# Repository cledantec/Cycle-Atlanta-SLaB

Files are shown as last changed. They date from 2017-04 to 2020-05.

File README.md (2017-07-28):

Cycle Atlanta: Seeing Like a Bike
================
[Atlanta's Data Science for Social Good (DSSG) 2017](http://dssg-atl.io/)
----------

The Cycle Atlanta project aims to create sensor systems that allow a bike to "see" its environment and collect data as a participatory effort to help the City of Atlanta make informed decisions about biking infrastructures. The team from Atlanta's Data Science for Social Good 2017 Summer program particularly worked on (1) reverse engineering all the prototypes developed separately by the LMC6650 team and consolidating all sensors into two microcontoller units (Raspberry Pi and Arduino) using the Master-Slave architecture; (2) identifying hardware/software bugs/flaws and refining systems iteratively; (3) implementing failure-tolerence techniques; (4) classifying environmental factors (to detect semantci-level objects) after collecting data using GoPro, voice recorders, and sensors; and (5) visualizing and analyzing the collected data using 3D models and machine learning techniques. 

## Documentations
* [System Overview](DSSG2017_doc/overview.md)
* [Hardware Systems (Electrical Devices and Circuits)](DSSG2017_doc/hardware.md)
* [Software Systems (Server Configurations and Scripts)](DSSG2017_doc/software.md)
* [Cases Design](DSSG2017_doc/cases.md)
* [Data Visualization (3D)](DSSG2017_doc/dataviz.md)
* [Data Analysis](DSSG2017_doc/data.md)
* [Backlog (Issues and Solutions)](DSSG2017_doc/backlog.md)

## Credits (DSSG)
### PI:
* [Dr. Christopher Le Dantec](https://ledantec.net/)

### DSSG Fellows:
* [Javier Argota](http://jard.us)
* [Myeong Lee](http://myeonglee.com)
* [Noel Mannariat](mailto:noelmannariat@gmail.com)
* [Erica Pantoja](mailto:ericapantoja1190@gmail.com)

### Special Thanks To:
* Dr. Kari Watkins
* Mariam Asad
* Bijan Tehrani
* Raj Lal
* Michael Vogel
* Bradley Rittenhouse

******

## [LMC6650: Seeing Like a Bike](http://ledantec.net/teaching/lmc-6650-spring-2017/)
### Spring 2017 Georgia Tech

LMC6650 students designed a custom PCB board for gas sensors, developed the Air Quality module and a data collection server on Raspberry Pi using RestAPIs, and implemented the proximity/serface quality sensor functionalities using Rapsberry Pi and Arduino. 

## Equipment used
* [Raspberry Pi](http://raspberrypi.org)
* [Arduino Uno](https://www.arduino.cc/en/Main/arduinoBoardUno)
* [Matrix One Creator](http://creator.matrix.one)
* [Anker 26800 mAh portable power bank](https://www.amazon.com/Anker-PowerCore-Portable-Double-Speed-Recharging/dp/B01JIWQPMW)
* [Knowles BU21771 contact microphone](www.digikey.com/product-detail/en/knowles/BU-21771-000/423-1004-ND/458515)
* Dimension ST768 for 3D printing

## Credits (LMC6650)
* **Air Quality team**: [Orianna Ott](https://www.linkedin.com/in/orianaott/) , [Lorina Navarro](https://www.linkedin.com/in/lmnavarro/) , [Reuben Fishback](https://www.linkedin.com/in/reuben-fishback-a4b31085/)
* **Proximity team**: [Sharon Ang](https://www.linkedin.com/in/sharon-ang/) , [Aastha Jalan](https://www.linkedin.com/in/aasthajalan/) , [Nikhil Soraba](https://www.linkedin.com/in/nikhil-soraba/)
* **Surface Quality team**: [Nene Igietseme](https://www.linkedin.com/in/nene-igietseme-19b65125/) , [Kristin Hare](https://www.linkedin.com/in/kristin-hare/) , [Shruti Dalvi](https://www.linkedin.com/in/shruti-dalvi/) , [Jayanth Mohana Krishna](https://linkedin.com/in/jayanthm)

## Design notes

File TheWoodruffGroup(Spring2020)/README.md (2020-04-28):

# Capstone SLaB [The Woodruff Group]
Documentation for work completed by The Woodruff Group for Spring 2020 Capstone

The goal of this Capstone project was to improve upon previous iterations of a data collection system which could be utilized by 
researchers to collect data about a biker's environment and stress levels during bike riding trials. The current project is broken down into three main categories as listed below.

## [Android App](Android%20App)
The Android App was developed in order to take advantage of the large amount of data a mobile phone is capable of reporting about its surroundings and movement. The main goal of the app is to collect time-stamped location data, speed data, and IMU data. The collected information is then written to a text file stored on the phone. The text file can be accessed from a computer and further analyzed.

## [Mechanical System](Mechanical%20System)

## [Electrical System](Electrical%20System)
The electrical system includes the sensors and other electrical components used, as well as the PCB that connects them all. The primary electrical components are a battery, a current sensor, a Teensy microcontroller, 4 LIDARs, and a Bluetooth communication module.

## The Woodruff Group
[Ibrahim Abdeally - iabdeally3@gatech.edu](mailto:iabdeally3@gatech.edu)  
[JP Almagro - jpalmagro97@gmail.com](mailto:jpalmagro97@gmail.com)  
[Matthew Bowen - matthew.bowen90@gmail.com](mailto:matthew.bowen90@gmail.com)  
[Aditya Ramanathan - aramanathan31@gatech.edu](mailto:aramanathan31@gatech.edu)  
[Carrie Wehmeyer - weh.carrie@gmail.com](mailto:weh.carrie@gmail.com)  
[Andy Zheng - azheng36@gatech.edu](mailto:azheng36@gatech.edu)

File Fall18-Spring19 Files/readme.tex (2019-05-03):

This file contains instructions for how to run slabScriptV1.py and compileData.py, as well as an overview of the arduino scripts. 

Instructions for Downloading Raw Data:
1. Go to the SLaB oneDrive Folder, then go to the Raw Data folder.
2. There are a lot of folders in the raw data folder, each containing all data from a specific SLaB box up until the date in the folder's name. The boxes are differentiated by their place in the lab (L for left, C for center, and R for right).
3. Download as much raw data as you need, making sure not to mix up data from different sensors. 
4. Make sure the raw data and whichever script you are running are in the same folder. The two scripts are stored (along with this readme) in the Scripts onedrive folder.
5. Move on to instructions for how to run the scripts. 

slabScriptV2: 
This is a script that takes in up to two sets of raw data for a single run and creates up to two output files that contain the air quality data. 

Instructions:
   1. Change the runDate variable below to the data you are getting data from. This should match
      the data in the data files, though it's not a problem if you switch the month and day or make
     other necessary changes. IMPORTANT: there is no check in place to make sure you entered the corrent
      runDate. The script will happily let you pull data from 09-11-18 with a runDate of 09-10-18,
      creating an output file named 09-10-18 with the data from the 11th. 

   2. Enter the first and/or second input files in the fields: input_files_one and input_files_two. The correct
      format is: input_files_one = ['090119_gps_data.json', '090119_proximity.json','090119_imu.log','090119_sensor.log']
      for example. If you only want to input files from one SLaB box then comment out the other line of input files
      and uncomment the line input_files_two = [] right below it. If the input_files_two variable is an empty array
      the code will move past it. 

   3. Run the code. Remember to SAVE first. If you are running this code in sumblime text, go to the Tools menu and
      click Build. If you are running this code in the commandline, navigate to the correct folder and enter
      python slabScriptV2.py

   4. If the code runs successfully, the output should look something like:

            Compiling Data from 01-09-19
            one complete
            two complete (or two ommitted if you didn't include a second set of data)
            Success
            [Finished in 0.2s]

   5. Finally, check the output file(s) to make sure they are what you expect, given the raw data files from the SLaB
      boxes.

compileData.py
This script takes in a single set of raw data file for a single run and creates an output file containing all data in json format for import into the database. It is important to remember to check the output of this script before putting it in the database. 

Instructions:
  1. Change the runID variable below to the following format: MM-DD-YYYYRunID_sensorNumber. The RunID 
     should be the route abbreviation (IP, etc) and the run number. The sensor Number should correspond with 
     the box the data is pulled off of (right = 1, center = 2, left = 3). The date should match
     the date in the name of in the data files, though it's not a problem if you switch the month and day or make
     other necessary changes. IMPORTANT: there is no check in place to make sure you entered the correct
     runID. The script will happily let you pull data from a piedmont park run on 09-11-18 with senor 1 with a runID 
     of 09-10-18IP1_2, creating a misleading data file. Though the timestamps in the file will still have the 
     right date and the gps coordinates will be unchanged, there is no way to identify which sensor was used from the data.

  2. Enter each input file into the list called input_files, following the example:
      input_files = ['040219_gps_data.json', '040219_proximity.json','040219_imu.log','040219_sensor.log']
     The script should be in the same folder as all four files, and all files should be from the same date.
     IMPORTANT: there is no check in place making sure the input files are from the same date.

  3. Run the code. Remember to SAVE first. If you are running this code in sumblime text, go to the Tools menu and
     click Build. If you are running this code in the commandline, navigate to the correct folder and enter
     python compileData.py . This script takes a little longer to compile than slabScriptV1.

  4. If the code runs successfully, the output should look something like:

           Compiling Data from <runID>
           Compiling GPS Data
           Compiling PROX Data
           Compiling IMU Data
           Compiling Sensor Data
           Success
           [Finished in 5.0s]

  5. Finally, check the output file(s) to make sure they are what you expect, given the raw data files from the SLaB
     boxes. Be sure to give the script a moment to completely finish, which you'll know once the BAK file appears.
     If you see lots of '?' in the file, the script has not finished. Things to look for: the timestamps incrementing 
     properly and the correct data matching up to the correct timestamp

  Known Bugs:
      1. the second } after the last entry in each section of the data is sometimes on the wrong line - this happens because
      the script expects the last line in each file to be unreadable (the norm) but this is not always the case. 

      2. entries in the raw data files will sometimes be preceeded by lines of <0x00> (a break in the data) 
      if a line follows a break in the data (is on the same line) and will be skipped by the script because it can't process it

      3. rarely, the increment in the imu data will be slightly too large and result in two rows with duplicate timestamps
         duplicate timestamps. An eary fix is to use a json checker and shift the first of the duplicates down by .001 to .999.

Arduino Scripts:
 TwoPMSsOrig: allows the arduino to take data from two PM sensors and print it all out to the console in a readable manner
 
 arduinoAll: does the same thing, but works with the SLaB box. In the event that you're building a box from scratch, the arduino_receiver.py file needs to be updated to work with this script. The updated script can be found on all three SLaB boxes.
 
 arduinoAllFinished: the same script as above, but cleaned up and with some comments. I ran out of time to do a just-in-case test on it so I'm uploading this copy as well as the original.

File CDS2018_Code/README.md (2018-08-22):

Cycle Atlanta: Seeing Like a Bike
================
[Civic Data Science at Georgia Tech]()http://civicdatascience.gatech.edu/2018/06/01/seeing-like-a-bike-2/
----------

The Cycle Atlanta project aims to create sensor systems that allow a bike to "see" its environment and collect data as a participatory effort to help the City of Atlanta make informed decisions about biking infrastructures. In Summer 2018, the Civic Data Science summer program focused especially on the challenges of collecting high quality pollution data from a mobile platform such as a bike. We focused mainly on evaluating the performance of low-cost air quality sensors, specifically the PMS5003, and comparing the results with a high quality sensor, the GRIMM Portable Aerosol Spectrometer.

## Credits (CDS)
### PI:
* [Dr. Christopher Le Dantec](https://ledantec.net/)

### CDS Interns:
* [Saumik Narayanan](mailto:naray114@umn.edu)
* [Nic Alton](mailto:alton.nic@gmail.com)
* [Urvi Latnekar](mailto:urvi.latnekar@bennett.edu.in)

### Special Thanks To:
* Dr. Kari Watkins
* April Gadsby
* Kanaad Deodhar

******

## Equipment and Software used
* [Raspberry Pi](http://raspberrypi.org)
* [Arduino Uno](https://www.arduino.cc/en/Main/arduinoBoardUno)
* [PMS 5003](https://aqicn.org/sensor/pms5003-7003/)
* [GPS Logger](https://play.google.com/store/apps/details?id=eu.basicairdata.graziano.gpslogger&hl=en_US)

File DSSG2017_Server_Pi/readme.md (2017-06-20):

# SLaB Server & Data store

This component runs the server on a RasPi that accepts data streams from the rear box (proximity and air quality) and the Matrix mounted on the handle-bars.

Installation 
============

Copy all files in the RaspberryPi directory to the home directory of the Raspberry Pi. Install dependencies for the Matrix and Flask (see install.sh):

```
sudo apt-get install python python3 python-pip nodejs
sudo pip install flask
curl https://raw.githubusercontent.com/matrix-io/matrix-creator-quickstart/master/install.sh | sh
```

* We will be using the MALOS abstracted layer on Matrix, here: https://matrix-io.github.io/matrix-documentation/MALOS/overview/ 
* Python Flask runs as the server, and accepts a JSON payload
* The server automatically time-stamps POSTed data and appends the sensor name based on what endpoint was contacted.

To run:

```
sudo python -m <path>/server.python
```

Server endpoints
----------------
| **Endpoint**  | **HTTP Method** | **Data** |
|---|---|---|
| /getstatus | GET | Returns LED status |
| /status | POST | Gets various sensor statuses |
| /proximity | POST | Gets proximity data |
| /inertial | POST | Gets inertial data |
| /humidity | POST | Gets humidity data |
| /uvindex | POST | Gets ultraviolet data |
| /prestempalt | POST | Gets pressure, temperature, altitude data |
| /gas | POST | Gets gas array data |
| /gps | POST | Gets GPS data |

Data store
----------
Data received by the server is stored in this format:
```{
 ‘sensor’: ‘sensor_name’,
 ‘timestamp’: ‘YYYY-MM-DD HH:MM:SS.ssssss’,
 ‘data’: {sensor_payload}
 }
 ```

Future work
-----------
* Send data to MongoDB instead of plain text file (better size and filtering)
* Write services to retrieve data based on filters

Command-line Autostart and Auto Triggering of Shell Scripts
---------
- cd /etc/systemd/system/autologin@.service
- Change line: ExecStart=-/sbin/agetty --autologin pi --noclear %I $TERM
- Auto Triggering Shell Scripts
	- Comment out the line in “LXDE-pi” since it works for GUI mode ```sudo nano ~/.config/lxsession/LXDE/autostart```
	- In “/etc/rc.local”, put the line ```/home/pi/startup.sh @```

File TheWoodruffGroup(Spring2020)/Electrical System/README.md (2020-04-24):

# Electrical System Documentation
The electrical system includes the sensors and other electrical components used, as well as the PCB that connects them all. The electrical components include:
- 1x [Anker 5000 mAh Battery](https://www.anker.com/products/variant/powercore-5000/A1109011)
- 1x USB-A male-to-male cable
- 1x [Stewart Connector USB-A port](https://www.digikey.com/product-detail/en/stewart-connector/SS-52100-001/380-1412-ND/7902377)
- 1x On/Off Switch
- 1x Current Sensor
- 1x [Teensy 4.0 Microcontroller](https://www.pjrc.com/store/teensy40.html)
- 4x [Garmin LIDAR-Lite v4 LEDs](https://buy.garmin.com/en-US/US/p/610275)
- 1x [Adafruit Bluefruit UART Friend](https://www.adafruit.com/product/2479)
- 2x 1.5 kΩ (pull-up) resistors
- 1x 680 μF capacitor

The current PCB was designed in Eagle 9.6.1. Since Georgia Tech's [Electronics Lab](http://www.me.gatech.edu/facilities/electronic_lab) uses Eagle, PCBs can typically be manufactured within a day of the request if Eagle \*.brd files are submitted. For information on PCB design, I recommend [this tutorial by Brian Benchoff at Hackaday](https://hackaday.com/2016/09/22/making-a-pcb-eagle-part-1/). 

## Overview of Components
### Anker 5000 mAh Battery
This battery provides power to the Teensy and all of the components; it was sized based on the estimated current consumption of the device. It was calculated that the system will draw about 442 mA of current (2 mA from Bluetooth, 85 mA from each LIDAR, 100 from Teensy), so for a half-hour ride, only 221 mAh would be needed. Anker's 5000 mAh model was selected as the smallest and cheapest option, but other options may also be viable. The battery comes with a Micro-USB cable included for charging, but the micro-USB ports that I could find all seemed too small to easily solder to a PCB, so the board has a USB-A ("normal" USB) port instead, which are easier to solder, and still cheap & easy to find. Although the Teensy has a micro-USB port on it for power, connecting directly to this would make it impossible to measure the current draw, as the current sensor must be placed in series with the power source, so power must be provided through a separate USB port. 
The battery has a minimum current draw of 50 mA. We believe that the system will draw more than that, but **this would need to be verified experimentally**. 

### USB-A male-to-male cable
Since the board uses a USB-A port, a separate USB cable must be purchased to connect the battery to the board. A smaller cable would likely be best to prevent tangling. 

### Stewart Connector USB-A port
A USB-A port was chosen instead of a Micro-USB port because they appeared to be much easier to solder to a board, but any type of USB port should work, likely requiring changes to the footprint in the PCB file. This specific port was chosen because it was the cheapest one I could find on Digi-Key, but again, any USB port should work. 
The datasheet for this part did not specify which pin corresponded to what signal, so it had to be extrapolated based on similar connectors. **It needs to be verified experimentally which pin corresponds to 5V and which pin corresponds to ground**. 

### On/Off Switch 
This is a simple power switch to turn the device on or off, so that the battery power can be conserved when not in use. Any switch that holds its state and has leads attached to it can be used. Something like [this](https://www.adafruit.com/product/1092) would be fine, but the possibility of accidentally toggling the switch should be considered too, so a sliding switch might be better. The switch itself would be on the housing, and the leads coming off it would be soldered to the board. 

### Current Sensor 
The current sensor is used to estimate the current battery level by numerically integrating the current consumed over time. We never had the opportunity to test the current sensor, so everything involving it is entirely theoretical, including the wiring. The one used in the PCB is [this one from Allegro MicroSystems](https://www.digikey.com/product-detail/en/allegro-microsystems/ACS750LCA-050/ACS750LCA-050-ND/1006488), a default option provided in Eagle, which is now discontinued. It appears to have the same footprint as [this one](https://www.digikey.com/product-detail/en/allegro-microsystems/ACS770LCB-050B-PFF-T/620-1541-5-ND/4473980), which is still active. These current sensors may be bigger than we need, as they can sense up to 50 A of current, and the voltage outputted from them might be too low to be accurately read by the Teensy. **It may be better to use a different current sensor that is more suited to the range of currents being measured, and if the voltage is still too low, it may be best to amplify it with an op-amp.** It is also possible to calculate current by placing a small known resistor in series with the power source, where the current sensor would go, and measuring the voltage across it, but it is unclear how accurate this would be, and how much this would change the dynamics of the circuit. 

### Teensy 4.0 Microcontroller
This is the microcontroller that manages all of the sensors. It is faster and more powerful than an Arduino Uno, and should be fast enough to handle all the data being gathered. User-made Eagle libraries for the Teensy can be found [here](https://www.pjrc.com/teensy/eagle_lib.html), and the one used in this design is [the one by Constantin](https://forum.pjrc.com/threads/935-Eagle-library-with-Teensy-3-0-footprint?p=20178&viewfull=1#post20178) ("Teensy_3_and_LC_Series_Boards_v1.4.zip"). The Teensy 4.0 has largely the same pinout as the Teensy 3.2 and 3.1, so the Teensy 3.2/3.1 board available in the library is the footprint used in this design. The pins that are used all seem to be the same between 4.0 and 3.2, but **the wiring should be verified experimentally**. 

### Garmin LIDAR-Lite v4 LED
The LIDAR is used to measure the distance to various objects in the environment. Using multiple LIDARs, the speed of passing objects can be calculated. If two LIDARs are placed facing to one side of the bike with a known distance offset in the direction of motion, then the lag between the signals that the two LIDARs read can be used to calculate the speed of the passing object relative to the speed of the bike. This lag can be calculated with cross correlation, with the MATLAB function [xcorr()](https://www.mathworks.com/help/matlab/ref/xcorr.html), or the NumPy function [np.correlate()](https://numpy.org/doc/1.18/reference/generated/numpy.correlate.html), The distance between the LIDARs divided by the time lag between the signals is the speed of the passing object, relative to the bike. With an accurate measurement of the bike speed, coming from the app, the speed of the passing object relative to the ground can be calculated. Tests were done with the previous iteration of this device, [the v3](https://buy.garmin.com/en-US/US/p/557294), and it did not seem to be accurate enough, although only one device was tested. Regardless, it was decided to use the v4 because, according to the specs, it is more accurate, cheaper, and uses less power than its predecessor, however no tests could be done with it. The LIDARs communicate via I2C, and each one needs a different I2C address for proper communication. This can be done programatically with the [LIDAR-Lite Arduino Library](https://github.com/garmin/LIDARLite_Arduino_Library). The wiring was done based on their [specs sheet](http://static.garmin.com/pumac/LIDAR-Lite%20LED%20v4%20Instructions_EN-US.pdf) and comments in their example code, including the two resistors and the capacitor, so **it all needs to be verified experimentally**. 

### Adafruit Bluefruit UART Friend
This is the Bluetooth communication module that establishes a connection with the phone to send LIDAR data. It is not currently in the PCB as we had difficulties with reliably sending/receiving data. **Much more testing needs to be done with Bluetooth.** This device uses the Bluetooth Low Energy protocol, which is distinct from conventional Bluetooth. All the necessary information for this device can be found at the link above. 

## PCB design info
### PCB Files
There are 3 custom library files (\*.lbr) included in this folder: one for the LIDAR, one for the USB, and one for the Teensy. The Teensy library is the one mentioned above, and the other two are simple ones that I made, as I couldn't find EAGLE files for them online. The .brd file is the PCB layout, the .sch file is the schematic, and the .step file is a 3D model used in the CAD. 
### LIDAR Connection
The LIDAR footprint is just 10 holes in two rows spaced 0.1" apart, since the LIDAR itself doesn't have any method of connecting to a board. A port like [this](https://flytron.com/connectorscables/254-10-pin-isp-male-connector-header.html) could be soldered on, and then a ribbon cable soldered to the LIDAR with a plug on the other side could be used to easily connect to the board.

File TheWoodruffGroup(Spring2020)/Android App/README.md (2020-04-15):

# Android App
The Android app is responsible for collecting location data, speed, and other phone sensor data. Several methods of obtaining a 
phone’s location were tested. For Android devices, the two main ways of obtaining device location are through using 
Android Location Manager (ALM) or Google Play Services’ Fused Location Client (FLC). ALM utilizes GPS, network providers, and 
passive providers. This includes using satellites, cell towers, and locations determined by other applications. FLC is built on 
top of ALM. FLC automatically chooses the best provider for the device’s location and is in turn much quicker to update and log a 
device’s location. Comparing the two, FLC provided more accurate data with less lag. The current app utilizes FLC to report the 
phone's location and speed. The app has been tested on a Samsung Galaxy S10 and is currently named "SLaB".

The app features two modes which both record data. The main screen is meant to be utilized during experiments and test rides. This
screen displays the essentials for the app:
- Data Logging Status: Reports whether the app is currently able to write data to a text file.
- Audio Recording Switch: Switch to enable or disable optional audio recording. Must be set before logging data.
- Button Counter: Senses when the volume-up button is pressed.
- Relevant Location Data: Displays time, latitude, longitude, speed(mph), and altitude(ft).
- Counter: Counts the number of data points that have been recorded. Used to determine if data is being written to text file.
- Log Data Button: Large button pressed to being data logging. Disables audio recording switch and developer mode button.
- Developer Mode Button: Text that shows developer mode when pressed.

Developer mode has the same functionalities as the main screen but displays all data that is recorded. This extra data includes:
- Gyro Data
- Accelerometer Data
- File location
- Location accuracy data

While the main screen does not display these, they are still recorded and written to the stored text file.

## Build Environment
- The current app was developed using Android Studio 3.5.3. 
- The app has been tested on a Samsung Galaxy S10 with Android verison 10.
- Compile SDK version: 29
- Build Tools version: 29.0.3
- Application Min SDK version: 15
- Application Target SDK version: 29
- Application ID: "com.woodruff.SLaB"

## Dependencies
- implementation 'com.google.android.gms:play-services-games:19.0.0'
- implementation 'com.google.android.gms:play-services-location:17.0.0'

## Permissions
- "android.permission.BLUETOOTH"
- "android.permission.BLUETOOTH_ADMIN"
- "android.permission.INTERNET"
- "android.permission.ACCESS_FINE_LOCATION"
- "android.permission.ACCESS_COARSE_LOCATION"
- "android.permission.RECORD_AUDIO"

## Data Collected
Currently, the data collected includes:
- GPS Location - Longitude and latitude coordinates
- GPS Speed - Speed data as reported by the phone GPS, currently in mph
- GPS Altitude - Altitude data as reported by the phone GPS, currently in ft above the WGS 84 reference ellipsoid
- Accelerometer Data - Acceleration force in x, y, and z directions, currently in m/s<sup>2</sup>
- Gyroscope Data - Rate of rotation around x, y, and z axes, currently in rad/s
- Location Accuracy - Estimated horizontal accuracy of the location reported, currently in ft radially
- Speed Accuracy - Estimated speed accuracy as reported by the phone, currently in mph
- Altitude Accuracy - Estimated accuracy of the altitude reported, currently in ft
- Time - The time at which each data point was collected [yyyy-MM-ddTHH:mm:ss.SSS]

## File Location and Data Storage Format 
### File Location
The data collected by the app is written to a text file that is time stamped for when the file is created, or when data collection began.
Currently, the files are stored on the phone within the app's data folder in internal storage. To access the files, the "MyFiles" app on an Android phone 
can be used, or the phone can be connected to a computer and the file opened on a computer.

The files is located at: **Interal storage\Android\data\com.woodruff.SLaB**. Within the files folder, there are two folders for 
which data collected on the main mode and debug mode are stored. The folder "FLC Trip Data" contains data collected on the main screen,
while the folder "FLC Trip Data_Debug" contains data collected while in developer mode. Optional audio recordings are also stored
in these folders depending on which screen they are recorded from.

### Data Format in File
The data log file is a .txt file. The first line of the text file is a header which describes what data is collected and in what 
order the data is written to the text file. The data is comma-delimited, with each data point being time-stamped. Currently, 
the format is (Time,Latitude,Longitude,Dist_Acc,Speed,Speed_Acc,Altitude,Alt_Acc,Gyro_X,Gryo_Y,Gyro_Z,Accel_X,Accel_Y,Accel_Z).
The optional recordings are stored as mpeg4.

## Bluetooth
Initial testing was done to determine if Bluetooth(BT) could be used to send data between a BT module and a phone. The app created for testing is named "Blueteeth GATT". The BT module used for testing was the [Adafruit Bluefruit LE UART Friend](https://www.adafruit.com/product/2479). This BT module utilizes [Bluetooth Low Energy](https://developer.android.com/guide/topics/connectivity/bluetooth-le) instead of conventional Bluetooth. This involves using a GATT profile to send attributes over a BLE link. 

### Connecting Devices
Normally, the app would need to scan for BLE devices, pair, and connect before sending data. However, for the current app, the module is manually linked in the phone's BT settings before testing. 

### Bluetooth Adapter
A Bluetooth Adapter is required for BLE activity. In the main activity:

`private BluetoothAdapter bluetoothAdapter;`  

And within the onCreate method:

`bluetoothAdapter = bluetoothManager.getAdapter();`

Then app checks that Bluetooth is enabled and that a connection with the BLE module is established. If not, a request should be made for the user to enable BT and connect to the BT module: 

```
if (bluetoothAdapter == null || !bluetoothAdapter.isEnabled()) {
    Intent enableBtIntent = new Intent(BluetoothAdapter.ACTION_REQUEST_ENABLE);
    startActivityForResult(enableBtIntent, 0);
}
```

### GATT Connection
Next, the app checks that the correct module is connected. If the module is the "Adafruit Bluefruit LE" module, a connection is made to the GATT server on the BLE device and a [BluetoothGattCallback](https://developer.android.com/reference/android/bluetooth/BluetoothGattCallback) is used to perform operations:

```
pairedDevices = bluetoothAdapter.getBondedDevices();
if (pairedDevices.size() > 0) {
    for (BluetoothDevice device : pairedDevices) {
        if(device.getName().equals("Adafruit Bluefruit LE")){
            statusBox.setText(device.getName());
            BluetoothGatt BTGatt = device.connectGatt(this, true, gattCallback);
        }
        else{
            statusBox.setText("Plz Connect to Bluefruit");
        }
    }
}
else{
    statusBox.setText("No Connected Devices");
}
```

### Bluetooth GATT Callback
The GATT callback uses several methods to perform BT operations. The `onConnectionStateChange()` method can be used to check that a successful GATT connection was made and start discovering services:

```
public void onConnectionStateChange(BluetoothGatt gatt, int status, int newState) {
super.onConnectionStateChange(gatt, status, newState);
if(status == BluetoothGatt.GATT_SUCCESS && newState == BluetoothProfile.STATE_CONNECTED){
    try {
        Thread.sleep(500);
    } catch (InterruptedException e) {
        e.printStackTrace();
    }
    gatt.discoverServices();
}else if(status != BluetoothGatt.GATT_SUCCESS){
    gatt.disconnect();
}
}
```

Sometimes it is useful to have the thread sleep for 500 ms before beginning service discovery to ensure the GATT connection is made.

The `onServicesDiscovered()` method can be used to get the service from the BLE device as well as read and write characteristics using from the service. The service, read characteristic, and write characteristic have different UUIDs that are specific to the BLE module. These UUIDs are used to get the correct service and characteristic in order to communicate and perform operations with the BLE module:

```
BluetoothGattService BTservice = gatt.getService(UUID.fromString("6e400001-b5a3-f393-e0a9-e50e24dcca9e"));
BluetoothGattCharacteristic WriteCharacteristic = BTservice.getCharacteristic(UUID.fromString("6e400002-b5a3-f393-e0a9-e50e24dcca9e"));
BluetoothGattCharacteristic ReadCharacteristic = BTservice.getCharacteristic(UUID.fromString("6e400003-b5a3-f393-e0a9-e50e24dcca9e"));
```

To **send data to** the BLE module, the value of the write characterstic can be set and then written:

```
WriteCharacteristic.setValue("ASDFJKL");
gatt.writeCharacteristic(WriteCharacteristic);
```

To **receive data from** the BLE module, a characterstic notification must be set and enabled with the Bluetooth Descriptor:

```
gatt.setCharacteristicNotification(ReadCharacteristic,true);
BluetoothGattDescriptor descriptor = ReadCharacteristic.getDescriptor(UUID.fromString("00002902-0000-1000-8000-00805f9b34fb"));
descriptor.setValue(BluetoothGattDescriptor.ENABLE_NOTIFICATION_VALUE);
gatt.writeDescriptor(descriptor);
```

With the notification set, once a characteristic change is detected, the `onCharacteristicChange` method will be called. The incoming data can then be extracted and displayed or saved. 

```
public void onCharacteristicChanged(BluetoothGatt gatt, BluetoothGattCharacteristic characteristic){
  String inputText = characteristic.getStringValue(0);
 }
```

## Running the App
### Enabling USB Debugging
In order for the app to install on an adroid device from Android Studio, USB debugging must be enabled in the developer options on the phone. Normally, developer options are not shown. 

- If using an Android phone, go to Settings > About phone > Build number. 
- On a Samsung Galaxy device, go to Settings > About phone > Software information > Build number. 
- On an HTC device, go to Settings > About > Software information > More > Build number. 
- On an LG device, go to Settings > About phone > Software info > Build number.

Tap Build number seven times. After a few taps, steps counting down until developer options are unlocked should appear. Once activated, go back to Settings and developer options should be at the bottom of the menu. Under "Debugging" in the developer options, enable "USB debugging".

### Installing the App
To install the app on an Android device, connect the android device to a computer with Android studio running. If the device is connected and developer mode is enabled, the phone should show in a tool bar at the top of Android studio.



Simple click the green "Run" button to install the app on the phone.

### Enabling Permissions
To run the "SLaB app, location and mircophone permissons must be granted for the app. These can granted in the phone settings under apps. For the "Blueteeth GATT" app, make sure Bluetooth for the phone is enabled and the correct Bluetooth module is connected.

### Using the App
Once permissions are granted, the app should be functional. 
- To record data, simple press the "LOG DATA" button. 
- To enable audio recordings, switch the "Audio Record" to the on position before starting data collection. 
- To enter developer mode, press the text at the bottom. 
- To go back to the main screen from developer mode, use the back arrow at the top of the screen.

## Future Work
Future work for the app should focus on integrating Bluetooth functionality into the main "SLaB" app.

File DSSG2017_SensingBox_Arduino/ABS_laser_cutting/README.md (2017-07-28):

# ABS laser cutting

The files in this folder have no border. They are intended for being used directly for laser-cutting the ABS boxes. The box should be placed on the laser cutter bed with the face to be cut facing up, and with the opening facing right. The location of the box should be always on the top leftmost corner of the laser cutter. The file is set for being using the setting of 12 x 18 inches paper on the printer dialog from Illustrator. For getting the versions with the edges used for wooden cut, they are available in the folder “old”. The parameters of the cutting and engraving can change as the laser cutter has some sort of inconsistent behaviour. As general approach, for ABS, it is better several (around 10) quick passes which rather than a slow and powerful laser which can melt and damage the box. Engraving is only necessary in the front part. A test file is provided for checking different patterns on the ABS.

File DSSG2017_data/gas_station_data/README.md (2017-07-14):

Gas Station Data for Sensor Calibraition
=========
Myeong Lee (myeong@umd.edu)
-----

This data is collected at the Atlanta Sensing Station located at the Atlanta Power by co-locating our sensors.
The timestamps of the data are not correct since we used Linux time in Raspberry Pi. The actual time range that the data was collected is from July 12th 8:50 AM to July 14th 8:20 AM (approximately). The data was collected every 2 seconds in the code, but it is not exactly 2 seconds due to the data collection time lag (so a bit more than 2 sec), so the time interval in the data timestamp can be 2 or 3 seconds (but their actual intervals are same). 

The sensors needs to be calibrated using official sensor data from the sensing station. Also, temperature and humidity needs to be taken into account since these factors affect gas sensor readings. The official data is provided by Raj Lal, a Ph.D. student from the department of Environmental Science.

For the calibration data collection, we used only three sensor boards (#1, 4, 7), since these are only sensors that showed stable signals out of all the fabricated sensors (so, each entry in the dataset shows three sets of sensory data). The rest of the sensors that were not placed for calibration needs to be further debugged or replaced.

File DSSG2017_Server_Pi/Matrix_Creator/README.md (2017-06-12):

# Matrix Creator Files

These files are running on Raspberry PI to run sensors on the Matrix board.

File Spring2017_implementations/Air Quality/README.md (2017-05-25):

# Air Quality & GPS Sensor readme

Code for running air quality and GPS sensors. 

Installation 
============

Copy all files in the RaspberryPi directory to the home directory of the Raspberry Pi.
Install the Adafruit Python DHT and ADS1x15 libraries in the 'dependencies' directory (see README there for details—you will need an active network connection to install their dependencies).

To run:

```
sudo python ~/air_quaility/aq_init.py
```
To autorun, edit the ~/.config/lxsession/LXDE-pi/autostart file by adding:

```
@python /home/pi/airquality/aq_init.py
```

Old Code
--------
Located in the 'unused' directory, these source files aren't used or were renamed for production.

*AirMaster.py*
Contains all the relevant code from the other three python scripts.
It also connects to the server and sends JSON data every 4-5 seconds.

The following three files are test scripts
Once each was working the code was added to AirMaster.py

*USBserial.py*
This script will initialize and read from the USB port.

*serial_read.py* 
This script will read from the GPS that is connected to the tx and rx 
lines. It also isolates the desirable data and parses it out.

*i2c.py*
This code will use the Adafruit Python DHT library to read i2c.
It will also scale the values in an attempt to convert them to ppm.

*DustSensor.ino* 
This is arduino code that runs on the teensy arduino.
Reads analog value from PM sensor every second and sends over USB

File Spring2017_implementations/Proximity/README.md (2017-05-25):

# Raspberry Pi code

Python code for collecting proximity data, storing on the drive and sending status,data over the network.

Installation 
============

Copy all files in the RaspberryPi directory to the home directory of the Raspberry Pi.
Note: Include all the other files in the folder (the lidar_lite module) for the script to run successfully.

To run:

```
sudo python ~/proximity/proximity_init.py
```
To autorun, edit the ~/.config/lxsession/LXDE-pi/autostart file by adding:

```
@python /home/pi/proximity/proximity_init.py
```

# Arduino code

Refer to sensorAggregate.ino under Arduino folder. This will run all four sensors (2x Lidar Lite, 2x ultra-sound).

# Data Analysis

For a sample analysis of proximity data, run the file giveSummary.py from the directory where the data files are stored. By default, this path is /home/pi/data/
*Note: may not work as data file format has changed (from flat csv to json).*

Typical ouput expected is:

*Trip 1 Summary*
Number of parked cars: 0
Number of parked trucks:0
Approx. number of pedestrians / other short obstacles: 0

*Trip 2 Summary*
Number of parked cars: 6
Number of parked trucks:1
Approx. number of pedestrians / other short obstacles: 50

*Trip 3 Summary*
Number of parked cars: 14
Number of parked trucks:3
Approx. number of pedestrians / other short obstacles: 86

*Trip 4 Summary*
Number of parked cars: 12
Number of parked trucks:2
Approx. number of pedestrians / other short obstacles: 97

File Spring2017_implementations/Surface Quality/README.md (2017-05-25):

# Surface Quality Sensor readme

Code for running surface and environmental sensors from the Matrix.

Installation
============
Copy all files in the RaspberryPi directory to the home directory of the Raspberry Pi. Follow installation instruction of the Server—this runs on the same mdule.

To run:

```
node test_imu_server & node test_humidity_server & node test_pressure_server & node test_uv_server & node test_everloop_server
```

For auto start, edit thee ~.config/lxsession/LXDE-pi/autostart file to include: 

```
@bash /home/pi/startup.sh
```

Note: startup.sh also starts the Server.

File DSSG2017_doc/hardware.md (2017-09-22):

Hardware Systems
=======
### <span style="color:grey">Table of Contents</span>

1. [Securing Raspberry Pi and Matrix](#matrix)
2. [GPS](#gps)
3. [Pi-to-Arduino Communication](#commo)
4. [Arduino and Sensor Connections (Bridge Board)](#arduino)
5. [Gas Sensors](#gas)
6. [Sensor Box Design](#box)

## Securing Rapspberry Pi and Matrix
Even though the connection between Pi and the Matrix board is sturdy, Matrix Creator can be detached from the Pi board when shaking a lot during the riding. This led us to secure the Matrix board by tying them through Matrix holes. We used two pieces of wires to secure them. Also, to prevent the shocks between the Pi board and the Matrix board, we put a small piece of Yoga matt between them. Several tests showed that this is a very secure way to make them safely operate. 

## GPS Fabrication
Our GPS system consists of a GTPA010 device, a CP2102 USB-to-TTL device, and a small piece of PCB board. As you can see in the picture below, we connected the GPS module to the CP2102 device directly, and used a piece of PCB board as an intermediate bridge. This unit is finally attached to Pi's USB port. 

The reason that we do this is that while the GPS module uses a serial communication as a means to talk to other devices, the USB port of the Pi board is *NOT* a serial port. So, it is necessary to convert "serial communication" signals to TTL (Transistor-Transistor-Logic) signals that USB ports use. The software part for making use of this GPS module is available at [the software system document](software.md).

It is easy to make mistakes when connecting the pins and it is so hard to unsold them especially when you have already finished it, so pay attention to the connection during all the time of soldering. 

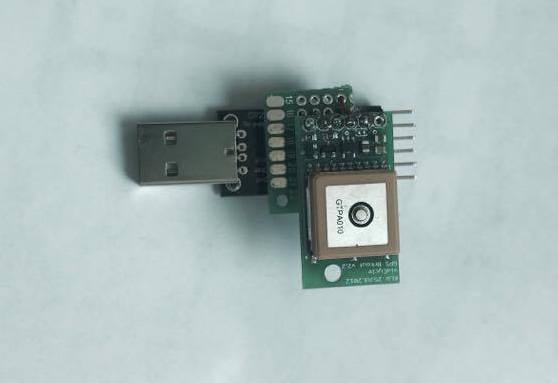
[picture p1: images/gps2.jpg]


The **connections of pins** are as follows. Please note that GTPA010 **DOES NOT** use 5V for VDD, but use 3.3V that comes out of a small pin in the CP2102 device. 

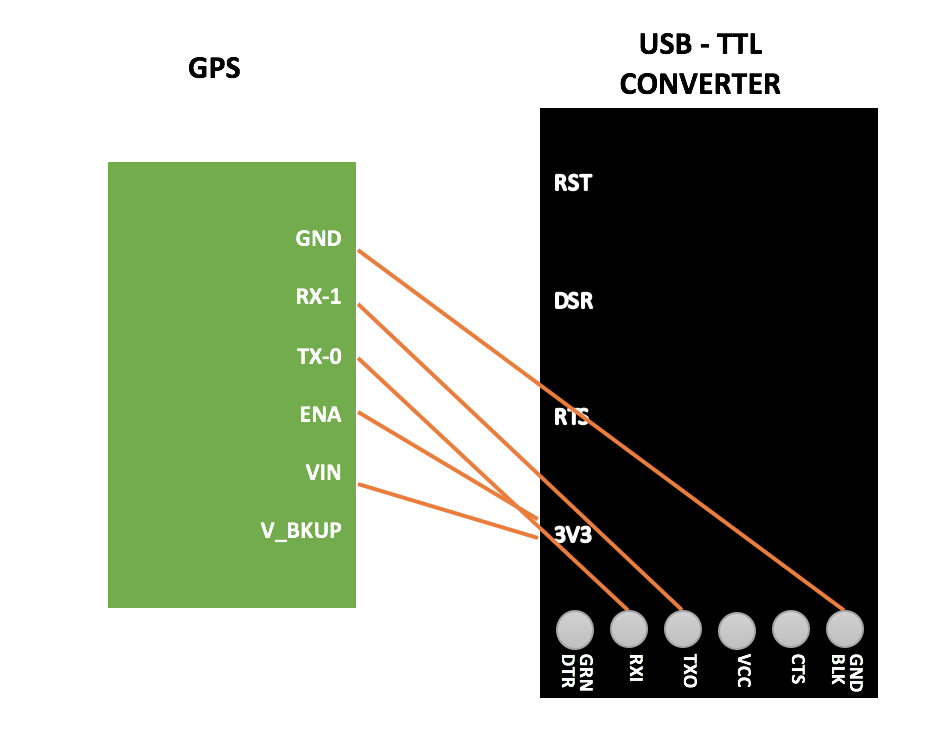
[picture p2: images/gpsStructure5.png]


The code uses the default settings of the GPS and returns the following data: **course**, **longitude**, **latitude**, **speed**, **day**, and, **utc_time**

## Pi-to-Arduino Communication
From the outside view, the Master Unit, particularly the Raspberry Pi, and the sensor box are connected through a male-to-male USB cable. Similar to the GPS module, however, the Pi uses a TTL signal for its USB while the Arduino board uses serial signals. So there is another USB-to-TTL device inside the sensor box on the back side. The brand of this USB-to-TTL device is different from the GPS one. Arduino's serial data swings between 0V to 5V while TTL signals swing between 0V and 3.3V. The USB-to-TTL device in the sensor box automatically deals with this power change. However, we do not use VDD between the Pi and Arduino since each of them uses its own power for data signals. Thus, only three wires, i.e., TX, RX, and GND, are connected through the USB-to-TTL device. 

**Note that TX from the USB-to-TTL device is connected to the RX of Arduino, and vice versa.**

## Arduino and Sensor Connections (Bridge Board)
From the hardware perspective, the connections of the sensors to the Arduino board is made through a shield/bridge-board mounted on top of the Arduino.

The documentation for the wiring of the box has been designed using Fritzing, common software in the Arduino and Raspberry Pi community. It can be downloaded for free from [its website](http://fritzing.org/home/). Additional parts libraries may be required depending on the particular version of the program, but they can be add *ad hoc* from the own program. It is particularly important for being able to use LIDAR or thrid-party components not that common for Arduino users.

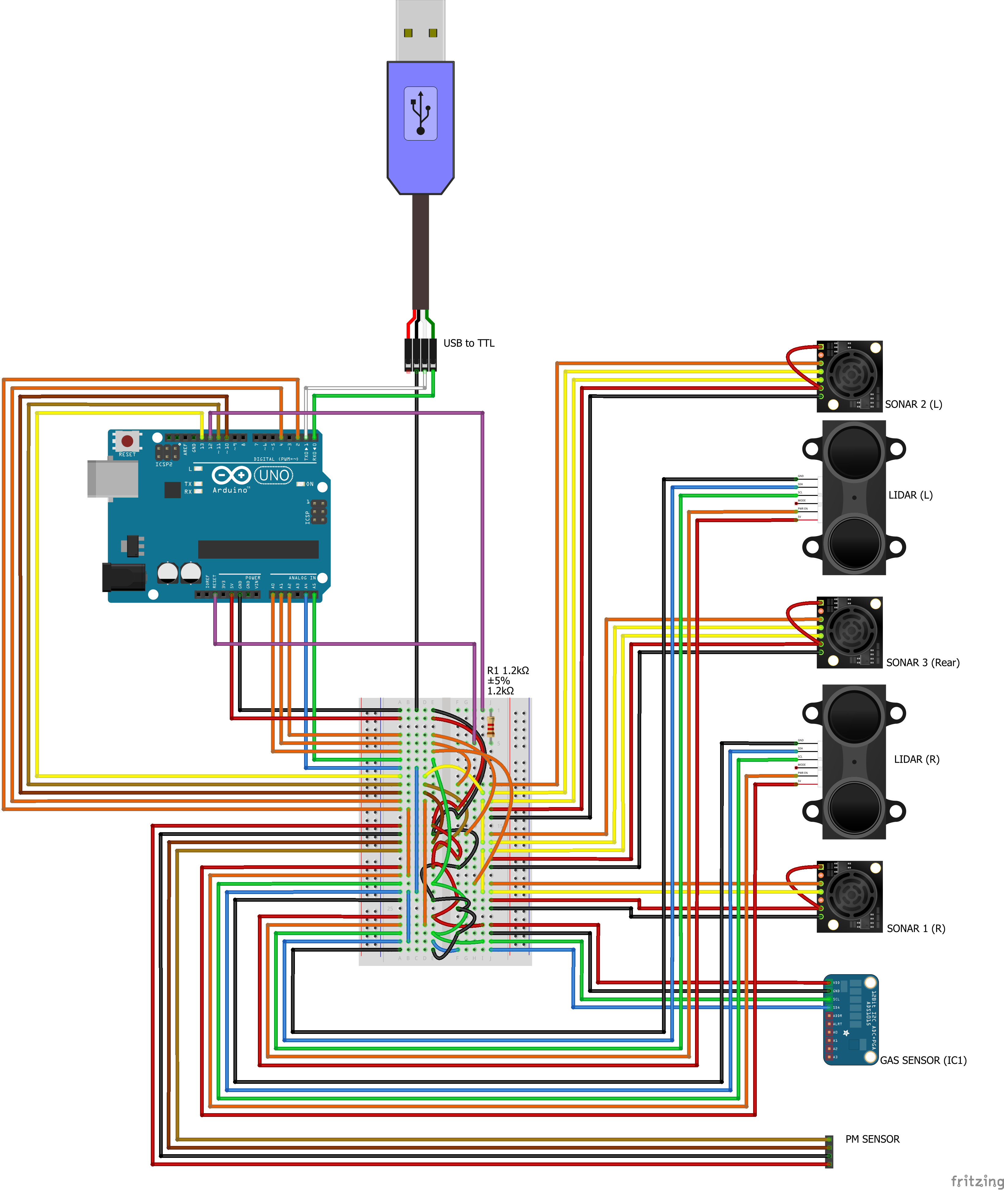
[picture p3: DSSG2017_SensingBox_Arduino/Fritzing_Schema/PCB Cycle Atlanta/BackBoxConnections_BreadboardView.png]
BreadboardView

*Breadboard view of the connections*

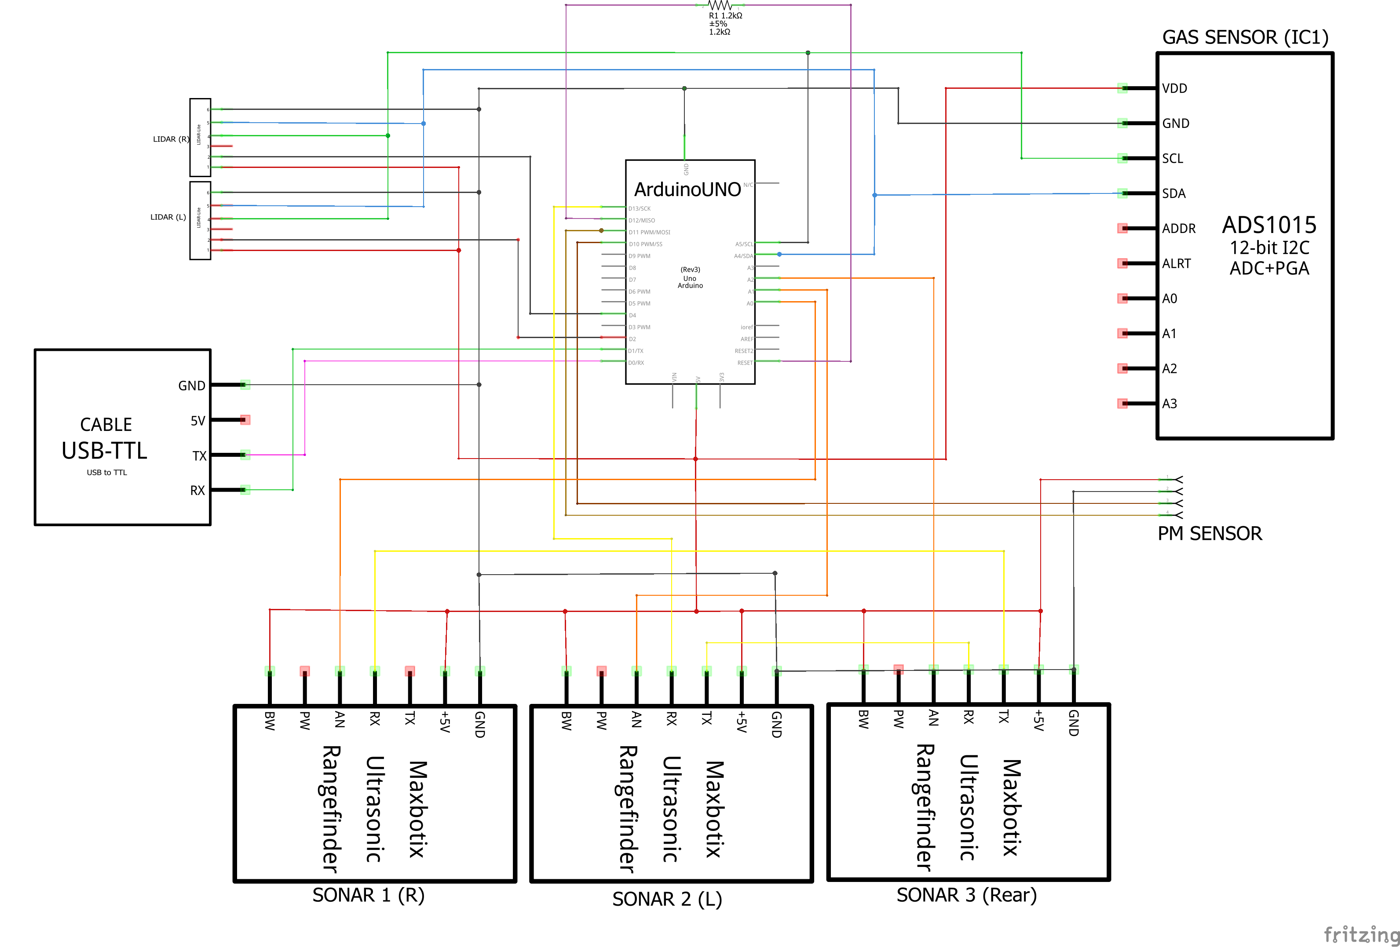
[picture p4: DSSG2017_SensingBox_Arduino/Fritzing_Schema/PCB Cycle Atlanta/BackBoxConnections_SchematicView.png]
SchematicView

*Schematic view of the connections*

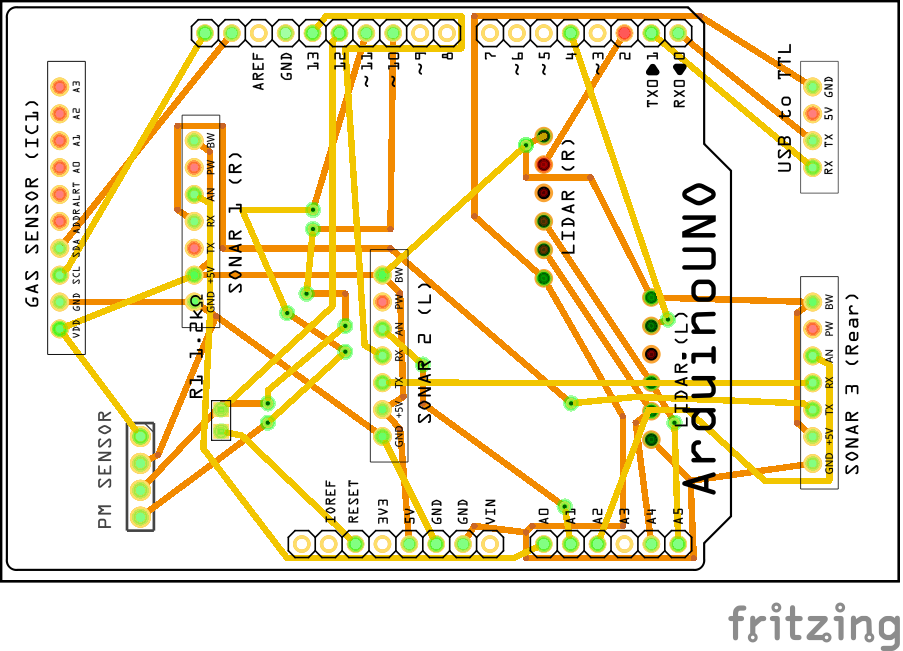
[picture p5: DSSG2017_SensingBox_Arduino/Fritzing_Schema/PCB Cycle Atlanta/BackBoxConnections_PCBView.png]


*PCB view of the connections (2-layer Design)*

The original Fritzing file for editing and designing a custom PCB board in the same software can be found [here](https://github.com/cledantec/Cycle-Atlanta-SLaB/raw/master/DSSG2017_SensingBox_Arduino/Fritzing_Schema/PCB_BackBox_2layers.fzz) for downloading. Original bridge boards were completely wired manually, although a custom PCB would be highly advisable in the future.

## Gas Sensors
We made use of the following gas sensor design from the Spring 2017 team.

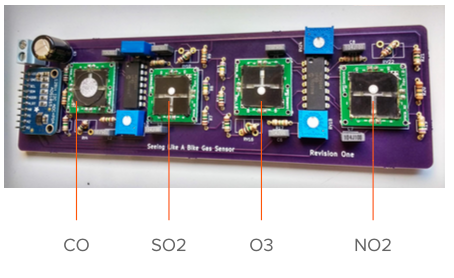
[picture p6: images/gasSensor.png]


#### Observations and Try-and-Error Refinements

1. The holes for resistors in the gas sensor boards are small and different sizes, it was so hard to push the lead of the resistors down, and for those resistors which did not fit into the holes we replace them with smaller resistors different in voltage. For instance, we replaced the 560 K Ohms resitor with 470 K Ohms resitor. This replacement worked fine. 

2. Gas sensor board's behaviour are not consistent. Three out of seven fabricated boards (#1, 4, 7) works fine, and the rest of them has a flaw in at least one sensor. Detailed information about each of the seven sensor boards is found [here](https://docs.google.com/spreadsheets/d/18mLQVb0HjoA-88Tq4y8rYqyIrmJ9yjPXizwVc3SuRZM/edit?usp=sharing).

#### Circuits
A raw value from ADC is a 12-bit reading of voltage status when the power supply is from 0 to 5V. Since an OP-AMP supplies 2.5V as the ground voltage to the final amplifier, the 12-bit value comes out of the range between 0 and 2.5V. So, the raw values can vary, theoretically, between 0 to 2048 where 0 means 0V and 2048 means 2.5V. Even if all the circuit settings and sensor type are same, however, the baseline voltage that comes out of each sensor can vary. Thus, it is required to figure out the baseilne values when none of the target gases exists. 

**Baseline Calibration** In order to get the baseline values of all sensors, we used Wine Preserver Gas in a vacuum bag. First we made a gas sensor testbed that can connect up to three gas boards (using different addresses). The Arduino code for this and sample data coleected is available at the [testbed folder](https://github.com/cledantec/Cycle-Atlanta-SLaB/tree/master/DSSG2017_gas_testbed). After pulling out the air out the vacuum bag, we sprayed the wine preserver gas into the bag and see how the values change. Some photos and graphs for this are as follows:


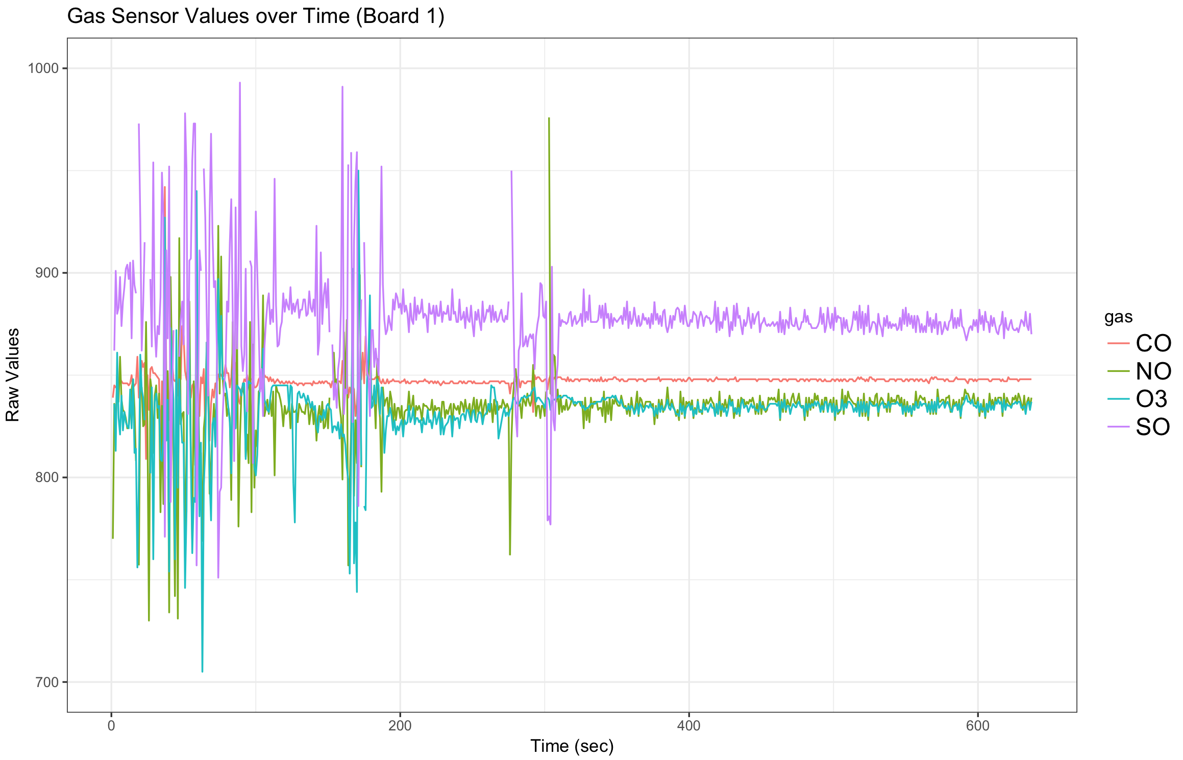
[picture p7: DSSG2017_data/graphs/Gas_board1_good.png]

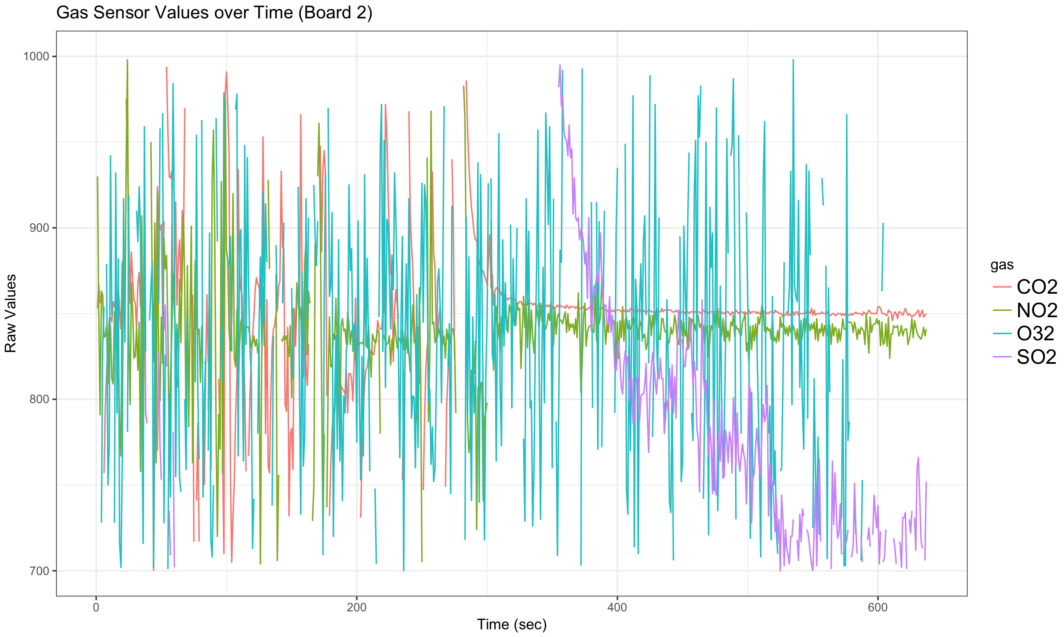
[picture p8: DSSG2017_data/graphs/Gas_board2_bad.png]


The baseline values can be calculated by averaging the second half of the values (after the signals become stable). The board 2 graph shows that some sensors never become stable. In this case, we mark it as "bad". The overall status of the gas sensors is presented at the [Google Spread Sheet](https://docs.google.com/spreadsheets/d/18mLQVb0HjoA-88Tq4y8rYqyIrmJ9yjPXizwVc3SuRZM/edit?usp=sharing).

**Gas Value Calculation** The gas sensor board composed of two OP-AMP devices, four sensors, and an ADC. Each op-amp chip has four op-amps embedded in it. Each sensor uses two op-amps. The first op-amp is for supplying a stable voltage to the sensor. Our base power for all the sensors is 5V, and the first op-amp supplies 2.5V power to the sensor. The sensor's voltage change outputs to the input of the second op-amp.  

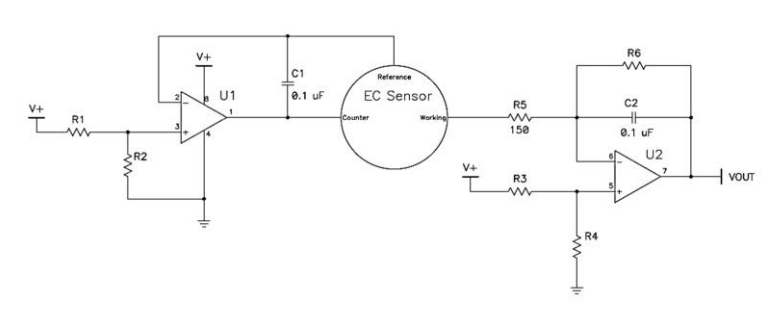
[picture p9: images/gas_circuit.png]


The second op-amp actually amplifies the sensor signal. The amplification rate is determined by dividing R6 by R5 (150 Ohm now). So the actual voltage change due to a gas stimulus can be calculated as follows:

```
# the units are V
V_gas = (V_out - V_base) / amplification_rate 
```
where `amplification_rate = R6/R5`, `V_out = (2.5V * ADC_reading_output)/2048`, and `V_base = (2.5V * ADC_reading_base)/2048` (here, ADC_reading_base is coming from the mean of the vacuum bag gas values.

Once we have `V_gas` value in V, it's possible to calculate the actual ppm or ppb value of the gas.
For example, if looking at the [CO sensor's data sheet](https://www.spec-sensors.com/wp-content/uploads/2016/04/3SP_CO_1000-P-Package-110-102.pdf), the spec says the sensitivity is 4.75 nA/ppm. This means `V_gas = (4.75nA * CO_ppm) * 150 Ohm`. Thus,

```
CO_ppm = V_gas / (4.75nA * 150 Ohm)
```

Of course, there can be electrical noise, bias, and the impact of other sensors. These need to be adjusted. The impact of temperature, humidity, and other gases can be adjusted based on the data sheet's information. Also for ensuring the accuracy of the gas sensors, we co-located out testbed at the offical Atlanta gas station. 

**Official Sensing Station** Even though we calculated gas values correctly using formula, it is possible that gas sensors are biased electrically. So, the best way to adjust it is to use the real gas values as ground-truth and adjust them empirically given the theoretical values. We co-located gas sensors at the station for 48 hours, and observed how they change over time. The official gas sensor values are available at [this folder](https://github.com/cledantec/Cycle-Atlanta-SLaB/tree/master/DSSG2017_data/gas_station_data). We used gas board #1, #4 and $7 since they were only boards without erroneous sensors. The testbed values are available at [this folder](https://github.com/cledantec/Cycle-Atlanta-SLaB/tree/master/DSSG2017_data/gas_station_data/original_testbed). Based on these two datasets, we need to find a coefficient for each sensor, and adjust the values.

## Sensing Box design

The back unit is in charge of collecting proximity and air quality data, as well as providing energy to the whole system.

The case of the back unit is based on a basic electricity connection box made of ABS plastic which is laser cut for providing the required slots for the sensors as well as the ventilation inlets.

Sources files for their fabrication are found [here](https://github.com/cledantec/Cycle-Atlanta-SLaB/tree/master/DSSG2017_SensingBox_Arduino/ABS_laser_cutting).

The box is screwed directly on a rack which is mounted in the back part of the bike. After different iterations, direct drilling and screwing with an elastic material between the box and the rack is showed as the most solid alternative.

Inside the box the components which can be found are the following ones:

- a powerbank for providing energy to the whole system.
- 2 LIDAR sensors for proximity on left and right sides.
- 3 SONAR sensors for proximity on left, right, and rear sides.
- a PM NOVA sensor for detecting Particulates Matters under 10μm and 2.5μm as air quality metric.
- a custom gas sensor board for the detection of ozone, carbon monoxide, sulfur dioxide, and nitrogenn dioxide as air pollution metric from other vehicles.
- an Arduino UNO board gathers all the data from those sensors.

Assembly (https://youtu.be/Jq7rCaWT5Fk "Assembly")<br>
*Timelapse of the assembly of the box v.1.0.3*

The box is completed by providing electric power to the Arduino board and outlet externally for the Raspberry located on the front unit of the bike, as well as completing the TTL-to-USB connection for communicating the Arduino with the Raspberry Pi.

The assembly of the component of the box can be followed on the posted video. The only difference in the last iteration of the design is the replacement of the wooden board separating the battery and the Arduino board by a yoga mat under the microcontroller.

****
#### PREV PAGE: [System Overview](overview.md)
#### NEXT PAGE: [Software Systems](software.md)

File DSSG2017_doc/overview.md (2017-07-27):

System Oveview
========
As of July 26, 2017

## High-level Architecture
The sensing system consists of two parts: a *master unit* and *slave unit*.<br>
This architecture is a result of reverse engineering and optimization based on the initial prototypes from the LMC6650 class project. 
The master unit runs a Linux server (i.e., Raspbian Jessie) that provides RestAPIs and a socket application that deals with the serial communication with Arduino. <br>
The slave unit runs on an Arudino board and it sends out sensor data to the master unit following the commands from the master. 

## Master Unit 
#### Raspberry Pi + Matrix Creator + GPS
Matrix Creator is a collection of built-in sensors such as gyroscope, accelerometer and thermometer. This is attached to the Raspberry Pi through GPIO pins. Besides, Pi has four USB ports, one ethernet port, and two different power ports. A custom GPS device communicates with the Pi through a USB port. Another USB port is connected to the Arduino. Also, the flat power port (USB-C type) is used to connect to the battery on the back side. Overall, two lines are going out from the master unit to the sensor box.

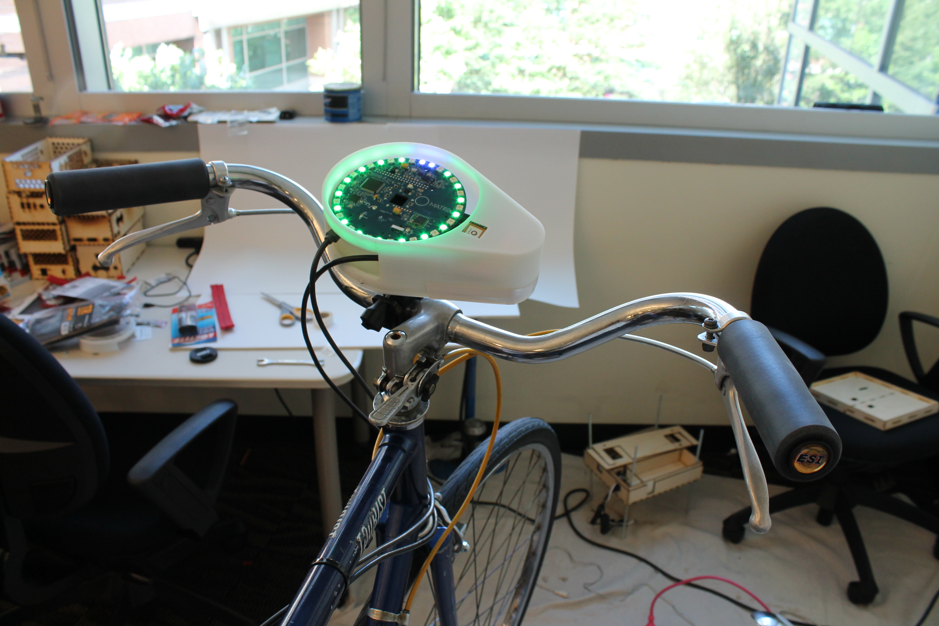
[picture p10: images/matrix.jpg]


Raspberry Pi runs "Raspbian Jessie Desktop" for its operating system. For saving the energy consumption, the command-line mode was used instead of the Windows mode. Since some OS-level configurations such as auto-start and auto-login change depending on the booting mode, it is required to configure at the right places for each feature. Also, collected data from the Matrix, GPS, and the Arduino board are stored in the "data" folder in the Linux system. The details about the software configurations and folder structures are presented in the [Software Systems](software.md) document. 

Also, to minimize the effect of physical shocks and vibrations on the Pi operations, we added some protection mechanicsms. These physical designs are explained in the [Case Design](cases.md) part. 

Finally, the custom GPS design is presented at the [Hardware Systems](hardware.md) document. 

## Slave Unit
#### Arduino + a Gas Sensor Board + two Lidars + three Sonars + a PM Sensor + a Battery
Arduino has a type-B USB port, a power port, and mutiple pins for GPIOs and Digital inputs. Since many sensors had to be attached to a signle Arduino board, we made use of all the pins available for different connections. For example, the type-B USB port was used only for supplying power, while actual serial communications were implemented through making use of serial pins. The original power jack was not used since it required a higher voltage as input that was not available from our battery. The details about sensor connections will be discussed in the Hardware Systems](hardware.md) document. Since there is no operating systems for Arduino (but only a thin layer of firmware), there is no starting/stopping mechanism in the codee, but it starts working as power is on.



## Communications
The master unit and slave unit communicate through a USB-based serial cable using a basic protocol. The master unit sends out commands to the slave unit regularly depending on the behavior of the slave. The slave unit either sends a line of sensory data to the master unit or resets itself. The details are presented in the [Software Systems](software.md) document. 

****
#### NEXT PAGE: [Hardware Systems](hardware.md)

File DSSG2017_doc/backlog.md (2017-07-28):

Backlog
==========
**Issues, Solutions, and Future Suggestions**

## Gas sensor board
* [**Need to Check**] ADC address assignment<br>ADC behavior is inconsistent depending on the address pin assginment. According to the spec, connecting the address pin to GND sets its address to 0x48. Similarly, this pin to VDD (0x49), SDA (0x4A), and SDL(0x4B). However, only GND (0x48) shows a consistent ADC behavior, and others vary randomly. So if you want to use an address other than 0x48 for a testing purpose, you need to check the signals beforehand. Relevant information is available at [the hardware systems doc](hardware.md). 
* [**Things to Consider**] It is always better not to expose resistor legs. For now, resistor legs are exposed due to their sizes. It's better to use shorter resistors to fit them into the slots. 
* [**To-Do**] Gas sensor value adjustment<br>One thing that we found is that baseline ADC readings for each gas sensor was different from each other. This means we cannot use a simple formula to calculate actual gas values in ppm. The official gas values and our sensor values at the same space/time are already collected, so actual adjustment needs to be made. See [the hardware systems doc](hardware.md) for the details.
* [**Done**] Amplifying resisters<br>The amplifying resistor in the 2nd op-amp was 500K in the first board. Since we did not have 500K resistors, we first tried 560K and the signal was not coming in correctly. After doing some testing, we found that it cannot be more than 530K. As soon as it goes over 530K, the sensor signal stops coming in. We thus soldered 470K resistors for R6.
* [**Done**] A gas sensor address changed<br>One of the gas sensors in the complete box was using 0x49 and was working fine when running independently. When connected them with lidars, it stopped working. So we had to move the address to 0x48 instead. This is an unexpected behavior and need to check in the future whenever using different addresses.

## GPS
* [**Done**] GPS's "EN" pin needs to be connected to VDD. Otherwise, the GPS starts working for a minute after running the script and stops randomly.

## Arudino Receiver and GPS Reciever
* [**Done**] Serial communication randomly stops and raises no error <br>In the loop of collecting data from Arduino and GPS, sometimes Arduino or GPS does not send out the data back to Pi, and the Receiver server waits forever. In order to prevent this, we implemented a timeout handler. After a few seconds, if there's no response from a data collection script, it raises an TimeoutError, and the error handler sends out "reset" signals to units. 
* [**Done**] Dealing with "NACK" signal from Arudino<br>Whenever Arduino starts collecting data, it sends out "NACK" signal. Sometimes, it keeps coming in until we reset the Arduino board. To deal with this, we first changed the data collection logic from "polling" to "command-based" one. Pi sends out a "f" signal which means "reset Arduino" when starting up the system. And then sends out "g" signal. The next data coming in contains "WINWIN", that means Arduino correctly started. Then, it keeps sending out "g" and collect data. If "nack" signal comes in again, it automatically sends "f" again to reset the Arudino board. This mechanism makes the system fault tolerant from software- and signal-level failures. 
* [**Done**] Separating GPS and Arduino Receivers<br> Originally, GPS and Arduino data collection scripts were all together. While we need to collect Arduino's sensor data more frequently, the speed is bounded by the GPS speed - 1 second is the maximum speed for GPS. So we separate it into two servers. 

## Arduino Board
* [**Done**] Pin 12 and Reset pin on Arduino were connected with a 1.2K resistor to implement software-driven hard-reset functionality. This makes it possible to use "f" signal (reset) from Pi. 
* [**Need to Check**] Too much solder creates a hardware error<br> If too much solder is applied to a wiring on the bridge (especially for SDA and SDL pins), Arduino randomly stops with no reason. Removing some big solders resolved this kind of problems. An ideal way to deal with this is to make a custom PCB board for the Arduino bridge. Its Fritzing files are available in this repository. 

## Raspberry Pi Linux
* [**Done**] In order to fix the random assignments of USB ports to GPS and Arduino (i.e., sometimes, GPS connects to "ttyUSB0" and Arduino to "ttyUSB1" and sometimes, vice versa), we created symbolic links that check devices' vendor/product IDs and dynamically connects to ttyUSBx ports. For now, GPS is using a symbolic link called "cycle_gps" and Arduino is connected to "cycle_arduino". These rules can be specified at `/etc/udev/rules.d/99-usb-serial.rules` inside the Pi's Linux system. For the details, see [this article](https://unix.stackexchange.com/questions/66901/how-to-bind-usb-device-under-a-static-name). 

## Sensor Pin Connections
* [**Need to Check**] Wire Orders <br> For now, the pin orders of sensor connectors (wires) are not consistent. Some are reversed way, and some are correct way. In the sensor boxes, we made sure that they're correct for each box, but in the future, it is necessary to check wiring orders whenever you change something in each box. 

****
#### PREV PAGE: [Data Analysis](data.md)

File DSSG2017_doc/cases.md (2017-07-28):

Sensor Box and Cases
## **Back Unit**
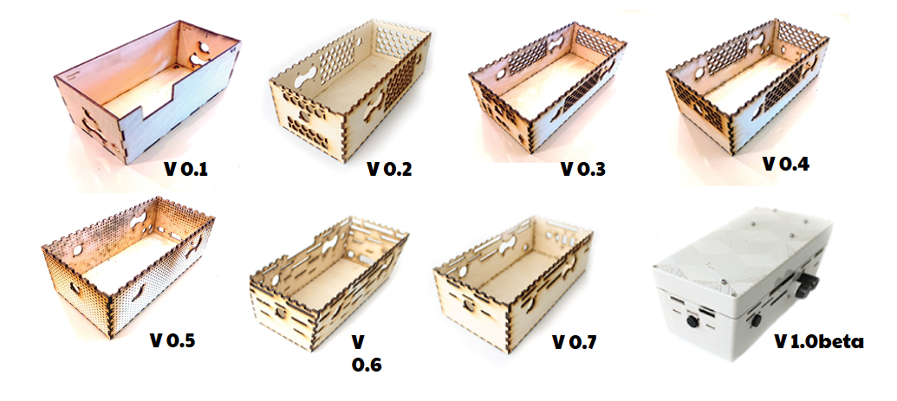
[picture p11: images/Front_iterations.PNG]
Front Cases

#### Description 
This box houses the battery arduino and the proximity and air quality packages. The main power switch is located on the front of this box along with the data and power ports. Holes had to be drilled on the bottom of the box to attach it to the bike rack on which the system was mounted.
Initial prototyping was done in plywood and then transitioned onto ABS boxes for a more impact resistant case.
#### Software
Adobe Illustrator CC 2016, Solidworks 2016 were the software used to create the shapes in vector format to be used in the laser cutter.
#### 3D Printers
The Laser cutter used was in the Fab Lab at TSRB. The settings of the laser for cutting Acrylic was 20% power and 11% speed. For Plywood it was 50% power and 25% speed
#### Bike Rack mount
The Rack was initially attached to the box with the help of nylon clamps. These clamps proved to be too weak and were snapping off during the vibrations. We then tried using metal clamps but they seemed to fail in the same way. We then decided to drill holes through the base of the ABS box and out through the bike rack. This proved to be the most effective method of securing the box down onto the rack.
#### Extra Modifications
•	Holes drilled on the bottom for Rack screws
•	Rubber pads used to secure the rack to bike. The rubber prevents the rack from fishtailing.
•	Holes need to be drilled on the lid for the air package to be screwed on the underside of the lid.
•	The ABS boxes had projections on the inside which needed to be drilled down to accommodate the components.

## **Front Unit** 
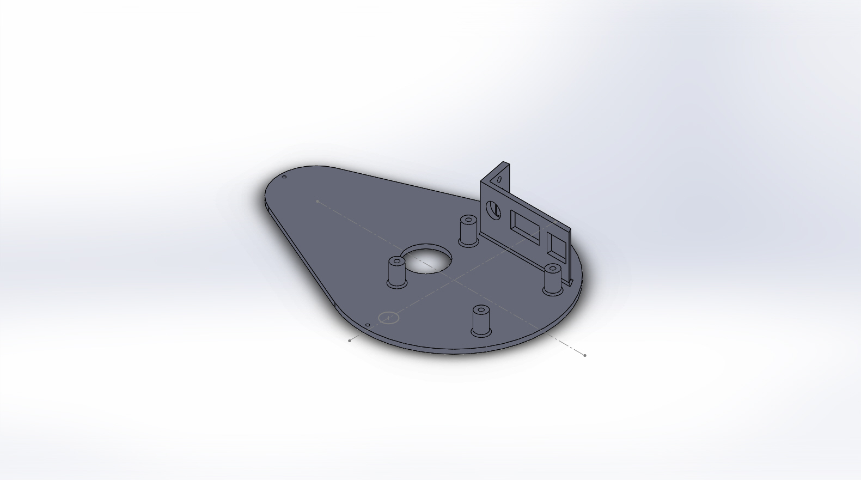
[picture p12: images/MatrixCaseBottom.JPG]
Case Bottom

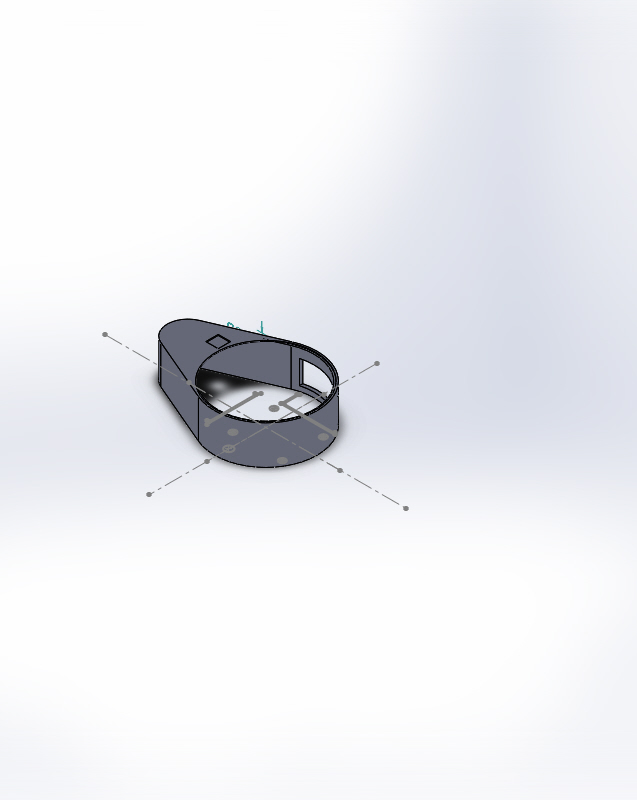
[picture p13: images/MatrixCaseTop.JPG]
Case Top

#### Description
The box is egg shaped and houses the Matrix, Raspberry and the GPS. The box is 3D printed. It consists of the top, bottom, base and the Go Pro mount. It has an acrylic window through which LEDs show the status for every sensor on the bike and the system as a whole.  It also has a window for open air access for the GPS.
#### Software
Solidworks 2016 was used to create solid part file. It was then exported as an STL file for use on the 3D printers.
#### 3D Printers
**Location:** Fab Lab (TSRB)
**Pros:** 2 printers, UV printer is perfect for the job (preferred printer for final product)
**Cons:** Time taking

**Location:** DILAC
**Pros:** An option
**Cons:** Unable to print complex geometry of the top 

**Location:** Athena Lab (TSRB)
**Pros:** Super fine print resolution
**Cons:** Very small workspace (needs precise angling for print)

**Location:** Invention Studio
**Pros:** Many Printers
**Cons:** Poor quality of print, Unable to print lip of Top

#### Go-Pro mounts
The mount must be sturdy with very little degree of freedom. It should be set such that the GPS points upward.  Make sure the screw of the mount does not touch the Raspberry board.
#### Extra Modifications
•	The matrix is unsupported on one side and was bouncing off the raspberry pins during data collection- Yoga mats were used as an absorber to prevent bouncing during the ride. Additionally the matrix was tied down with insulated wires.
•	The three small screws along the base of the model were not very strong and the top kept coming loose- 2 long screws were drilled through all the pieces on either sides of the GPS to keep everything in place.
•	The head of the cable used for the communication with the arduino is  fat and prevented closing of the lid- The head needs to be shaved.
•	At times the holes were filled with material- The holes had to be drilled in the workshop
#### Future
The Base and Bottom needs holes drilled into them for the two long screws that secure the parts together.
The walls in the Bottom model needs to be raised slightly to provide support for the matrix.

## Link to Files
[Case design files](https://github.com/cledantec/Cycle-Atlanta-SLaB/tree/master/DSSG2017_Case_Design)

****
#### PREV PAGE: [Software Systems](software.md)
#### NEXT PAGE: [Data Viz (3D)](dataviz.md)

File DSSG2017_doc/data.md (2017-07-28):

Data Analysis
=======

Our long-term goal is to refine and complement the LTS model by supplementing sensor data in addition to the survey/interview data, because some of dynamic objects such as cars and people are hardly identified through survey/interview in a quantitative way. However, if we want to detect environmental factors by making use of sensor data, it is essential to distinguish between different objects (sensor data itself does not imply any contents of the environment). Without distinguishing between different factors, operationalizing the LTS model using sensor data can be hardly justified. This process is critical in advancing to informed decision-making based on objective datasets. In order to detect sementic-level objects beyond the sensor-level recognition, we use machine learning techniques to classify environmental factors. The process to analyze data is as follows.

## Ground-Truth Data Collection 
When collecting the data, we installed a GoPro camera on the bike along with sensor systems. This was to collect ground-truth data. If we want to detect sementic-level factors, we need to know what objects actually exist around the bike way. 

## Data Synchronization
Since GoPro does not keep the real time, it was necessary to sync between the video and sensor data. Sensor data's timestamps are based on the GPS data, so the time was accurate. Meanwhile, the video had only times based on the play time. In order to sync them, we used a corner of the map as a reference point. 

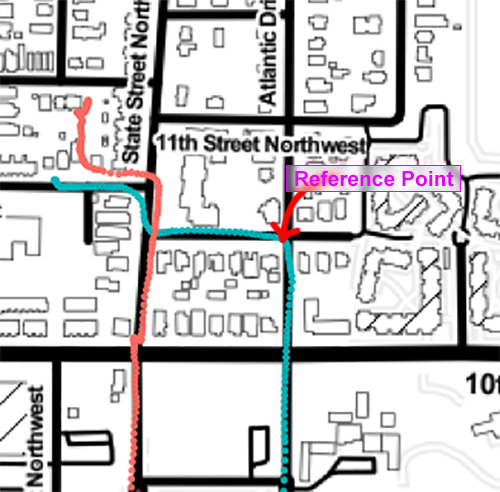
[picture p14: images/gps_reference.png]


In other words, we first plotted the GPS data on the map, and pin-pointed the timestamp of the data point at the corner. Also, in the video, the cornering time was captured as a sync point. Based on these reference times, other times were matched each other. The final data table looks like this (`time` is the GPS time, and `video_time` is the corresponding time of the video):

|  ...| day | time  | video_time | lon | lat | USRight  |  more...| 
| ---- |:-----:| :-----:| :-----:| :---:| :---: | :---:|:-----:|
| | 220717 |03:49:37| 00:02:28  |  -84.3895| 33.77709 |  308.18 |  |
|  |220717 |03:49:38| 00:02:29  |-84.3895| 33.77709  |  589.91 |  | 

## Classifier Generation

Given the synchronized data, we recorded surrounding environment every second by watching the GoPro video. When recording the surrounding factors, we classified them into specific labels. Major objects found on the left *or* right side of the bike were considered **classifiers**. These classifiers were generated separately for the left and right sides (so there are two different kinds of classifiers each second). 

Since the stress level of the riders can vary depending on different types of objects, we tried to distinguish a similar type of objects based on their status. For instance, our classifiers for a car are in the following table.

| Object | Classifier  Name | 
| --- |:---:|
| a parked car | Car Stop|
| a moving car | Car | 
| cars parked in parallel  | Parallel| 

Classifying the objects on the left and right side of the bike from the video was a long process since we had to pause the video every second to write down the objects found. Once we had documented our findings, we added them to a CSV file containing the data captured by the sensors. The following table is an example of one of our csv files. 

| ...| day | time  | video_time | LS Classifier | RS Classifier |  USRight  |  USLeft |  USRear| LidarR| LidarL |...| 
| ----- |:---:| :-----:| :-----:| :---:| :---: | :---:| :-----:|:-----:| :---:| :---:| :----:|
| |220717 |03:49:37| 00:02:28  | Parallel |  Parallel |  308.18 | 640.08  |  640.08 |619.333| 1778.66| |
|  |220717 |03:49:38| 00:02:29  | |  Tree |  589.91 | 640.08  |  640.08 |832.25| 1 | |
|  |220717 |03:49:39| 00:02:30  | |  Tree |  642.62 | 640.08  |  640.92 |506 | 603 | |
|  |220717 |03:49:40| 00:02:31  | |  Tree |  642.11 | 640.08  |  640.08 |521.2 | 366.2  | |
| |220717 |03:49:41| 00:02:32  | Parallel |  Parallel |  487.68 | 640.08  |  640.08 |433 | 616.333| |
|  |220717 |03:49:42| 00:02:33  | |  Car Stop  |  148.59 | 640.71  |  641.35 |114.5 | 943.5  | |
|  |220717 |03:49:43| 00:02:34  | |  Car Stop  |  241.93 | 640.08  |  641.35 |744.5 | 770 | |

## Inter-Reliability Test

#### Two coders
Classifying process was conducted by two members of our team separately. They followed the same steps without discussing their findings between each other. The only thing they discussed was the classifier labels so they have a same label for the same object. After the two coders clssified all the data in the CSV file, the inter-reliability scores were calculated based on the agreement rate.  
 
| LS Classifier | RS Classifier 
| :---: |:---:|
| 81% | 64%|

Since the inter-reliability score for the RS classifier was not satisfactory, both coders discussed the criterion in classfing objects, and repeated the process. In the second interation, the scores increased as follows:

| LS Classifier | RS Classifier 
| :---: |:---:|
| 86% |  76% |

We cannot say these scores are perfect, but reasonable enough for doing some analysis. Special attention should be put on the labels of the classifiers. Different labels for a same object can be a cause of a low inter-reliabilty score. These are the list of our classifiers in the first iteration: **Tree**, **Bike**, **Parallel**, **Car Stop**, **Car**, **Trash Can**, **Wall**, **Cone**, **Bike racks**, **Tunnel**, **Person**, and, **Road sign** 

## Sensor Data Processing 
Given the nature of the sensory data such as high noise level and sensor errors, the data cannot be directly used in the raw format. There need to be several steps to clean up the signals instead. Some techniques for processing noisy sensor/electrical data are known in the field of signal processing. This section describes steps how the data are processed to be used for machine learning. Particularly, we focused on the proximity data (i.e., Lidars and Sonars). R scripts for this are available at [this location](https://github.com/cledantec/Cycle-Atlanta-SLaB/blob/master/DSSG2017_data/R/170722_Preprocessing.Rmd).

### (1) Converting to the Distance Domain 
Since the bike speed varies depending on the traffic and other factors, signal patterns can be different as well depending on it (even if the objects are same). This led us to normalize the speed by changing the time domain to the distance domain. Since GPS data provide the speed, it was possible to conver the domain easily in R. Some paramters/points to consider carefully are as follows:

* the GPS speed unit is "knot". 1 knot = 0.514444444 m/s
* the time interval of Lidar/Sonar data collection is 0.2994975 seconds (this was calculatated by dividing the entire time span by the number of rows). In the code, the loop time interval is set to 200ms, but the actual interval is a bit more than this due to the script execution time. 

```
distance (m) = speed (m/s) * time_interval (sec)
``` 
Once the proximity data is converted to the distance-domain signals, the signal pattern looks normalized and consistent regardless of bike spped. However, the intervals between data points become inconsistent (intervals vary depending on the speed). An example of the distance-domain data is as follows:

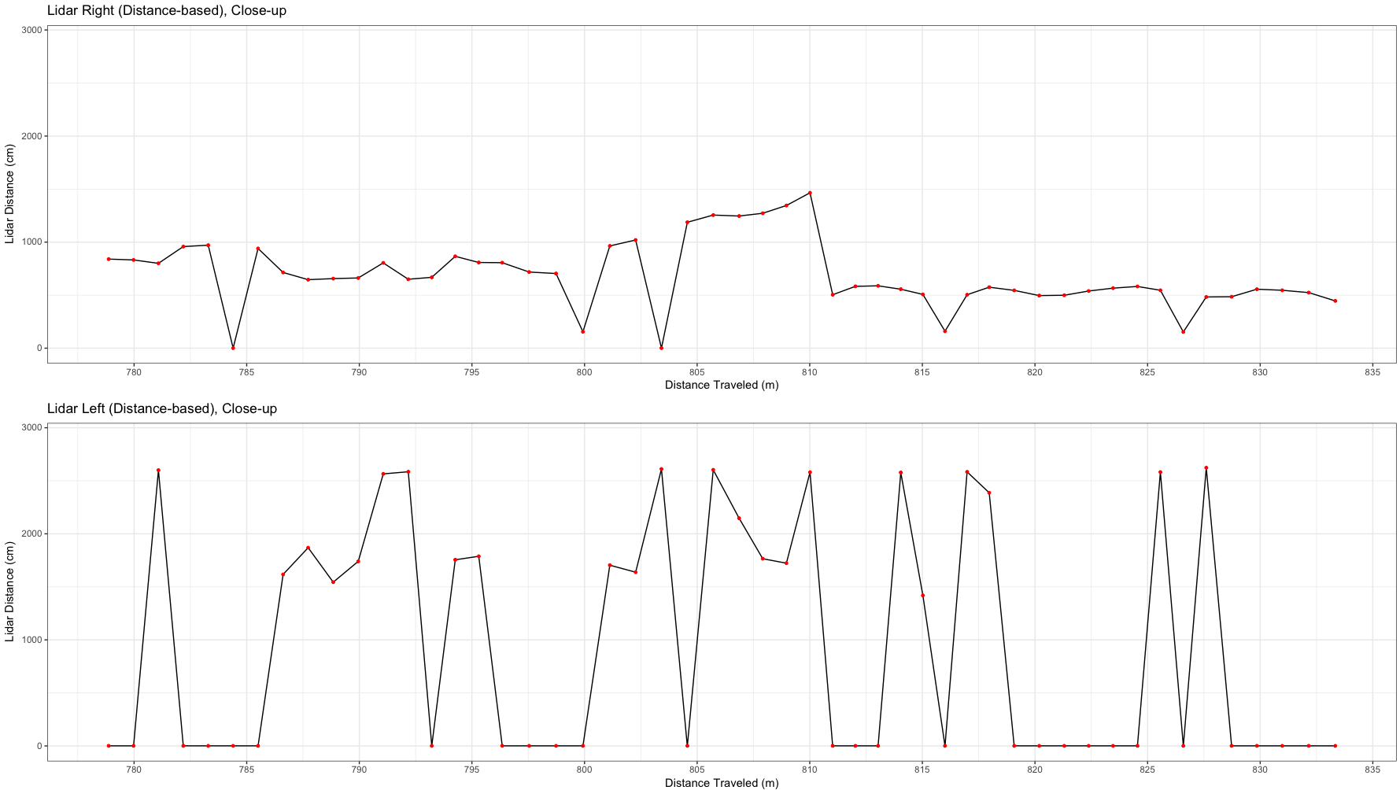
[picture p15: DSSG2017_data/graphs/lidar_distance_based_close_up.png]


### (2) Interpolation
Before making the gaps between data points consistent, some errors that came from the sensorse themselves had to be fixed anyhow. One major observation from lidars is that the signal often goes down to 1 or 0 (cm), which in theory is not possible. In order to compensate this sensor errors, we adopted a simple interpolation method. The way we interpolate erroneous data points is to make them same to the previous values whenever the value goes down to 1 or 0. It is also possible to use other interpolation techniques to compensate missing sensory data, but in order to do that, some research on the characteristcs of sensors needs to be conducted, and appropriate assumptions about data need to be made. An example of the naïve interpolation result is shown below.

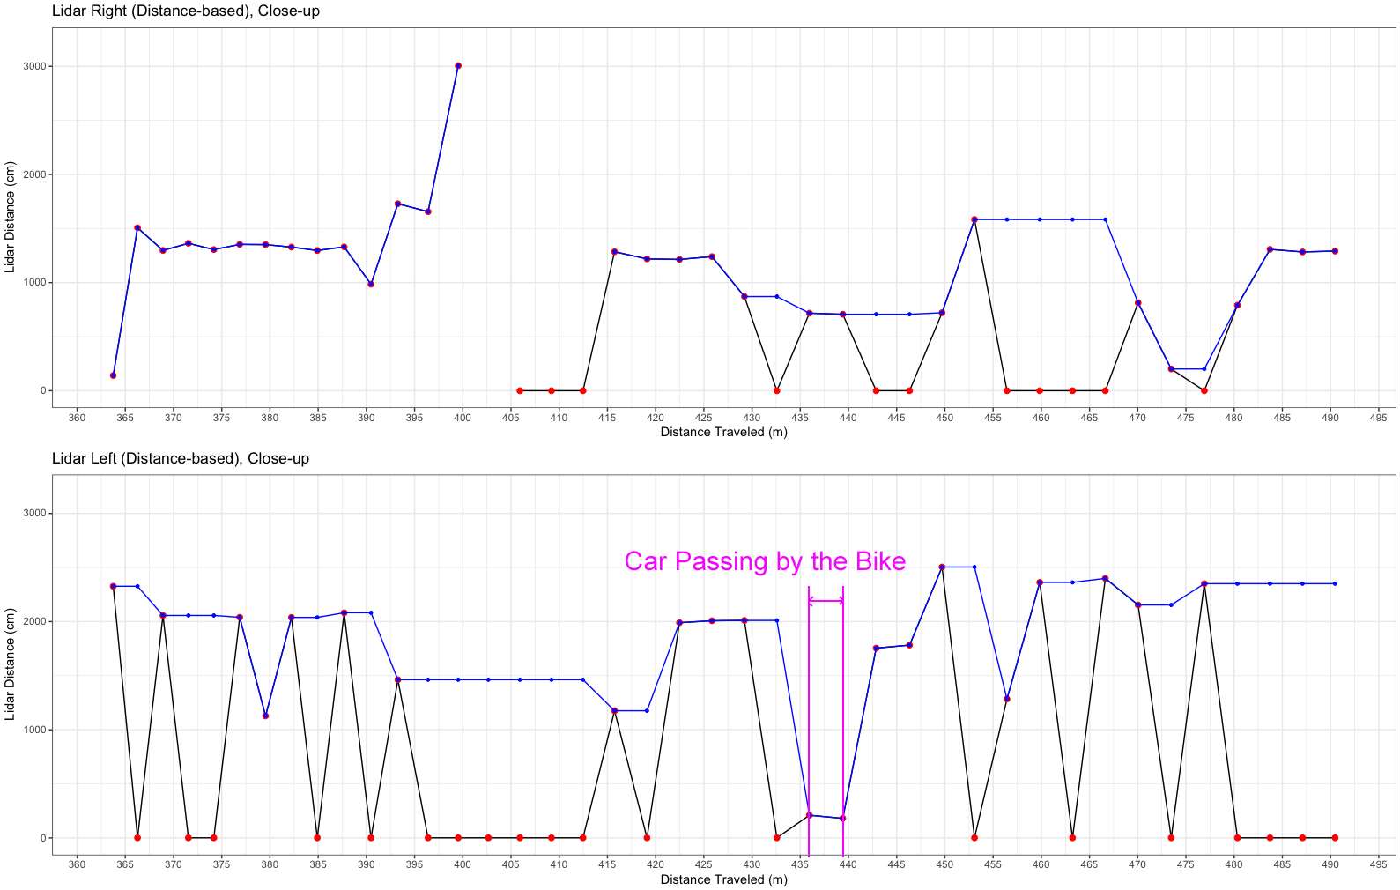
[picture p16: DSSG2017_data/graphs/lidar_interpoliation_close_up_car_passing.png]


### (3) Resampling
Now, it is possible to resample the signal to make the gaps between data points consistent. By prorating the hights of the desired data points based on the distances between original data points, it was possible to reconstruct a fixed-distance axis. The data resolution was set to 1m as it was close to the median value of distance intervals in the distance domain. 

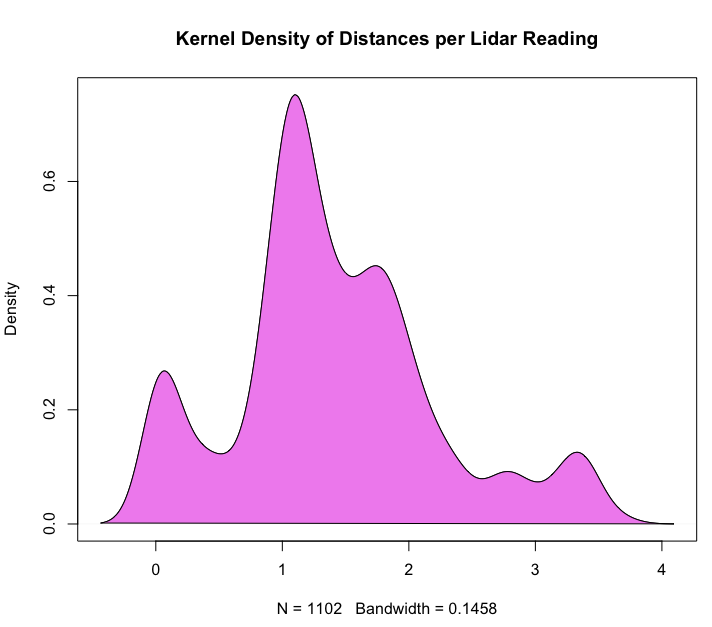
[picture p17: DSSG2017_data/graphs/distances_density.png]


An example of resampled data is as follows:

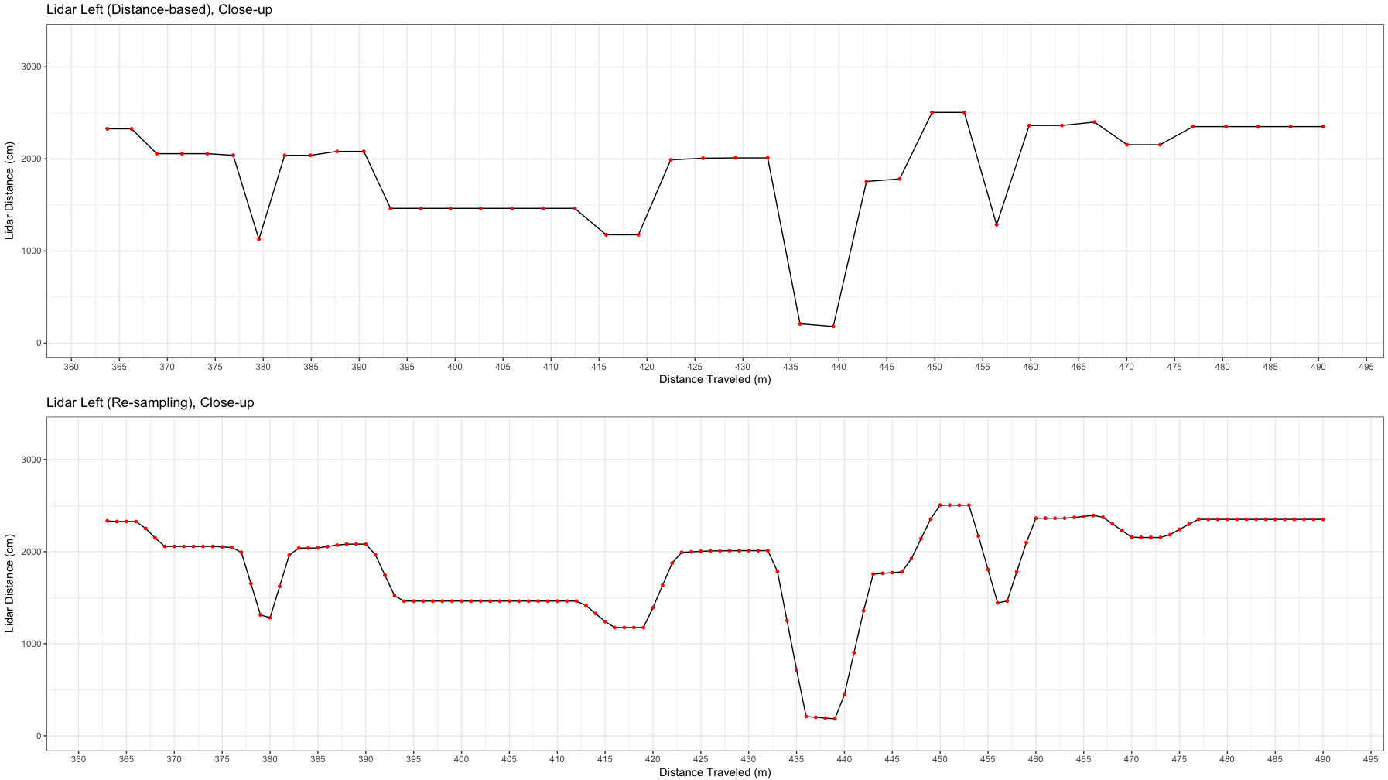
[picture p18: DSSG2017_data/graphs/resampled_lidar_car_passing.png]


### (4) Gaussian Smoothing
As the last step of the signal clean-up, the sensor noise was supressed using the Gaussian filter. The window size of the filter can be optimized in the future after conducting some sensitivity analysis. For the initial try, we set the window size to three for both lidars and sonars. The shape of the data before and after the smoothing is as below:

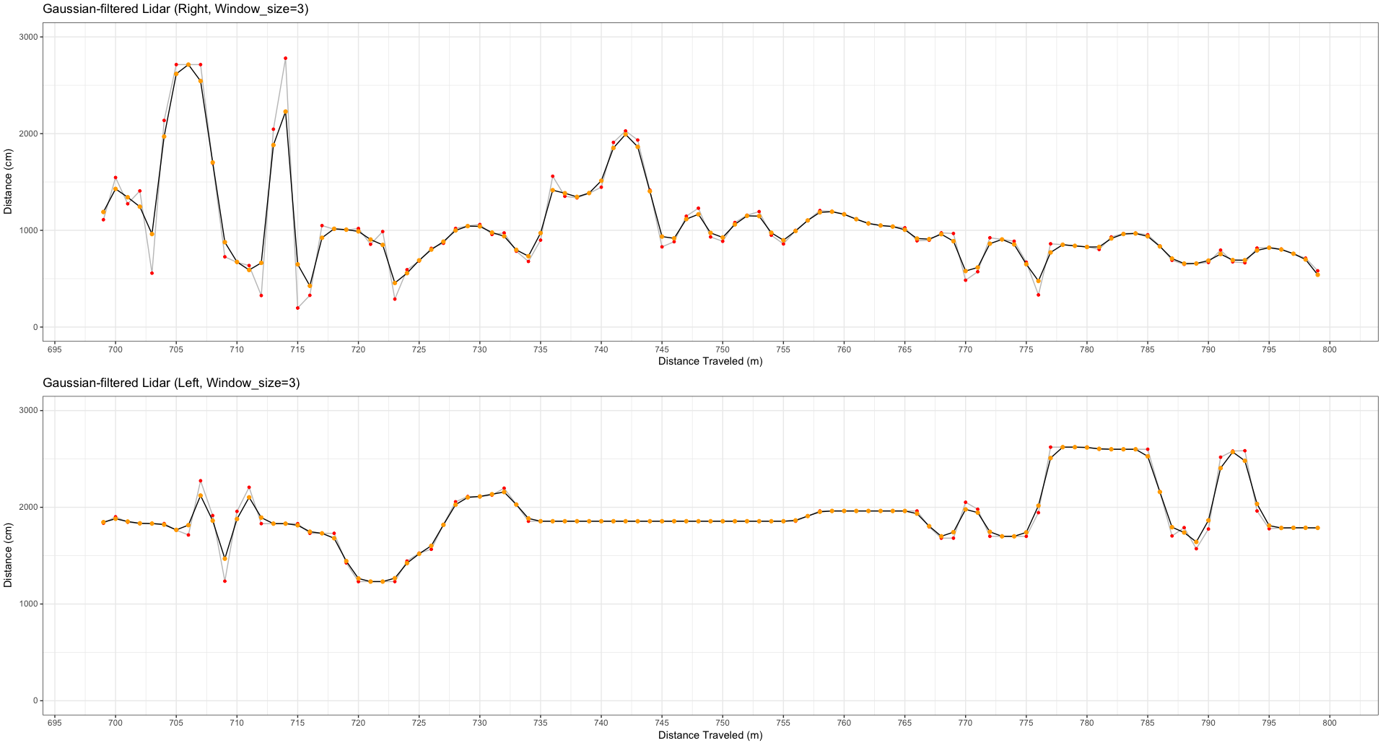
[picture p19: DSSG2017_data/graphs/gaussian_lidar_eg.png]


### (5) Feature Generation using DCT
For generating features from the processed dataset, we decided to use the [Discrete Cosine Transform (DCT)](https://en.wikipedia.org/wiki/Discrete_cosine_transform) for making frequency-based patterns of environmental factors. Since the position of the object in a data segment can vary significantly depending on the time chunking strategies, and this variance in the patterns makes it hard to use the temporal signature of the data. This led us to convert the time-domain data into the frequency-domain data. We set the unit size of the data chunk to 15m (i.e., 15 points of data. The chunk size can be also tuned better after doing some testing), and generated frequency-domain signautres of all the 15m chunks from about 1550 observations. 

Since the frequency-based score for 0 (i.e., freq(0)) is high due to the boundary condition for DCT results, we removed values for 0, and took a vector of 28 elements as the feature (14 for a lidar, and 14 for a sonar).
An example frequency-based feature (when a car is passing by) is like this:

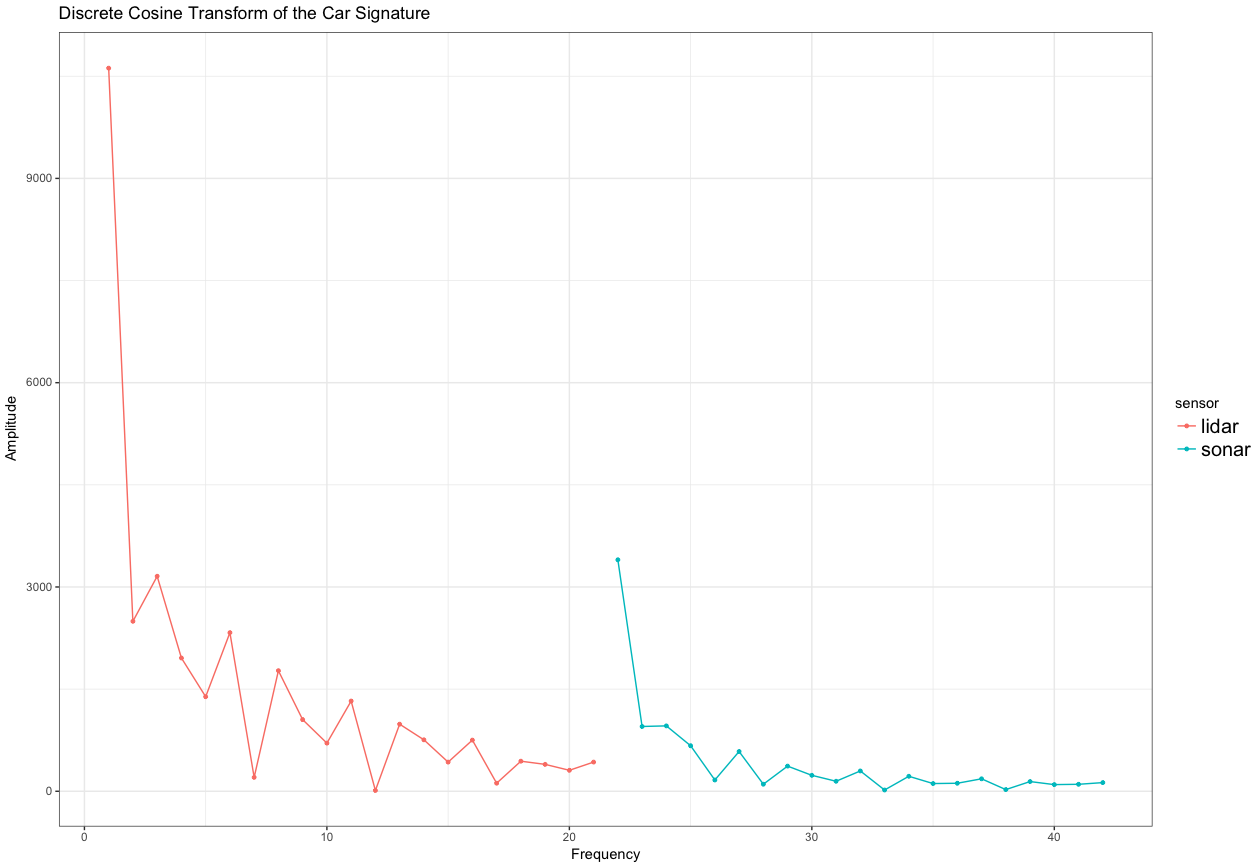
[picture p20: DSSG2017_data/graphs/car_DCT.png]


## Predictions 
Using the vector of 28 frequency-based pattern feature, two machine learning algorithms, [Support Vector Machine (SVM)](https://en.wikipedia.org/wiki/Support_vector_machine) and [Random Forest](https://en.wikipedia.org/wiki/Random_forest) were used to predict the classifier of each data segment. To compare the performance of the prediction models to the baseline classification power (when randomly predicting classifiers), we plot them together with varying train-test sets. The results are as follows:

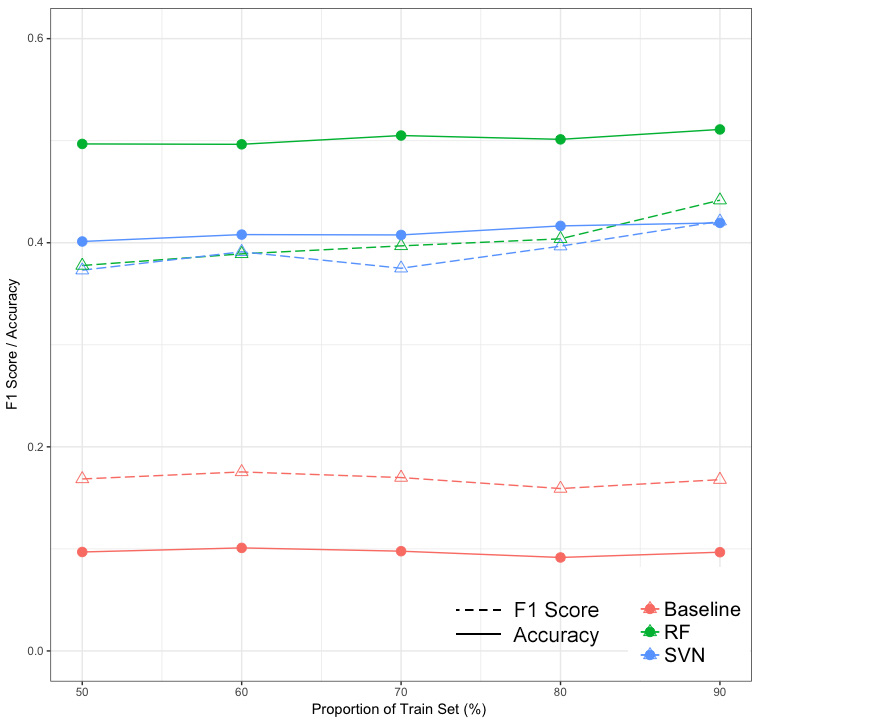
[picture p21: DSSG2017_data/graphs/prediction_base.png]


## Future Work
This data analysis is an initial exploration of data, and there are many parameters and methods that we can tune for refining the prediction models (e.g., Gaussian window size, the size of data chunks, types of features in addition to the frequency-domain patterns, machine learning algorithms, and interpolation resolution). 

Our overarching goal is to identify environmental factors that give rise to bike riders' stress level. In order for this, the identification of environment should be achieved first as sensors cannot detect semantic-level objects. Once we can tune and refine the prediction model for detecting environmental fators through feature engineering and modeling, it would be possible to advance to answering the real questions: how bicycle infrastructures and environmental factors affect bike riders' stress level?; how these relationships can be used for constructing the Level of Traffic Stress (LTS) model?; and how policy-makers can use this knowledge to make polices for bike infrastructures?

****
#### PREV PAGE: [Data Viz (3d)](dataviz.md)
#### NEXT PAGE: [Backlog](backlog.md)

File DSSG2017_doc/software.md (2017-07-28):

Software Systems
========

### <span style="color:grey">Table of Contents</span>
1. [Raspberry Pi Server Installation](#raspberry)
2. [Raspberry Pi Linux Configurations](#config)
3. [Copying Data from Pi to a USB Stick](#data)
4. [Folder Structure and Useful Scripts](#folder)
5. [Arduino Sensor Control](#arduino)
6. [Creating an Image File from a Pi SD Card](#image)

## Raspberry Pi Server Installation
If you want to install a Linux system in a SD card, you can import the Pi image that was created from the most recent system configurations/set-ups. The image file is about 16GB and is in the Google Drive (SLaB Resources/SD Images/DSSG_pi.img.zip). 

1. Download the image file to your local machine and unzip it.
2. Insert a SD card to your computer.
3. In the command line, execute the following commands (Mac or Linux):

```
# Unmount the SD card to make changes in the file system.
sudo diskutil unmount /dev/rdisk2
sudo diskutil unmountDisk /dev/rdisk2

# Write the image to the SD card.
sudo dd bs=1m if=bike.img of=/dev/rdisk2
```

Once this operation is done, you can eject the SD card from your computer, and insert it to the Raspberry Pi. Then all the configurations/software for the sensor system are already installed in the server and the Pi is ready to use.

## Linux Configurations 
All the configurations are already done, but you can change it as needed. 

#### Auto Start
Auto start in the command-line mode is configured at 

```
/etc/rc.local
```
You can write down the script that you want to automatically run as the system starts. 

#### Auto Login
Auto login is configured in the Raspberry Pi's configuration menu. 

```
sudo raspi-config
```
You can go to `3. Boot Options` -> `B1 Desktop / CLI` -> `Console Autologin`.
After selecting desired booting option, reboot the system.

## Copying Data from Pi to a USB Stick
Since Pi is using the command-line mode, it is a bit tedious to transfer the collected data out of the Pi system (or copying files into the system). Before starting, a USB stick and the sensor box needs to be connected. Also, all the power needs to be shutdown. The steps are as follows:

1. When a USB stick, the Arduino data cable, a keyboard, and a monitor are connected (using a USB hub, if necessary), turn on the power from the sensor box. Then, the booting screen shows up on the monitor. Wait until automatically running the scripts. 
2. Once it starts collecting data, you need to stop the scripts. However, it's impossible to stop automatically running scripts. Press `Command + Right Arrow` to open a new terminal.
3. Log in to the Linux using a default credential (ID: `pi`, PW: `raspberry`).
4. Open the auto start configuration file.<br>
```
sudo vi /etc/rc.local
```
5. Comment out the shell script execution line `/home/pi/new_start.sh &` by adding `#` at the very beginning of the line. You can type it after changing to the editor mode by hitting `i`.  
6. By hitting `esc` key, change back to the command mode. 
7. Save the file by typing `:wq` + Enter.
8. On the command line, type `reboot` and Enter.
9. The system reboots itself. After rebooting, it does not auto start.
10. Go to the `data` folder. <br>``` cd data```
11. Mount the USB stick to the system.<br> 
```
sudo mount -t vfat /dev/sda1 /mnt/usb
```
12. Copy the newly collected data to the USB stick. Feel free to use wildcard (*) to copy them over altogether.<br>
```
sudo cp [file_name] /mnt/usb
``` 
13. Unmount the USB stick.<br>
```
sudo umount /mnt/usb
```
14. Revert the commented line back in `/etc/rc.local` and save it.
15. Turn off the power.
16. Disconnect the monitor and keyboard, and put the cables back.

** If you want to copy files from a USB stick to the Pi file system, you can take the same step. 

## Folder Structure and Useful Scripts
Locations of important files in the Pi Linux system are listed below.

#### The Main Trigger Script for Servers
This shell script triggers all the Python and Node.js servers.

```
/home/pi/new_start.sh
```

#### RestAPI Server
This Python server runs RestAPIs that provide URLs/APIs for other servers. Whenever it receives GPS data from the GPS Receiver server, it updates the global time in a variable so it can be used as timestamps.

```
/home/pi/matrix-creator-malos/src/js_test/server_opt.py
```

#### Arduino Receiver
This Arduino Receiver server sends out "g" or "f" commands to Arduino through the serial port. "g" commands Arduino to send back a row of sensor data, and "f" forces it to reset itself. If it receives Arduino data correctly, it converts data into a JSON format, and posts it to the `/proximity` API. 

```
/home/pi/matrix-creator-malos/src/js_test/arduino_receiver.py
```

#### GPS Receiver
This Python server collects GPS data every second by reading the serial port to the GPS device. When receiving data correctly, it saves it to the `/home/pi/data/` folder as a JSON file. At the same time, it posts the data to the `/gps` API so to update the global time.

```
/home/pi/matrix-creator-malos/src/js_test/gps_receiver.py
```

#### Node.js Servers for Matrix Sensors and LED Control
These files contains Node.js scripts that collect data from sensors on Matrix, and post them to RestAPIs. 

```
/home/pi/matrix-creator-malos/src/js_test/test_imu_server.js
/home/pi/matrix-creator-malos/src/js_test/test_humidity_server.js
/home/pi/matrix-creator-malos/src/js_test/test_uv_server.js
/home/pi/matrix-creator-malos/src/js_test/test_pressure_server.js
```

Everloop server controls LEDs through communicating with the RestAPI server.
```
/home/pi/matrix-creator-malos/src/js_test/test_everloop_server.js
```

#### GPS/Arduino Testing Scripts
Without running all the servers, it is possible to test the GPS device and Arduino by running the testing scripts. If everything works, GPS data and sensor data are printed every second. If you see "nack" or "reset" continuously, it means there are some errors in the hardware.

```
/home/pi/test_both.py
```

## Arduino Sensors Control
The code for sensor control from the Arduino board can be found at this [folder](https://github.com/cledantec/Cycle-Atlanta-SLaB/tree/master/DSSG2017_SensingBox_Arduino/oneArduinoAllAggregated).

For the correct working of all of the required sensors, additional libraries are needed for the ADS1015 (ADC units on the gas sensors) and for the LIDAR sensors. They can be found in the repository for each sensor, in the Arduino library manager, but as well they are provided [here](https://github.com/cledantec/Cycle-Atlanta-SLaB/tree/master/DSSG2017_SensingBox_Arduino/libraries%20to%20install).

## Creating an Image File from a Pi SD Card
If you want to create a new image file after making changes in the Pi, you can follow the following steps (Mac or Linux):

1. Eject the SD card from the Pi, and connect your computer.
2. In the command line:

```
# Unmount the SD card to make changes in the file system.
sudo diskutil unmount /dev/rdisk2
sudo diskutil unmountDisk /dev/rdisk2

# Create an image
sudo dd if=/dev/rdisk2 of=[out_path/output_file_name.img] bs=1m
```
This will take a few minutes.

Note that `/dev/rdisk2` can be with a different number (e.g., not 2 but 3) depending on Mac configurations. You need to check the exact file name for the SD card's symbolic link. 

****
#### PREV PAGE: [Hardware Systems](hardware.md)
#### NEXT PAGE: [Cases Design](cases.md)

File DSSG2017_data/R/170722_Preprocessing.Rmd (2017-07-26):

---
title: "Cycle Data Pre-processing"
author: "Myeong Lee"
date: "7/22/2017"
output: html_document
---

This script pre-processes the cycle sensors data so that they can be used as features and classifiers.
Pre-processing includes (1) converting the time domain to the distance domain, (2) interpolating missing values in the distance domain, (3) resampling variables based on the distances, and (4) appling the Gaussian filter to the signal to minimize the noise. 

```{r}
library(jsonlite)
library(readr)
library(dplyr)
library(sp)
library(ggplot2)
library(ggmap)
library(dplyr)
library(tidyr)
library(geosphere)
library(scales)
library(smoother)
library(dtt)
library(e1071)
library(stringr)
library(randomForest)

setwd("/Users/myeong/git/Atl_DSSG/Cycle-Atlanta-SLaB/DSSG2017_data/sample_data/Javier/")

multiplot <- function(..., plotlist=NULL, file, cols=1, layout=NULL) {  
  #' multiplot(): Generating multiple plots in one window  
  #'
  #' @param plotlist a number of ggplots to be aggregated
  #' @param cols the number of columns for the given ggplots when layout is not given
  #' @param layout the layout of the given ggplots (rows and columns)

  library(grid)  

  # Make a list from the ... arguments and plotlist
  plots <- c(list(...), plotlist)

  numPlots = length(plots)

  # If layout is NULL, then use 'cols' to determine layout
  if (is.null(layout)) {
    # Make the panel
    # ncol: Number of columns of plots
    # nrow: Number of rows needed, calculated from # of cols
    layout <- matrix(seq(1, cols * ceiling(numPlots/cols)),
                    ncol = cols, nrow = ceiling(numPlots/cols))
  }

 if (numPlots==1) {
    print(plots[[1]])

  } else {
    # Set up the page
    grid.newpage()
    pushViewport(viewport(layout = grid.layout(nrow(layout), ncol(layout))))

    # Make each plot, in the correct location
    for (i in 1:numPlots) {
      # Get the i,j matrix positions of the regions that contain this subplot
      matchidx <- as.data.frame(which(layout == i, arr.ind = TRUE))

      print(plots[[i]], vp = viewport(layout.pos.row = matchidx$row,
                                      layout.pos.col = matchidx$col))
    }
  }
}

gps <- read_delim("0722_prox_gps_join.csv", delim = ",", col_names = T)
prox <- read_delim("220717_prox.csv", delim = ",", col_names = T)
gps$id <- c(1:nrow(gps))
prox$id <- c(1:nrow(prox))

first <- gps[c(1:468),c("seq", "time", "lon", "lat", "video_time", "way", "speed", "LidarRight", "LidarLeft")]

LR <- ggplot(first, aes(x = video_time, y = LidarRight)) +
      geom_line() +
      geom_point(size = 0.5, color="red")  + 
      ylim(c(0,4000)) + scale_x_datetime(breaks=date_breaks("30 sec"), labels=date_format("%H:%M:%S")) +
      theme_bw() + theme(legend.text=element_text(size=15)) + ylab(label="Distance (cm)") + 
      xlab("Video Time")  + ggtitle("Lidar Right (Video_time)") 

LL <- ggplot(first, aes(x = video_time, y = LidarLeft)) +
      geom_line() +
      geom_point( size = 0.5, color="red")  +
      ylim(c(0,4000))  + scale_x_datetime(breaks=date_breaks("30 sec"), labels=date_format("%H:%M:%S")) +
      theme_bw() + theme(legend.text=element_text(size=15)) + ylab(label="Distance (cm)") + 
      xlab("Video Time")  + ggtitle("Lidar Left (Video_time)")

multiplot(LR, LL, cols=1)

# Actual riding begins at 0:02:00 in the video.
# Until 2017-07-22 03:54:38
first <- gps[c(139:468),c("seq", "time", "lon", "lat", "video_time", "way", "speed")]
second <- gps[c(474:nrow(gps)),c("seq", "time", "lon", "lat", "video_time", "way", "speed")]

prox_first <- prox[c(723:1825),]
prox_second <- prox[c(1826:nrow(prox)),]

first_join <- prox_first %>% left_join(first, by=c("time"))

#Video-time-based high-resolution graph
LR <- ggplot(first_join, aes(x = video_time)) +
      geom_line(aes(y = LidarRight), color="black") +
      geom_point(aes(y = LidarRight),size = 0.5, color="red")  +      
      ylim(c(0,9000))  + 
      scale_x_datetime(breaks=date_breaks("30 sec"), labels=date_format("%H:%M:%S")) +      
      theme_bw() + theme(legend.text=element_text(size=15)) + ylab(label="Distance (cm)") + 
      xlab("Dummy Time (x200ms)")  + ggtitle("Lidar Right (Raw Data)") 

LL <- ggplot(first_join, aes(x = video_time)) +
      geom_line(aes(y = LidarLeft), color="black") +
      geom_point(aes(y = LidarLeft),size = 0.5, color="red")  +       
      ylim(c(0,9000))  + 
      scale_x_datetime(breaks=date_breaks("10 sec"), labels=date_format("%H:%M:%S")) +
      theme_bw() + theme(legend.text=element_text(size=15)) + ylab(label="Distance (cm)") + 
      xlab("Dummy Time (x200ms)")  + ggtitle("Lidar Left (Raw Data)")

multiplot(LR, LL, cols=1)

# Close-up
LR <- ggplot(first_join[c(500:550),], aes(x = id)) +
      geom_line(aes(y = LidarRight), color="black") +
      geom_point(aes(y = LidarRight),size = 0.5, color="red")  + 
      geom_line(aes(y=100*(speed)), color="blue") + 
      geom_point(aes(y=100*(speed)),size = 0.5, color="blue")  +
      ylim(c(0,3000))  + 
#       scale_x_datetime(breaks=date_breaks("30 sec"), labels=date_format("%H:%M:%S")) +      
      theme_bw() + theme(legend.text=element_text(size=15)) + ylab(label="Distance (cm)") + 
      xlab("Dummy Time (x200ms)")  + ggtitle("Lidar Right (Raw Data)") 

LL <- ggplot(first_join[c(500:550),], aes(x = id)) +
      geom_line(aes(y = LidarLeft), color="black") +
      geom_point(aes(y = LidarLeft),size = 0.5, color="red")  + 
      geom_line(aes(y=100*(speed)), color="blue") + 
      geom_point(aes(y=100*(speed)),size = 0.5, color="blue")  +
      ylim(c(0,3000))  + 
#       scale_x_datetime(breaks=date_breaks("10 sec"), labels=date_format("%H:%M:%S")) +
      theme_bw() + theme(legend.text=element_text(size=15)) + ylab(label="Distance (cm)") + 
      xlab("Dummy Time (x200ms)")  + ggtitle("Lidar Left (Raw Data)")

multiplot(LR, LL, cols=1)

```

# Time domain to Distance domain (Value-lagging)
```{r}
first_join$dist <- 0
time_interval <- 0.2994975 #seconds

# distance intervals (just for reference)
dists <- as.vector(c(0))

for (i in c(1:nrow(first_join))){
  if (i==nrow(first_join)) break
  sp <- first_join[i,]$speed * 0.514444444 # changing the speed to meters/sec
  first_join[i+1,]$dist <- first_join[i,]$dist + (sp * time_interval)
  dists[i] <- (sp * time_interval)
}

d <- density(dists)
plot(d, main="Kernel Density of Distances per Lidar Reading")
polygon(d, col="violet")

#Distance-based plot
LR <- ggplot(first_join, aes(x = dist)) +
      geom_line(aes(y = LidarRight), color="black") +
      geom_point(aes(y = LidarRight),size = 0.5, color="red")  +      
      ylim(c(0,9000))  +       
      scale_x_continuous(breaks =seq(0, 1550, 50)) + 
      theme_bw() + theme(legend.text=element_text(size=15)) + ylab(label="Lidar Distance (cm)") + 
      xlab("Distance Traveled (m)")  + ggtitle("Lidar Right (Distance-based)") 

LL <- ggplot(first_join, aes(x = dist)) +
      geom_line(aes(y = LidarLeft), color="black") +
      geom_point(aes(y = LidarLeft),size = 0.5, color="red")  +       
      ylim(c(0,9000))  +       
      scale_x_continuous(breaks = seq(0, 1550, 50)) + 
      theme_bw() + theme(legend.text=element_text(size=15)) + ylab(label="Lidar Distance (cm)") + 
      xlab("Distance Traveled (m)")  + ggtitle("Lidar Left (Distance-based)")

multiplot(LR, LL, cols=1)

# Close-up
LR <- ggplot(first_join[c(600:650),], aes(x = dist)) +
      geom_line(aes(y = LidarRight), color="black") +
      geom_point(aes(y = LidarRight),size = 1, color="red")  +      
      ylim(c(0,2900))  +       
      scale_x_continuous(breaks =seq(775, 835, 5)) + 
      theme_bw() + theme(legend.text=element_text(size=15)) + ylab(label="Lidar Distance (cm)") + 
      xlab("Distance Traveled (m)")  + ggtitle("Lidar Right (Distance-based), Close-up") 

LL <- ggplot(first_join[c(600:650),], aes(x = dist)) +
      geom_line(aes(y = LidarLeft), color="black") +
      geom_point(aes(y = LidarLeft),size = 1, color="red")  +       
      ylim(c(0,2900))  +       
      scale_x_continuous(breaks = seq(775, 835, 5)) + 
      theme_bw() + theme(legend.text=element_text(size=15)) + ylab(label="Lidar Distance (cm)") + 
      xlab("Distance Traveled (m)")  + ggtitle("Lidar Left (Distance-based), Close-up")

multiplot(LR, LL, cols=1)

# Saving the first_join
write.table(first_join, "220717_first_part_distance_based.csv", row.names=F, col.names=T, sep=",")

```

# Naive Interpolation
```{r}

gps <- read_delim("220717_first_part_distance_based.csv", delim = ",", col_names = T)
first_join$way <- as.factor(first_join$way)

prevL <- 0
prevR <- 0

first_join$adjustedLidarLeft <- 0
first_join$adjustedLidarRight <- 0

for (i in c(1:nrow(first_join))){
  if (i==1){
    prevL <- first_join[i,]$LidarLeft
    prevR <- first_join[i,]$LidarRight
    first_join[i,]$adjustedLidarLeft <- prevL
    first_join[i,]$adjustedLidarRight <- prevR
    next
  }
  
  if (first_join[i,]$LidarLeft <= 1) {
    first_join[i,]$adjustedLidarLeft <- prevL    
  } else {    
    prevL <- first_join[i,]$LidarLeft
    first_join[i,]$adjustedLidarLeft <- prevL
  }
  
  if (first_join[i,]$LidarRight <= 1){
    first_join[i,]$adjustedLidarRight <- prevR
  } else {
    prevR <- first_join[i,]$LidarRight
    first_join[i,]$adjustedLidarRight <- prevR
  }
  
}

#Distance-based plot
LR <- ggplot(first_join, aes(x = dist)) +
      geom_line(aes(y = LidarRight), color="black") +
      geom_point(aes(y = LidarRight),size = 0.5, color="red")  +      
      geom_line(aes(y = adjustedLidarRight), color="blue") +
      geom_point(aes(y = adjustedLidarRight), size = 0.5, color="blue")  +   
      ylim(c(0,9000))  +       
      scale_x_continuous(breaks =seq(0, 1550, 50)) + 
      theme_bw() + theme(legend.text=element_text(size=15)) + ylab(label="Lidar Distance (cm)") + 
      xlab("Distance Traveled (m)")  + ggtitle("Lidar Right (Distance-based)") 

LL <- ggplot(first_join, aes(x = dist)) +
      geom_line(aes(y = LidarLeft), color="black") +
      geom_point(aes(y = LidarLeft),size = 0.5, color="red")  +    
      geom_line(aes(y = adjustedLidarLeft), color="blue") +
      geom_point(aes(y = adjustedLidarLeft), size = 0.5, color="blue")  +  
      ylim(c(0,9000))  +       
      scale_x_continuous(breaks = seq(0, 1550, 50)) + 
      theme_bw() + theme(legend.text=element_text(size=15)) + ylab(label="Lidar Distance (cm)") + 
      xlab("Distance Traveled (m)")  + ggtitle("Lidar Left (Distance-based)")

multiplot(LR, LL, cols=1)

# Close-up (car passing-by)
LR <- ggplot(first_join[c(370:410),], aes(x = dist)) +
      geom_line(aes(y = LidarRight), color="black") +
      geom_point(aes(y = LidarRight),size = 2, color="red")  +  
      geom_line(aes(y = adjustedLidarRight), color="blue") +
      geom_point(aes(y = adjustedLidarRight), size = 1, color="blue")  +   
      ylim(c(0,3200))  +       
      scale_x_continuous(breaks =seq(360, 510, 5)) + 
      theme_bw() + theme(legend.text=element_text(size=15)) + ylab(label="Lidar Distance (cm)") + 
      xlab("Distance Traveled (m)")  + ggtitle("Lidar Right (Distance-based), Close-up") 

LL <- ggplot(first_join[c(370:410),], aes(x = dist)) +
      geom_line(aes(y = LidarLeft), color="black") +
      geom_point(aes(y = LidarLeft),size = 2, color="red")  +   
      geom_line(aes(y = adjustedLidarLeft), color="blue") +
      geom_point(aes(y = adjustedLidarLeft), size = 1, color="blue")  +  
      ylim(c(0,3200))  +       
      scale_x_continuous(breaks = seq(360, 510, 5)) + 
      theme_bw() + theme(legend.text=element_text(size=15)) + ylab(label="Lidar Distance (cm)") + 
      xlab("Distance Traveled (m)")  + ggtitle("Lidar Left (Distance-based), Close-up")

multiplot(LR, LL, cols=1)

write.table(first_join, "220717_first_part_interpolated_lidars.csv", row.names=F, col.names=T, sep=",")
```

# Resampling: Adjusting data points into the regular grid (1m)
```{r}
# Given the median value of distances per lidar reading (=1.29 m), we set 1m as a unit to generate a regular-grid distance-based data
first_regular_dist <- as.data.frame(matrix(ncol=16, nrow = as.integer(max(first_join$dist))))
colnames(first_regular_dist) <- c("dist", "LidarLeft", "LidarRight", "time", "video_time", "USLeft", "USRight", "USRear", "CO", "SO", "NO", "O3", "P10", "P25", "lon", "lat")
first_regular_dist$video_time <- as.POSIXct(first_regular_dist$video_time)
attr(first_regular_dist$video_time, "tzone") <- "UTC"
first_regular_dist$time <- as.POSIXct(first_regular_dist$time)
attr(first_regular_dist$time, "tzone") <- "UTC"
resolution <- 10

for (i in c(1:nrow(first_regular_dist))){    
  print(i)
  if (max(first_join$dist) < i-1) {
    break
  }
  first_regular_dist[i,]$dist <- i - 1  
  index <- which.min(abs(first_join$dist - i + 1))
  
  if (first_join[index,]$dist <= i-1) {
    lidar_left <- (((i - 1 - first_join[index,]$dist)*(first_join[index+1,]$adjustedLidarLeft - first_join[index,]$adjustedLidarLeft)) / (first_join[index+1,]$dist - first_join[index,]$dist)) + first_join[index,]$adjustedLidarLeft
    lidar_right <- (((i - 1 - first_join[index,]$dist)*(first_join[index+1,]$adjustedLidarRight - first_join[index,]$adjustedLidarRight)) / (first_join[index+1,]$dist - first_join[index,]$dist)) + first_join[index,]$adjustedLidarRight    
    us_left <- (((i - 1 - first_join[index,]$dist)*(first_join[index+1,]$USLeft - first_join[index,]$USLeft)) / (first_join[index+1,]$dist - first_join[index,]$dist)) + first_join[index,]$USLeft
    us_right <- (((i - 1 - first_join[index,]$dist)*(first_join[index+1,]$USRight - first_join[index,]$USRight)) / (first_join[index+1,]$dist - first_join[index,]$dist)) + first_join[index,]$USRight
    us_rear <- (((i - 1 - first_join[index,]$dist)*(first_join[index+1,]$USRear - first_join[index,]$USRear)) / (first_join[index+1,]$dist - first_join[index,]$dist)) + first_join[index,]$USRear
    
    dist_rate <- resolution * (i - 1 - first_join[index,]$dist) / (first_join[index+1,]$dist - first_join[index,]$dist)
    dist_rate <- as.integer(dist_rate)
    points <- gcIntermediate(first_join[index,c("lon","lat")], first_join[index+1,c("lon","lat")], resolution-1)
        
    if (dist_rate == 0 | nrow(points) == 1){
      first_regular_dist[i,]$lat <- first_join[index,]$lat
      first_regular_dist[i,]$lon <- first_join[index,]$lon
    } else if (dist_rate == resolution) {
      first_regular_dist[i,]$lat <- first_join[index+1,]$lat
      first_regular_dist[i,]$lon <- first_join[index+1,]$lon
    } else {      
      first_regular_dist[i,]$lat <- points[dist_rate,2]
      first_regular_dist[i,]$lon <- points[dist_rate,1]
    }    
    
  } else {
    lidar_left <- (((i - 1 - first_join[index-1,]$dist)*(first_join[index,]$adjustedLidarLeft - first_join[index-1,]$adjustedLidarLeft)) / (first_join[index,]$dist - first_join[index-1,]$dist)) + first_join[index-1,]$adjustedLidarLeft
    lidar_right <- (((i - 1 - first_join[index-1,]$dist)*(first_join[index,]$adjustedLidarRight - first_join[index-1,]$adjustedLidarRight)) / (first_join[index,]$dist - first_join[index-1,]$dist)) + first_join[index-1,]$adjustedLidarRight
    us_left <- (((i - 1 - first_join[index-1,]$dist)*(first_join[index,]$USLeft - first_join[index-1,]$USLeft)) / (first_join[index,]$dist - first_join[index-1,]$dist)) + first_join[index-1,]$USLeft
    us_right <- (((i - 1 - first_join[index-1,]$dist)*(first_join[index,]$USRight - first_join[index-1,]$USRight)) / (first_join[index,]$dist - first_join[index-1,]$dist)) + first_join[index-1,]$USRight
    us_rear <- (((i - 1 - first_join[index-1,]$dist)*(first_join[index,]$USRear - first_join[index-1,]$USRear)) / (first_join[index,]$dist - first_join[index-1,]$dist)) + first_join[index-1,]$USRear
    
    dist_rate <- resolution * (i - 1 - first_join[index-1,]$dist) / (first_join[index,]$dist - first_join[index-1,]$dist)
    dist_rate <- as.integer(dist_rate)    
    points <- gcIntermediate(first_join[index-1,c("lon","lat")], first_join[index,c("lon","lat")], resolution-1)
    
    if (dist_rate == 0 | nrow(points) == 1){
      first_regular_dist[i,]$lat <- first_join[index-1,]$lat
      first_regular_dist[i,]$lon <- first_join[index-1,]$lon
    } else if (dist_rate == resolution) {
      first_regular_dist[i,]$lat <- first_join[index,]$lat
      first_regular_dist[i,]$lon <- first_join[index,]$lon
    } else {      
      first_regular_dist[i,]$lat <- points[dist_rate,2]
      first_regular_dist[i,]$lon <- points[dist_rate,1]
    }
  }
  
  first_regular_dist[i,]$LidarLeft <- lidar_left
  first_regular_dist[i,]$LidarRight <- lidar_right    
  first_regular_dist[i,]$USLeft <- us_left
  first_regular_dist[i,]$USRight <- us_right
  first_regular_dist[i,]$USRear <- us_rear
  first_regular_dist[i,]$CO <- first_join[index,]$CO  
  first_regular_dist[i,]$SO <- first_join[index,]$SO  
  first_regular_dist[i,]$O3 <- first_join[index,]$O3  
  first_regular_dist[i,]$NO <- first_join[index,]$NO  
  first_regular_dist[i,]$P10 <- first_join[index,]$P10  
  first_regular_dist[i,]$P25 <- first_join[index,]$P25  
  first_regular_dist[i,]$time <- first_join[index,]$time  
  first_regular_dist[i,]$video_time <- first_join[index,]$video_time
  
}

first_regular_dist <- first_regular_dist[!is.na(first_regular_dist$lon),]

#### gcIntermediate function test
# inter <- gcIntermediate(first_join[27,c("lon","lat")],first_join[28,c("lon","lat")], 10)
# inter <- rbind(first_join[5,c("lon","lat")], inter)
# inter <- rbind(inter, first_join[26,c("lon","lat")])
# inter$id <- c(1:nrow(inter))
# 
# map <- get_map(inter[3,], zoom = 18, source = "stamen", maptype = "toner")
# mapPoints <- ggmap(map) + geom_point(aes(x = lon, y = lat, colour=id ), data = inter, alpha = 0.9, size = 0.5) + ggtitle("gcIntermediate Test")
# mapPoints

# Close-up (random segment)
LR <- ggplot(first_join[c(50:100),], aes(x = dist)) +      
      geom_line(aes(y = adjustedLidarRight), color="black") +
      geom_point(aes(y = adjustedLidarRight), size = 1, color="red")  +         
      ylim(c(0,2600))  +       
      scale_x_continuous(breaks =seq(0, 60, 1)) + 
      theme_bw() + theme(legend.text=element_text(size=15)) + ylab(label="Lidar Distance (cm)") + 
      xlab("Distance Traveled (m)")  + ggtitle("Lidar Right (Distance-based), Close-up") 

LL <- ggplot(first_regular_dist[c(7:58),], aes(x = dist)) +      
      geom_line(aes(y = LidarRight), color="black") +
      geom_point(aes(y = LidarRight), size = 1, color="red")  +        
      ylim(c(0,2600))  +       
      scale_x_continuous(breaks = seq(0, 60, 1)) + 
      theme_bw() + theme(legend.text=element_text(size=15)) + ylab(label="Lidar Distance (cm)") + 
      xlab("Distance Traveled (m)")  + ggtitle("Lidar Right (Re-sampled), Close-up")

multiplot(LR, LL, cols=1)
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

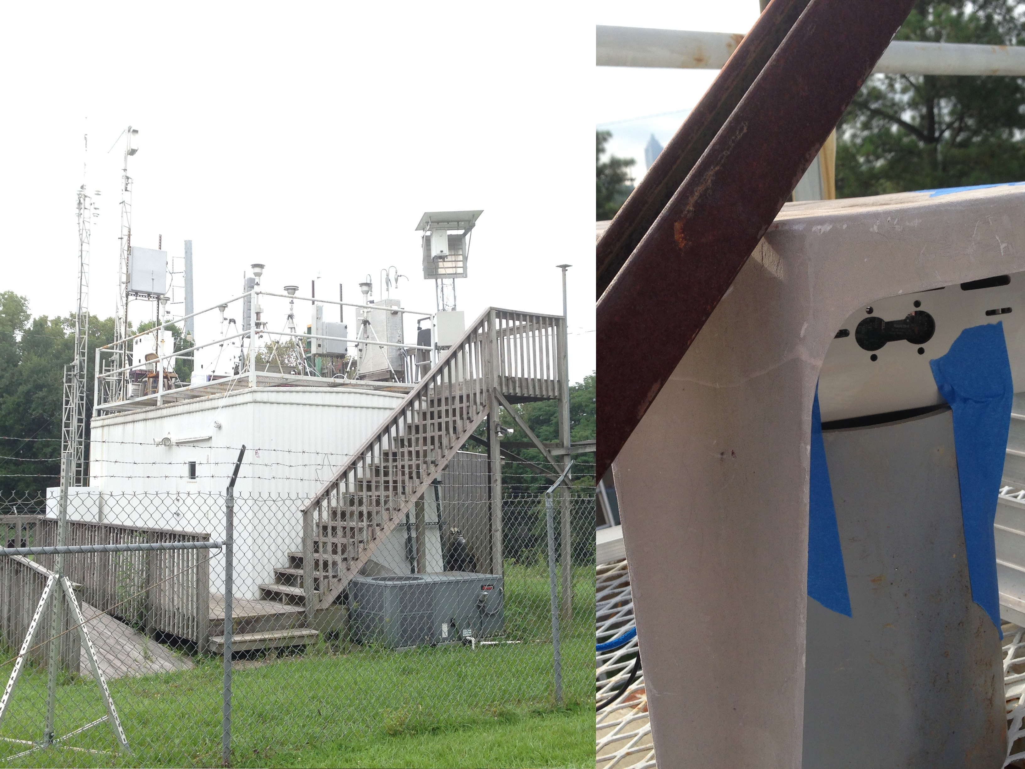
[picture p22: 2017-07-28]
images/gas_cali.jpg

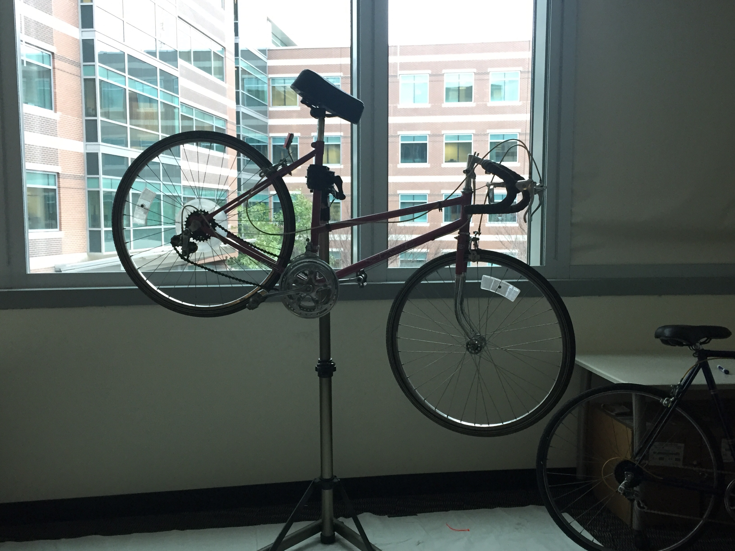
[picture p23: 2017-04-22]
images/Bike in class.jpg

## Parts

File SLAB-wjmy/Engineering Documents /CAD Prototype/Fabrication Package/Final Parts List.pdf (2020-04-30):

We Just Met Yesterday
Parts List

Drawing and Fabrication Package 4.21.20

Part No. | Description | Quantity | Vender - with links | Unit Price | Total Cost | Found in Dwg. No
A-1 | Full Bike Assembly | 1 | - | $ 775.41 | $ 775.41 | A-1
A-2 | Sensor Package Prototype V1 | 1 | WJMY | $ | - | $ | - | A-2
P-1 | Box Top Half (75895K14) | 1 | McMaster (https://www.mcmaster.com/75895k14) | $ | 90.44 | $ | 90.44 | A-2, P-1
P-2 | Box Bottom Half (75895K14) | 1 | McMaster (https://www.mcmaster.com/75895k14) | $ | - | $ | - | A-2, P-2
P-3 | Custom PCB | 1 | WJMY/Electronics Shop | $ | - | $ | - | A-2. P-3
O-1 | Generic Bike | 1 | SLAB Lab | $ | - | $ | - | A-1
O-2 | Generic Pannier Rack for Bike | 1 | SLAB Lab | $ | - | $ | - | A-1
O-3 | Generic Phone Handlebar Mount
| for Bikes | 1 | TBD | $ | - | $ | - | A-1
O-4 | iPhone X | 1 | SLAB Lab | $ | - | $ | - | A-1
O-5 | Garmin LIDAR Lite-3 Sensor | 4 | Garmin / SLAB Lab | $ 129.99 | $ 519.96 | A-2
O-6 | 6-32 1" Screw (91735A154) | 16 | McMaster (https://www.mcmaster.com/91735a154) | $ | 0.46 | $ | 7.39 | A-2
O-7 | 6-32 1" Nut (91813A130) | 16 | McMaster (https://www.mcmaster.com/91813a130) | $ | 0.64 | $ | 10.29 | A-2
O-8 | Raspberry Pi 3Bv1.2 | 1 | SLAB Lab | $ | 24.99 | $ | 24.99 | A-2
O-9 | Size 3 Washer (90107A004) | 16 | McMaster (https://www.mcmaster.com/90107a004) | $ | 0.18 | $ | 2.82 | A-2
O-10 | Size 4 Unthreaded Space
| (92510A385) | 4 | McMaster (https://www.mcmaster.com/92510a385) | $ | 0.94 | $ | 3.76 | A-2
O-11 | 3-48 Screw (91772A096) | 4 | McMaster (https://www.mcmaster.com/91772a096) | $ | 2.44 | $ | 9.77 | A-2
O-12 | 3-48 Nut (91841A004) | 4 | McMaster (https://www.mcmaster.com/91841a004) | $ | 0.80 | $ | 3.20 | A-2
O-13 | Arduino uno | 1 | SLAB Lab | $ | 22.00 | $ | 22.00 | A-2
O-14 | Battery Pack | 1 | XTPower via Amazon (https://www.amazon.com/XTPower-MP-10000-External-Battery-10000mAh/dp/B00935L44E) | $ | 64.99 | $ | 64.99 | A-2
O-15 | 1/4"-20 304 Stainless U-Bolt | 4 | McMaster (https://www.mcmaster.com/8896t103) | $ | 2.73 | $ | 10.92 | A-2
O-16 | 1/4"-20 Nut (95462A029) | 8 | McMaster (https://www.mcmaster.com/95462a029) | $ | 0.61 | $ | 4.88 | A-2
O-17 | Toggle Switch (7343K185) | 1 | McMaster (https://www.mcmaster.com/catalog/126/1000/) | $ | 4.88 | $ | 4.88 | A-2

Key
A - Assembly
P - Part, custom designed
O - Other part, standard

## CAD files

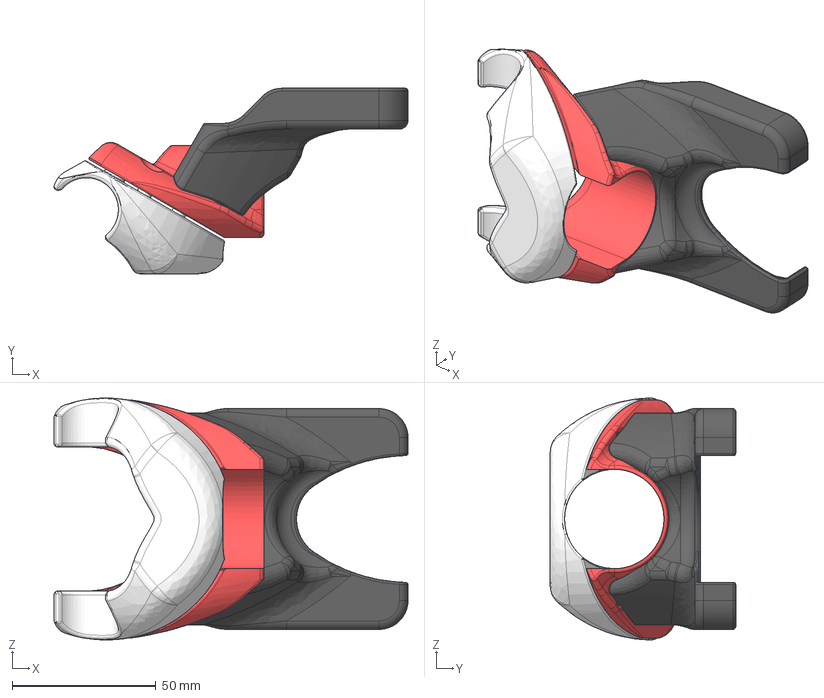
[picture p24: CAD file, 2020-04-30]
SLAB-wjmy/Engineering Documents /CAD Prototype/bike phone mount/Prototype 01 Assembly.stp
123.0 x 64.4 x 83.9 mm
Prototype 01 - Base
ISO 4762 M5 x 12 x 2
ISO 4762 M5 x 20 x 2
ISO 4032 M5 x 4
Prototype 01 - Clamp
Prototype 01 - Smartphone Holder

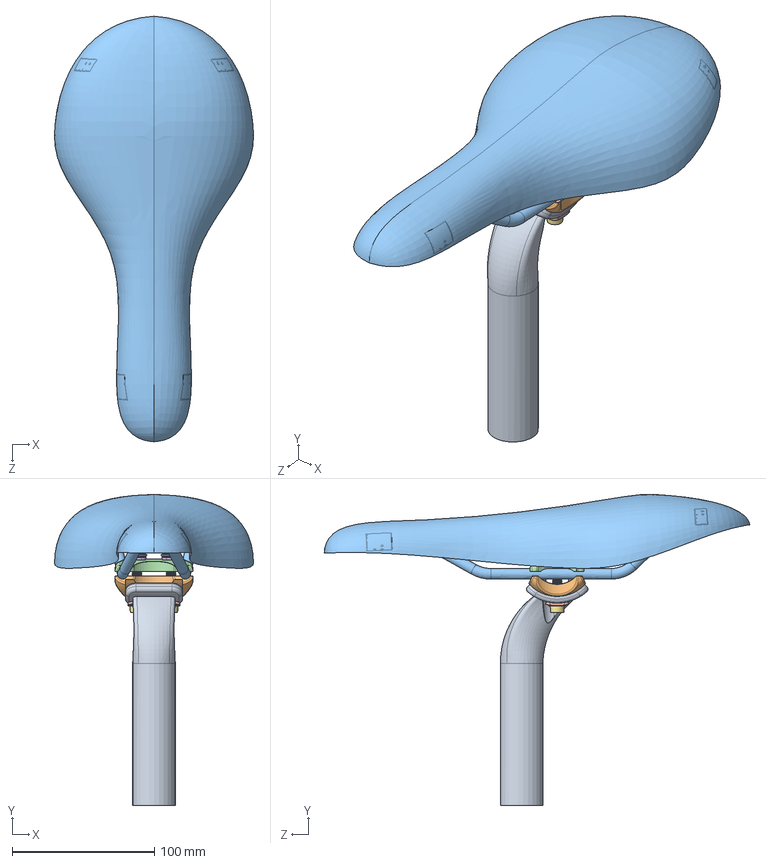
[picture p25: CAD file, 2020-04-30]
SLAB-wjmy/Engineering Documents /CAD Prototype/Bike_project/Sub_assembly/seat_stand.SLDASM
140.0 x 218.8 x 299.4 mm
stand
seat_cover
upper_part_3
hole_4part x 2
hole_5part x 2
hexalobular socket cheese head_iso x 2
hex flange nut gradea_iso x 2

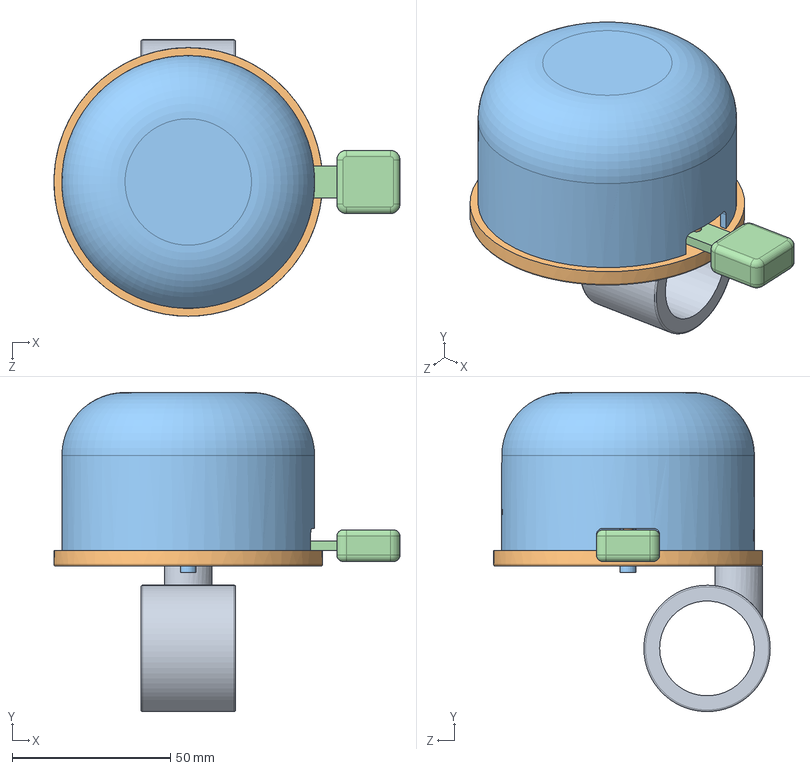
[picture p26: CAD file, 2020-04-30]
SLAB-wjmy/Engineering Documents /CAD Prototype/Bike_project/Sub_assembly/bell_final.SLDASM
109.5 x 101.0 x 87.5 mm
base
plate
bell
lathi

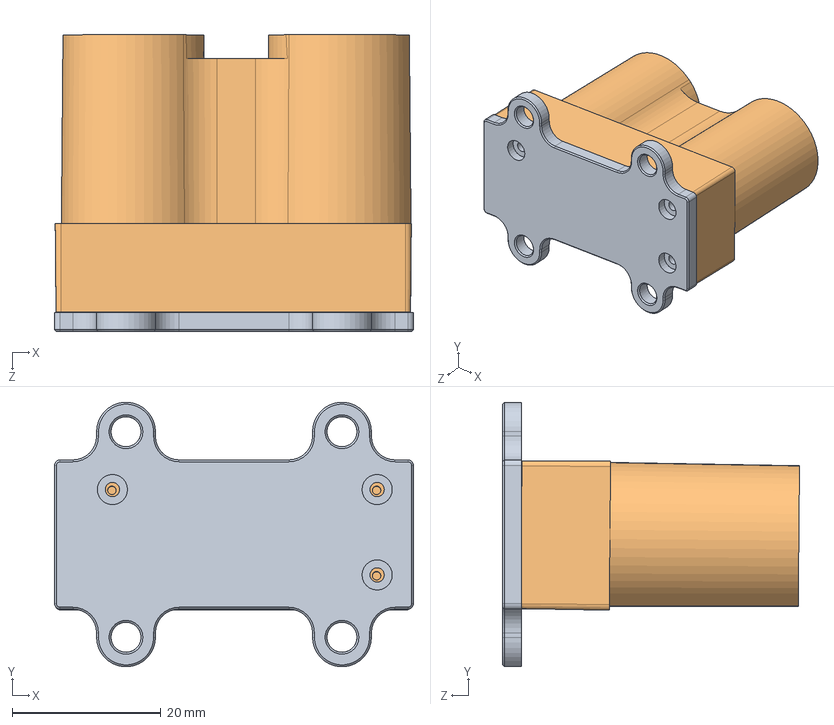
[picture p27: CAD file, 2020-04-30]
SLAB-wjmy/Engineering Documents /CAD Prototype/Package Prototype 1/FULL SIZE Version/LIDAR Lite-3 Assembly.SLDASM
48.3 x 35.5 x 39.9 mm
LIDAR-Lite_Cover_RevC
LIDAR-Lite_Housing_RevD

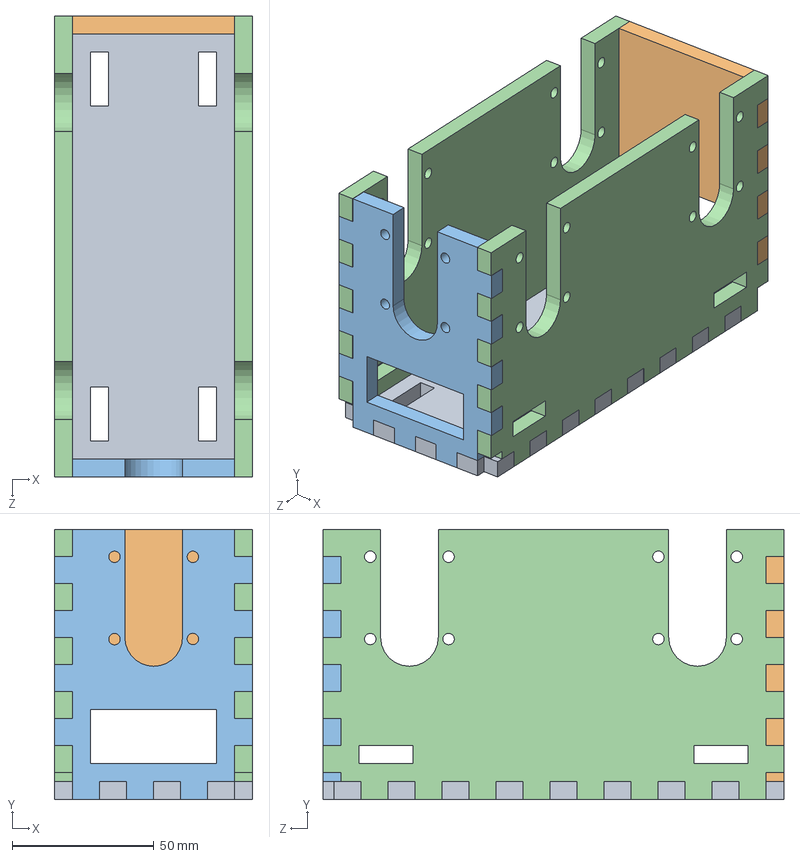
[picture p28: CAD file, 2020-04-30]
SLAB-wjmy/Engineering Documents /CAD Prototype/Package Prototype 1/THIN Version/Package Assembly V1-thin.SLDASM
70.0 x 95.2 x 162.6 mm
Bottom V1-thin
Front V1-thin
Back V1-thin
Side V1-thin x 2

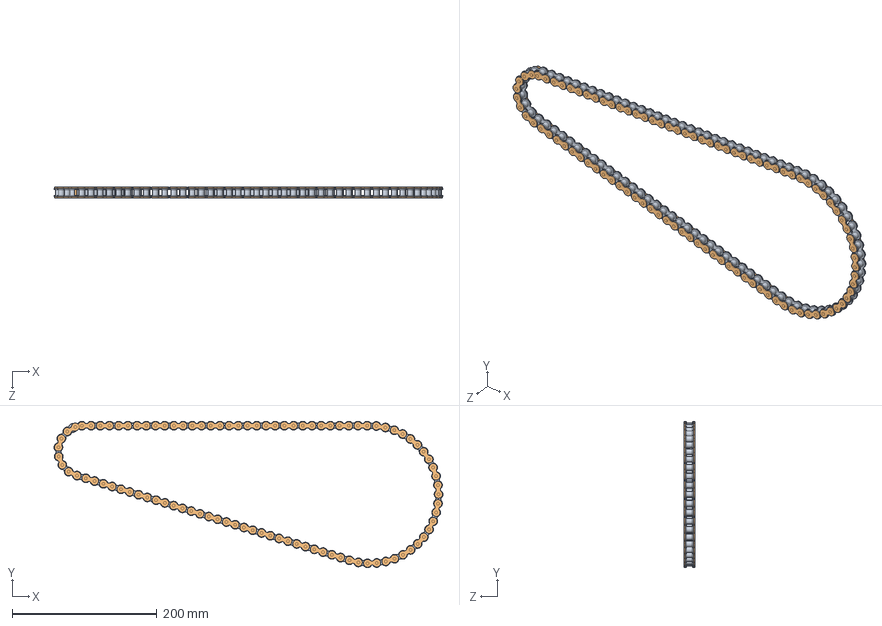
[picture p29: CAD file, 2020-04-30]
SLAB-wjmy/Engineering Documents /CAD Prototype/Bike_project/chain/chain_assembly.SLDASM
536.8 x 202.1 x 15.6 mm
outer_chain x 48
inner_chain x 48

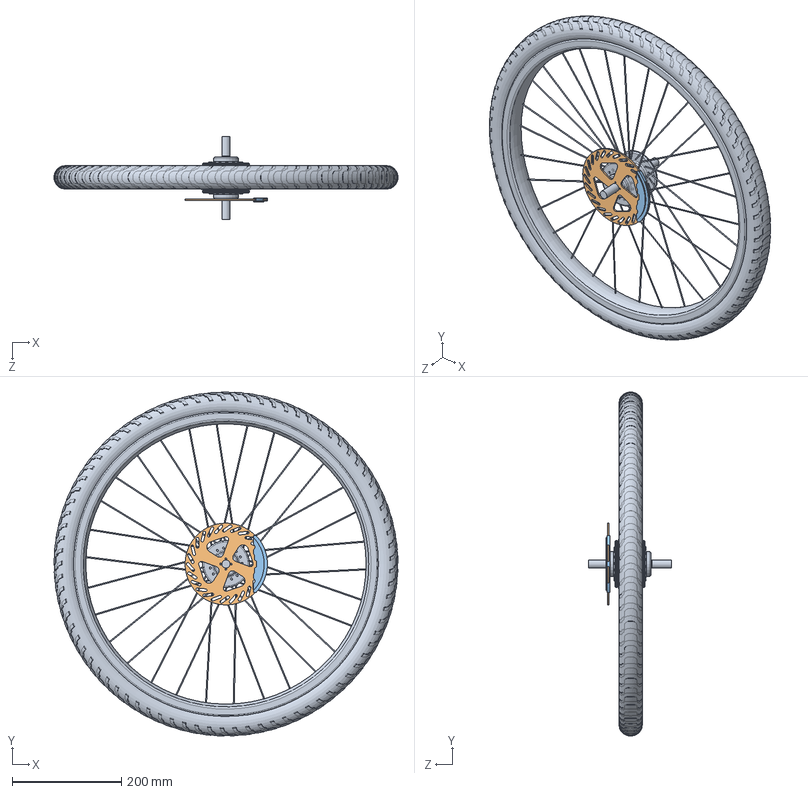
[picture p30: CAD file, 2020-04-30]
SLAB-wjmy/Engineering Documents /CAD Prototype/Bike_project/Sub_assembly/wheal_break assembly_fornt.SLDASM
630.7 x 630.7 x 152.4 mm
final_edited
brake
BreaK_TOP

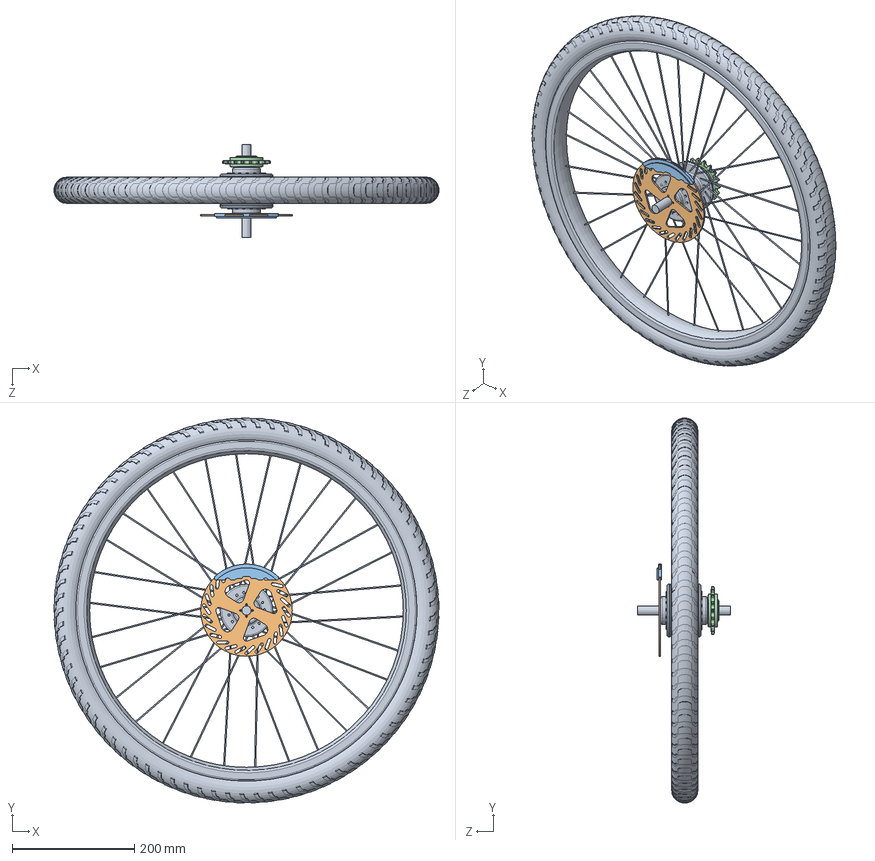
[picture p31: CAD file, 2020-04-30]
SLAB-wjmy/Engineering Documents /CAD Prototype/Bike_project/Sub_assembly/wheal_break assembly_back.SLDASM
630.7 x 630.7 x 152.4 mm
final_edited
brake
BreaK_TOP
Sprocket
spoket_joint

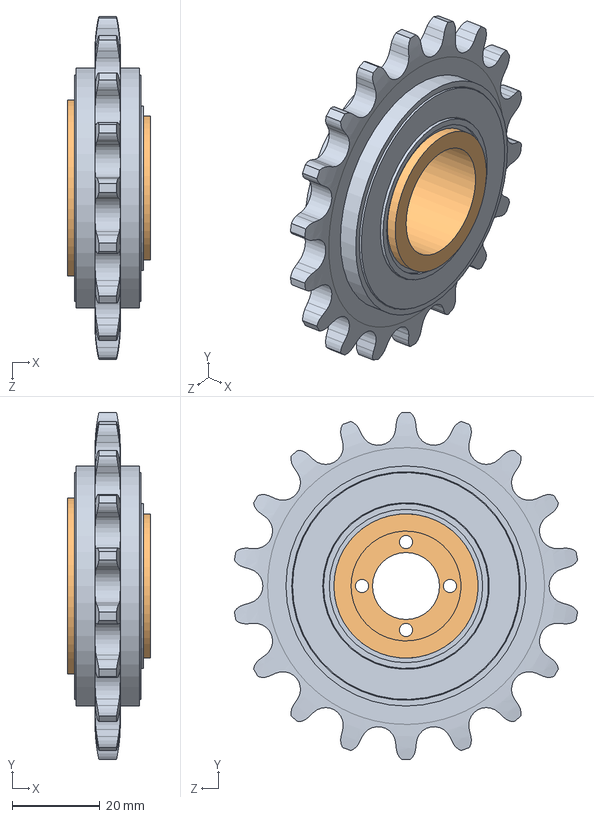
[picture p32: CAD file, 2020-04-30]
SLAB-wjmy/Engineering Documents /CAD Prototype/Bike_project/Sub_assembly/spoket.SLDASM
19.0 x 79.0 x 78.1 mm
Sprocket
spoket_joint

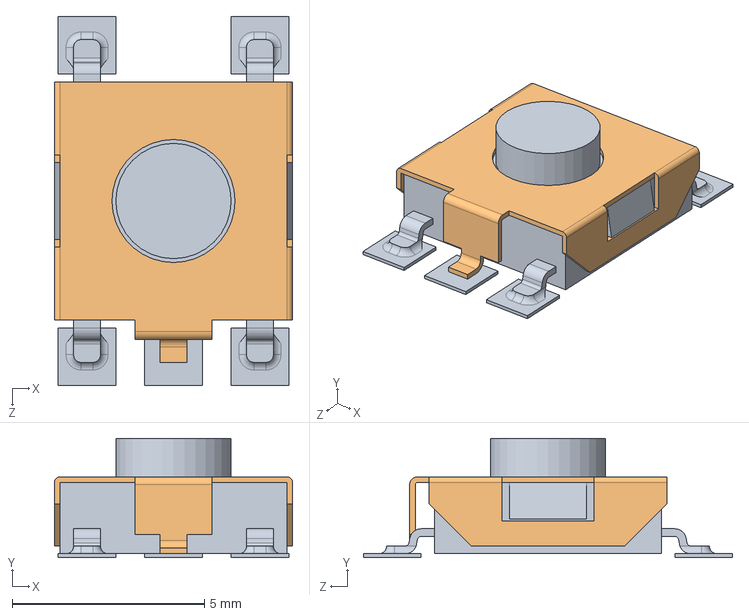
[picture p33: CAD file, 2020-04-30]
SLAB-wjmy/Engineering Documents /CAD Prototype/arduino-uno-r3-1/arduino uno/RESET BUTTON.SLDASM
6.20 x 3.10 x 9.60 mm
RESET CORE
RESET

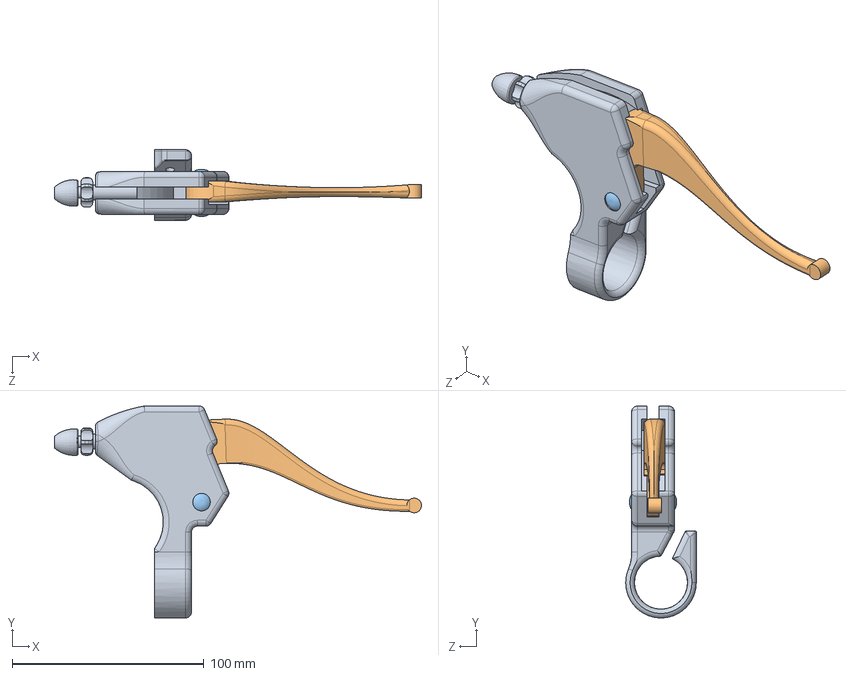
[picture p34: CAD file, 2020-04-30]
SLAB-wjmy/Engineering Documents /CAD Prototype/Bike_project/Sub_assembly/Break_cluause.SLDASM
191.6 x 110.6 x 36.9 mm
Break1
Lever
nut x 2

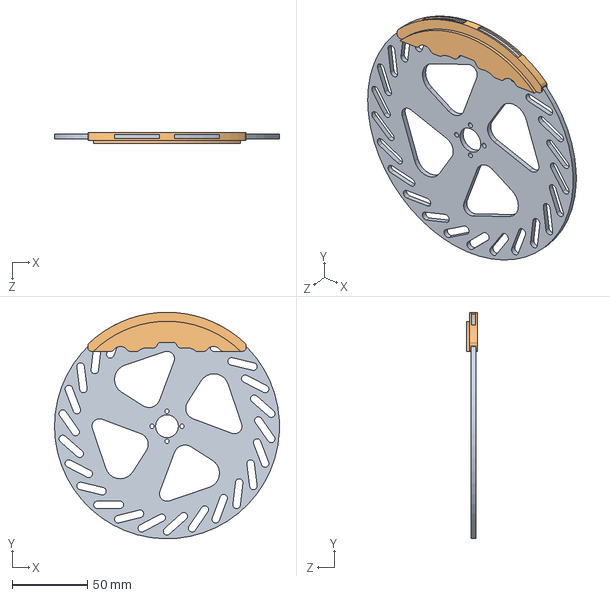
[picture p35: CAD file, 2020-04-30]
SLAB-wjmy/Engineering Documents /CAD Prototype/Bike_project/Sub_assembly/BREAK_assembly.SLDASM
150.0 x 151.0 x 7.00 mm
brake
BreaK_TOP

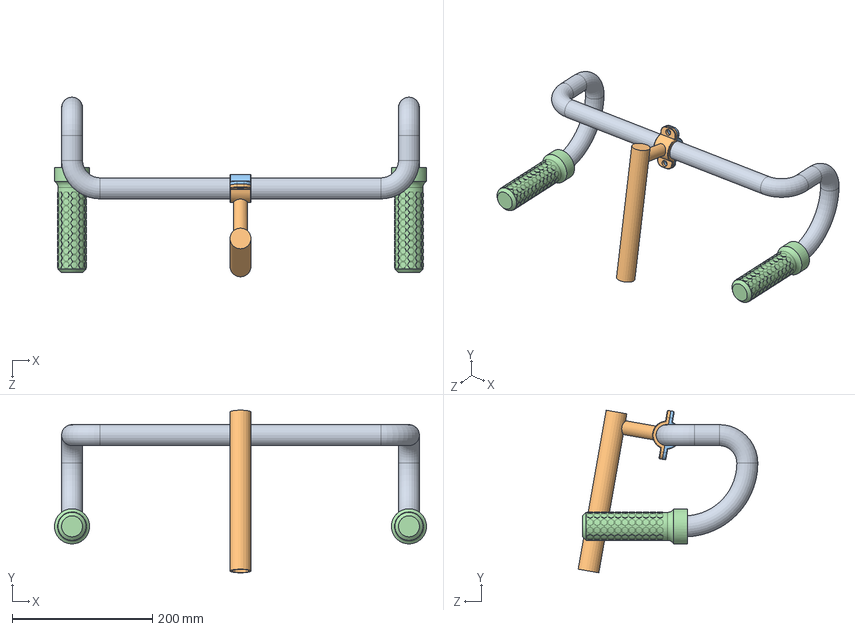
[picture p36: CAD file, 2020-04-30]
SLAB-wjmy/Engineering Documents /CAD Prototype/Bike_project/Sub_assembly/handle.SLDASM
530.0 x 231.7 x 256.1 mm
handle_new_bar
break_parts2
break_parts
griper x 2

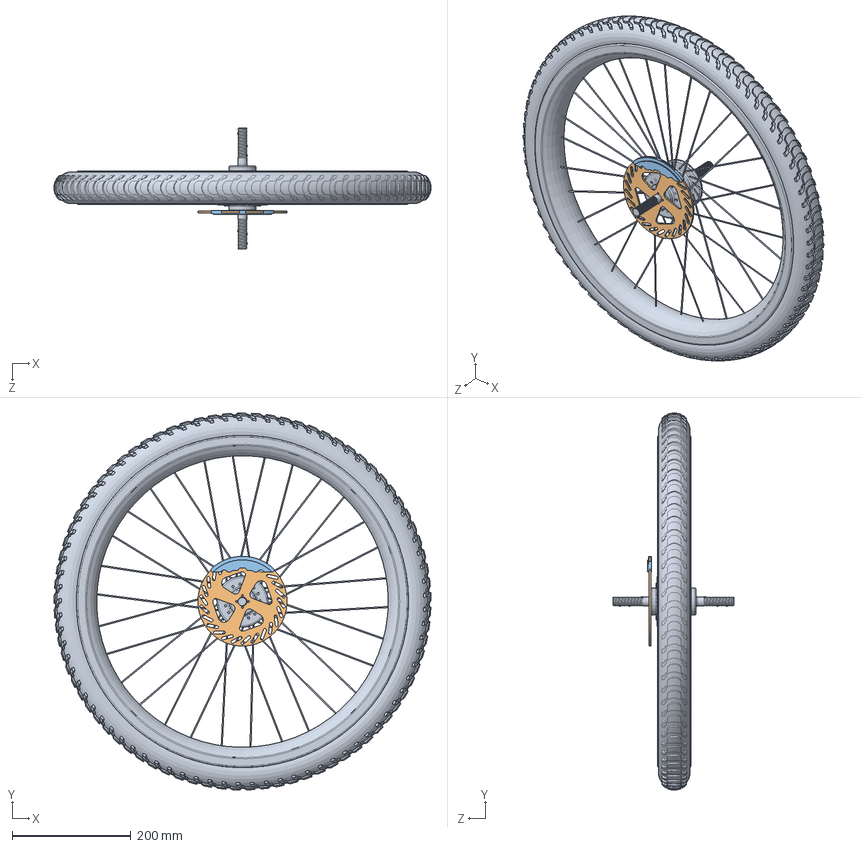
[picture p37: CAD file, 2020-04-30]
SLAB-wjmy/Engineering Documents /CAD Prototype/Bike_project/Project/wheal_break assembly.SLDASM
634.0 x 634.0 x 203.2 mm
_edited
brake
BreaK_TOP

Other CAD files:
SLAB-wjmy/Engineering Documents /CAD Prototype/arduino-uno-r3-1/arduino uno/dip28.SLDASM
SLAB-wjmy/Engineering Documents /CAD Prototype/Bike_project/Project/BREAK_assembly.SLDASM
SLAB-wjmy/Engineering Documents /CAD Prototype/arduino-uno-r3-1/arduino uno/USB type b.SLDPRT.SLDASM
DSSG2017_Case_Design/Back box/00_old wooden versions/BackBox.dxf
DSSG2017_Case_Design/Back box/print ABS box/misc/Box.SLDPRT
DSSG2017_Case_Design/Front box/MatrixBaseMount.SLDPRT
DSSG2017_Case_Design/Front box/MatrixBaseMount.STL
DSSG2017_Case_Design/Front box/MatrixCaseBottom.SLDDRW
DSSG2017_Case_Design/Front box/MatrixCaseBottom.SLDPRT
DSSG2017_Case_Design/Front box/MatrixCaseBottom.STL
DSSG2017_Case_Design/Front box/MatrixCaseTop.SLDDRW
DSSG2017_Case_Design/Front box/MatrixCaseTop.SLDPRT
DSSG2017_Case_Design/Front box/MatrixCaseTop.STL
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

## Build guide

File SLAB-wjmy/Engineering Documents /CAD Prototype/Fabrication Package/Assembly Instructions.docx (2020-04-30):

We Just Met Yesterday

Sensor Package Prototype V3

Assembly Instructions

Box Bottom Half

1) Drawing P-2 provides the annotated drawing for the Box Bottom Half. This Box is an “Aluminum Corrosion-Resistant Washdown Enclosure” from McMaster that will be custom fit to this prototype.
2) If you do not have machining experience, the Montgomery Machining Mall or Makerspace machining staff can provide machining help to cut the necessary slots into the box.

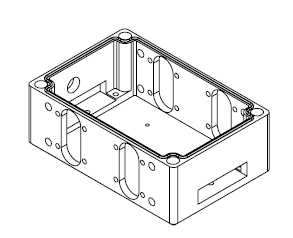
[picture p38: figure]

Fig. 1: Isometric View of Box Bottom Half

Procurement

1) All items can be found in the Parts List at the beginning of the Drawing and Fabrication Package.
2) Links are provided to order them from McMaster or other vendors. Many of these parts are available at Home Depot as well, provided attention is paid to their correct sizes.

PCB

1) Drawing P-3 provides the PCB Board Layout and Schematic Layout. These files are available digitally in the project files.
2) If you do not have prior PCB manufacturing experience, the Electronics Lab (https://www.me.gatech.edu/facilities/electronic_lab), on the first floor of the MRDC, can use the schematic and board layout files to manufacture it for you. You can speak with their engineers in the lab to validate the board, and you can submit it online via the Electronics Lab Technical Request Form (http://electronicslab.me.gatech.edu/request/request.php) for manufacturing.

Box Bottom Half - continued

5) As seen in Fig. 3, these slots have a radius of 0.40” and a length of 1.10” between each circle’s center. Cut these slots, based on their locations in Fig. 3, from both long-sides of the box.

Note: These slots are symmetric, so the length from the left slot’s center to the left side of the box matches the length of the right slot’s center to the right side of the box.

6) Locate the LIDAR mounting holes, located next to the LIDAR slots, as seen in Fig. 4.

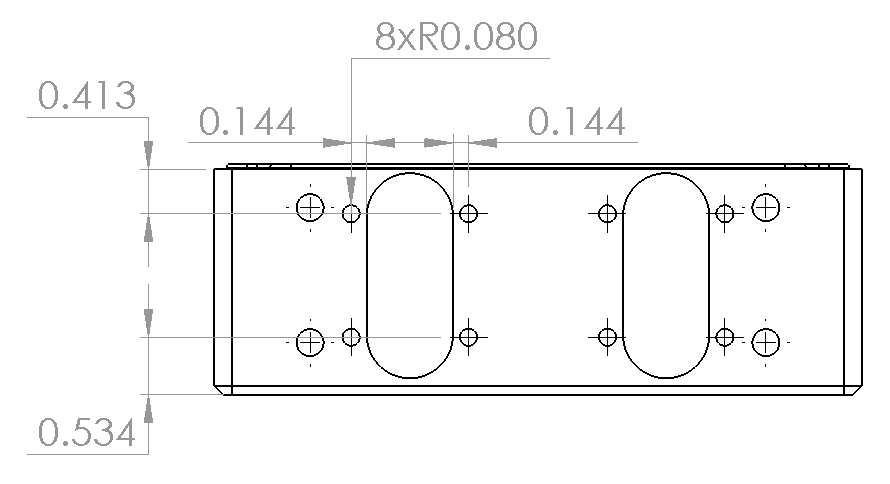
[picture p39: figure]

Fig. 4: Locations of LIDAR Screws

Box Bottom Half - continued

3) Drill 4 holes for Size 4 Screws in the bottom of the box. These will serve as mounts for the Raspberry Pi. The hole locations are found in Fig. 2.

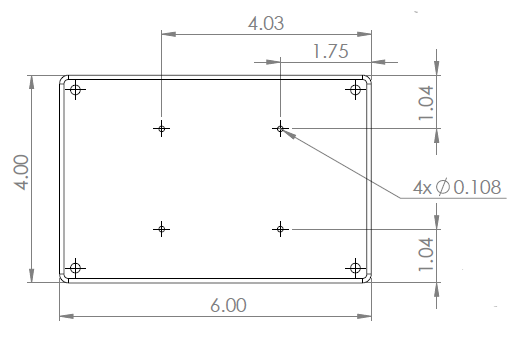
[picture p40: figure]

Fig. 2: Locations of RaspPi Screws

4) Locate the cut locations for the LIDAR slots. These are referenced in Fig. 3 below.

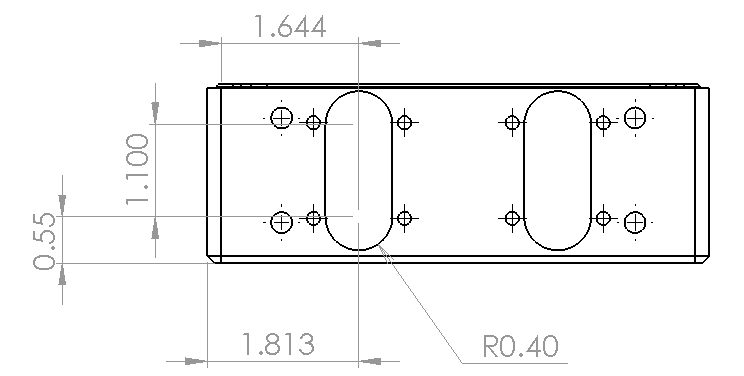
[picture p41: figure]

Fig. 3: LIDAR Slot Locations

Box Bottom Half - continued

13) Select one of the short-sides of the box to be the Back. Either side works as the box is currently symmetrical.
14) Locate the switch hole in Fig. 6.

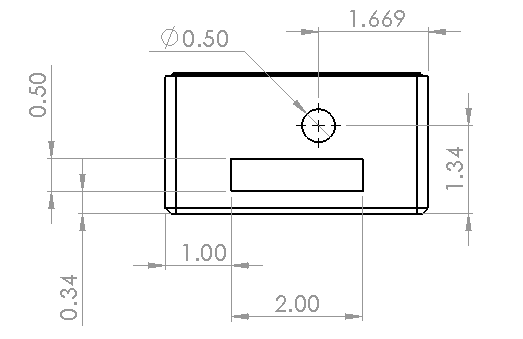
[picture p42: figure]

Fig. 6: Back of Box

15) Drill a 0.50” hole at this location. If a different switch is used, size this hole to that switch.

Recommended: A slot in the Back, shown above, and another in the Front were designed to improve accessibility to wiring inside the box and to promote cooling, if needed. It is recommended to cut these and use plastic sheets to cover when not needed.

Box Bottom Half - continued

9) Drill these LIDAR mounting holes for size 6 screws. Hole diameter of 0.16” is suitable (matching the LIDAR’s hole diameter).
10) Repeat these holes for each LIDAR mount. There should be 16 total holes after this step.
11) Locate the U-bolt mounting holes, detailed in Fig. 5.

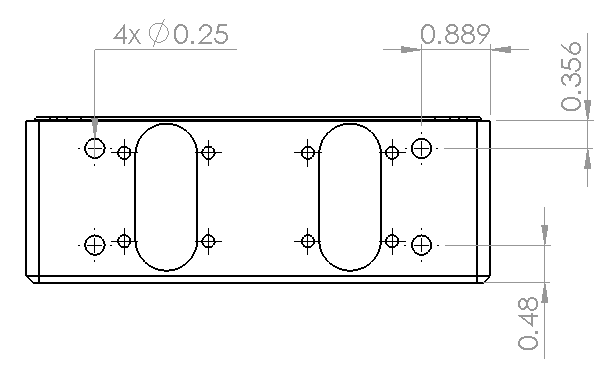
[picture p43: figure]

Fig. 5: Locations of U-bolts

12) Drill 0.25” holes. There should be 8 total.

Box Top Half

3) Orient the box to its Front face. Locate the slot, shown in Fig. 8.

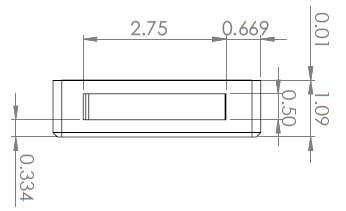
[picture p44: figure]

Fig. 8: Front Face Slot

4) Cut slot into the face. This helps with cooling and is likely necessary to fit the wires leading to the battery.

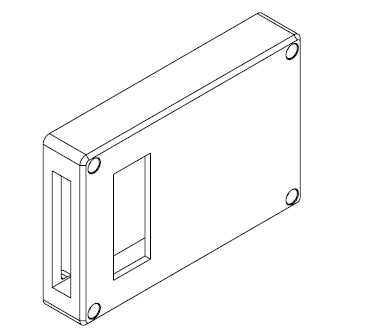
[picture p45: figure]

Fig. 9: Box Top Half

Box Top Half

1) Determine a Front Side of the Top Half. Orient the Box to the Top Face and locate a viewing slot as described in Fig. 7.

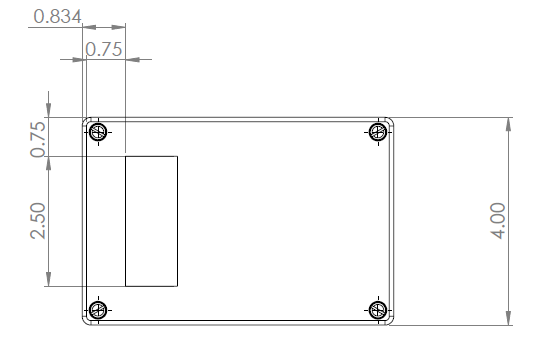
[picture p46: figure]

Fig. 7: Top Viewing Slot

2) Cut viewing slot into the box. This is to monitor the battery’s status when installed. Check where you will place battery before making the cut to make sure it is in the right place. Use a plastic-sheet to seal the window.

Package Assembly - continued

5) Insert the U-bolt into its holes to the outside of the LIDAR.

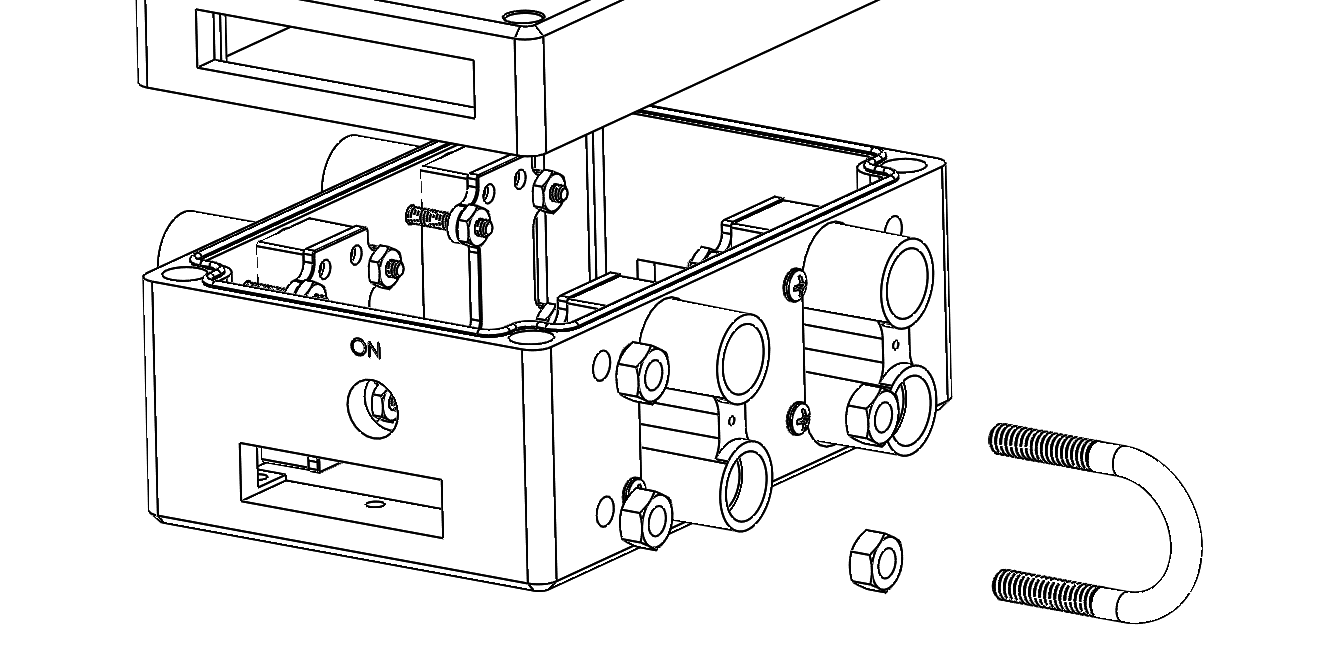
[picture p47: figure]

6) Tighten 2 more nuts (O-16) around the U-bolt inside the box, securing it to the sides.
7) Repeat until all 4 U-bolts are installed.

Package Assembly

1) Insert the LIDAR (O-5) into their slots from inside.
2) Insert screws (O-6) from the outside, running all the way through, and tighten nuts (O-7) around the end.

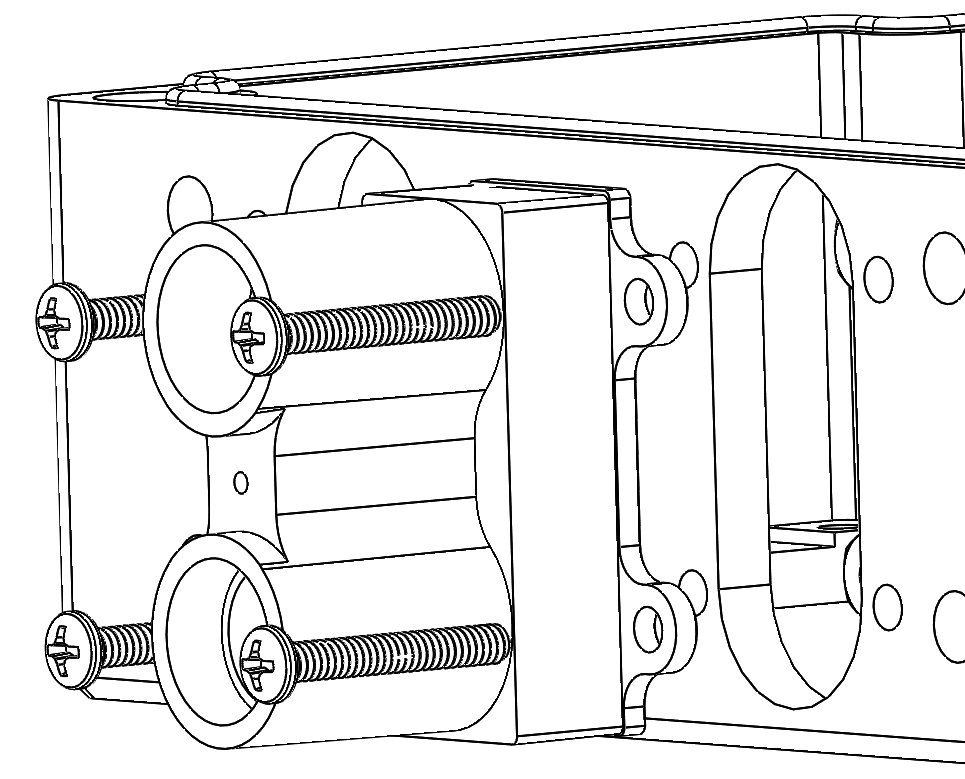
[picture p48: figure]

Note: The excess screw tip may need to be cut shorter to fit the Raspberry Pi in later. Alternatively, the screws can be flipped so that their head is inside the box.

3) Repeat until all 4 LIDAR are installed.
4) Add 2 nuts (O-15) to the U-bolt (O-15), tightening or loosening to extend the U-bolt past the LIDAR.

Package Assembly - continued

9) Tighten the nut and secure the Rasp Pi to the box.
10) Place the PCB (P-3) on the Arduino (O-13). Wire the Arduino to the Rasp Pi. Place the Arduino on top of the Rasp Pi, with a thin plastic sheet between the Pi and any insulation laid between both devices.

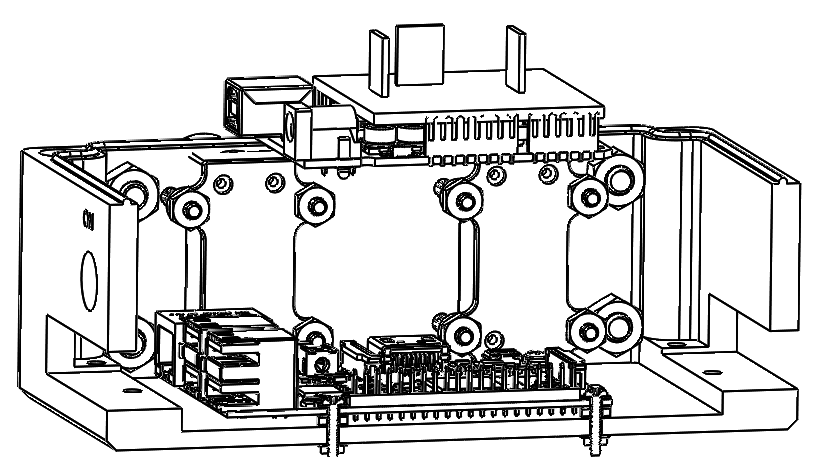
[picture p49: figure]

11) Attach the switch (O-17) to the box.

Package Assembly - continued

8) Prepare to insert the Raspberry Pi (O-8) and secure it with the following parts. From top to bottom, they will attach as follows:
  a. Screw (O-11)
  b. Washer (O-9)
  c. Rasp Pi (O-8)
  d. Washer (O-9)
  e. Spacer (O-10)
  f. Washer (O-9)
  g. Box Bottom (P-2)
  h. Washer (O-9)
  i. Nut (O-12)

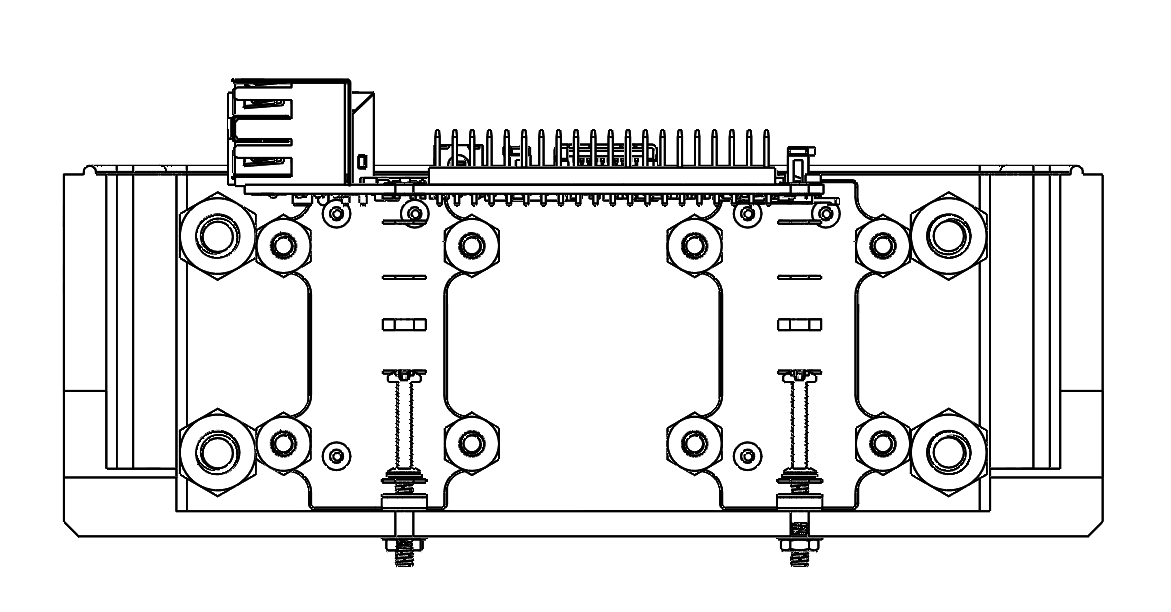
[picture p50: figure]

Package Assembly - continued

11) Attach the switch (O-17) to the box.

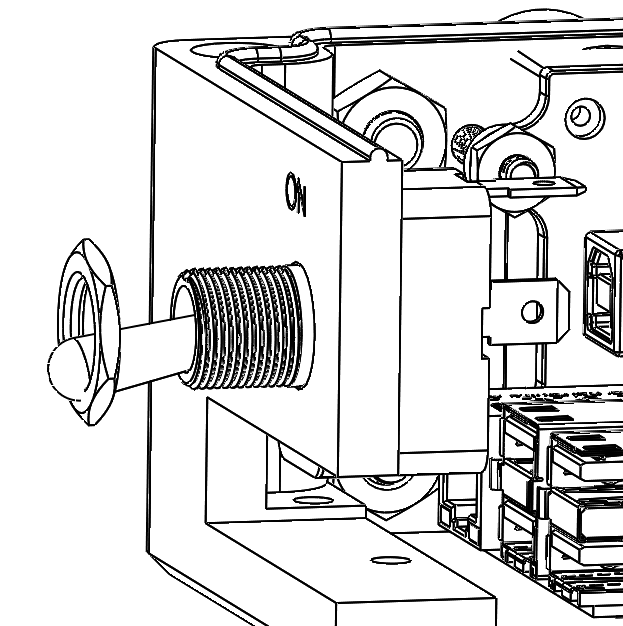
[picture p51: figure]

12) Wire the switch to the PCB.
13) Wire the LIDAR to the PCB.
14) Secure the battery (O-14) with adhesive to the Box Top Half (P-1).

Note: More permanent means can be used on the battery if desired. However, given that it was never tested with the package or orientation, more temporary tape was preferred for now.

15) Wire Battery to the PCB and devices.

We Just Met YesterdayDrawing and Fabrication Package Assembly Instructions 4.22.20

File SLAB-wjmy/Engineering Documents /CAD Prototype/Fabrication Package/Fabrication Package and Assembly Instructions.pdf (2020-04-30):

We Just Met Yesterday
Parts List

Drawing and Fabrication Package 4.21.20

Part No. | Description | Quantity | Vender - with links | Unit Price | Total Cost | Found in Dwg. No
A-1 | Full Bike Assembly | 1 | - | $ 775.41 | $ 775.41 | A-1
A-2 | Sensor Package Prototype V1 | 1 | WJMY | $ | - | $ | - | A-2
P-1 | Box Top Half (75895K14) | 1 | McMaster (https://www.mcmaster.com/75895k14) | $ | 90.44 | $ | 90.44 | A-2, P-1
P-2 | Box Bottom Half (75895K14) | 1 | McMaster (https://www.mcmaster.com/75895k14) | $ | - | $ | - | A-2, P-2
P-3 | Custom PCB | 1 | WJMY/Electronics Shop | $ | - | $ | - | A-2. P-3
O-1 | Generic Bike | 1 | SLAB Lab | $ | - | $ | - | A-1
O-2 | Generic Pannier Rack for Bike | 1 | SLAB Lab | $ | - | $ | - | A-1
O-3 | Generic Phone Handlebar Mount
| for Bikes | 1 | TBD | $ | - | $ | - | A-1
O-4 | iPhone X | 1 | SLAB Lab | $ | - | $ | - | A-1
O-5 | Garmin LIDAR Lite-3 Sensor | 4 | Garmin / SLAB Lab | $ 129.99 | $ 519.96 | A-2
O-6 | 6-32 1" Screw (91735A154) | 16 | McMaster (https://www.mcmaster.com/91735a154) | $ | 0.46 | $ | 7.39 | A-2
O-7 | 6-32 1" Nut (91813A130) | 16 | McMaster (https://www.mcmaster.com/91813a130) | $ | 0.64 | $ | 10.29 | A-2
O-8 | Raspberry Pi 3Bv1.2 | 1 | SLAB Lab | $ | 24.99 | $ | 24.99 | A-2
O-9 | Size 3 Washer (90107A004) | 16 | McMaster (https://www.mcmaster.com/90107a004) | $ | 0.18 | $ | 2.82 | A-2
O-10 | Size 4 Unthreaded Space
| (92510A385) | 4 | McMaster (https://www.mcmaster.com/92510a385) | $ | 0.94 | $ | 3.76 | A-2
O-11 | 3-48 Screw (91772A096) | 4 | McMaster (https://www.mcmaster.com/91772a096) | $ | 2.44 | $ | 9.77 | A-2
O-12 | 3-48 Nut (91841A004) | 4 | McMaster (https://www.mcmaster.com/91841a004) | $ | 0.80 | $ | 3.20 | A-2
O-13 | Arduino uno | 1 | SLAB Lab | $ | 22.00 | $ | 22.00 | A-2
O-14 | Battery Pack | 1 | XTPower via Amazon (https://www.amazon.com/XTPower-MP-10000-External-Battery-10000mAh/dp/B00935L44E) | $ | 64.99 | $ | 64.99 | A-2
O-15 | 1/4"-20 304 Stainless U-Bolt | 4 | McMaster (https://www.mcmaster.com/8896t103) | $ | 2.73 | $ | 10.92 | A-2
O-16 | 1/4"-20 Nut (95462A029) | 8 | McMaster (https://www.mcmaster.com/95462a029) | $ | 0.61 | $ | 4.88 | A-2
O-17 | Toggle Switch (7343K185) | 1 | McMaster (https://www.mcmaster.com/catalog/126/1000/) | $ | 4.88 | $ | 4.88 | A-2

Key
A - Assembly
P - Part, custom designed
O - Other part, standard

B | B

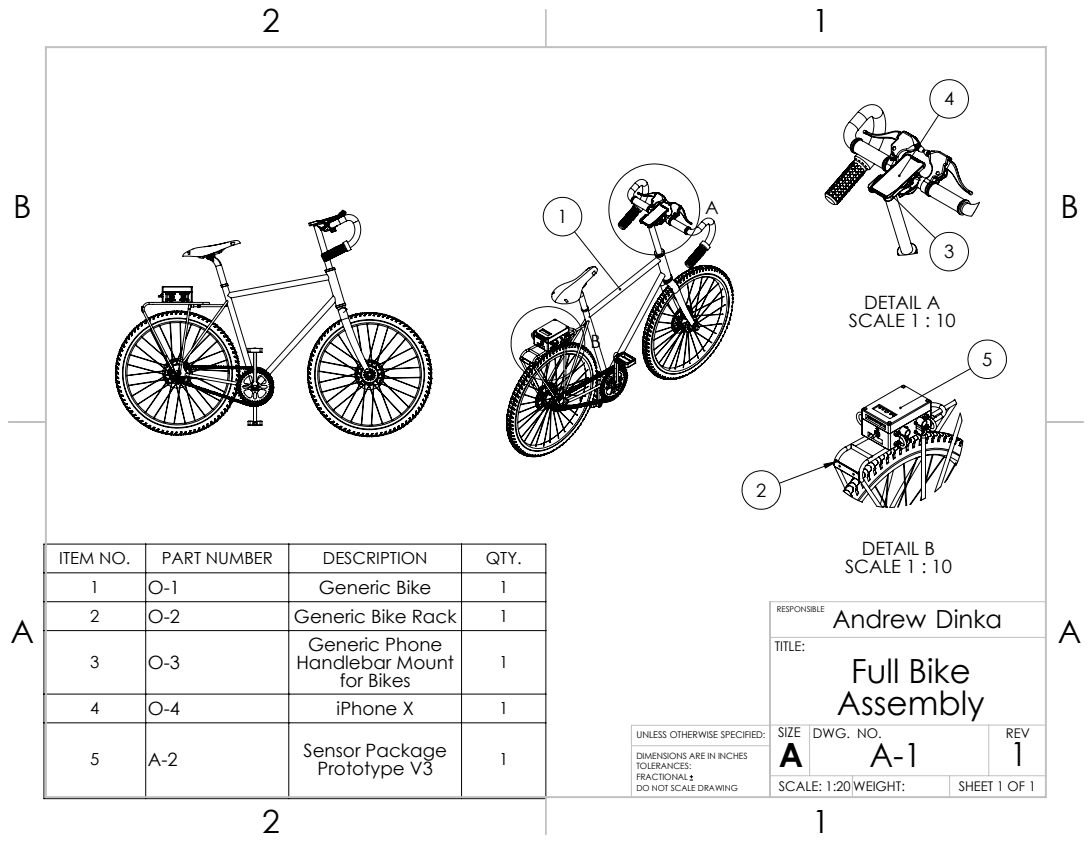
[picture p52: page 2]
DETAIL A SCALE 1 : 10; DETAIL B SCALE 1 : 10; Generic Bike Rack; Sensor Package; Prototype V3; Full Bike Assembly; Andrew Dinka; SHEET 1 OF 1; SCALE: 1:20 WEIGHT:; DWG. NO.; REV; SIZE; TITLE:; RESPONSIBLE

ITEM NO. | PART NUMBER | DESCRIPTION | QTY.
1 | O-1 | Generic Bike | 1

3 | O-3 | Generic Phone Handlebar Mount for Bikes | 1

4 | O-4 | iPhone X | 1

UNLESS OTHERWISE SPECIFIED:
DIMENSIONS ARE IN INCHES
TOLERANCES:
FRACTIONAL
DO NOT SCALE DRAWING

B | B

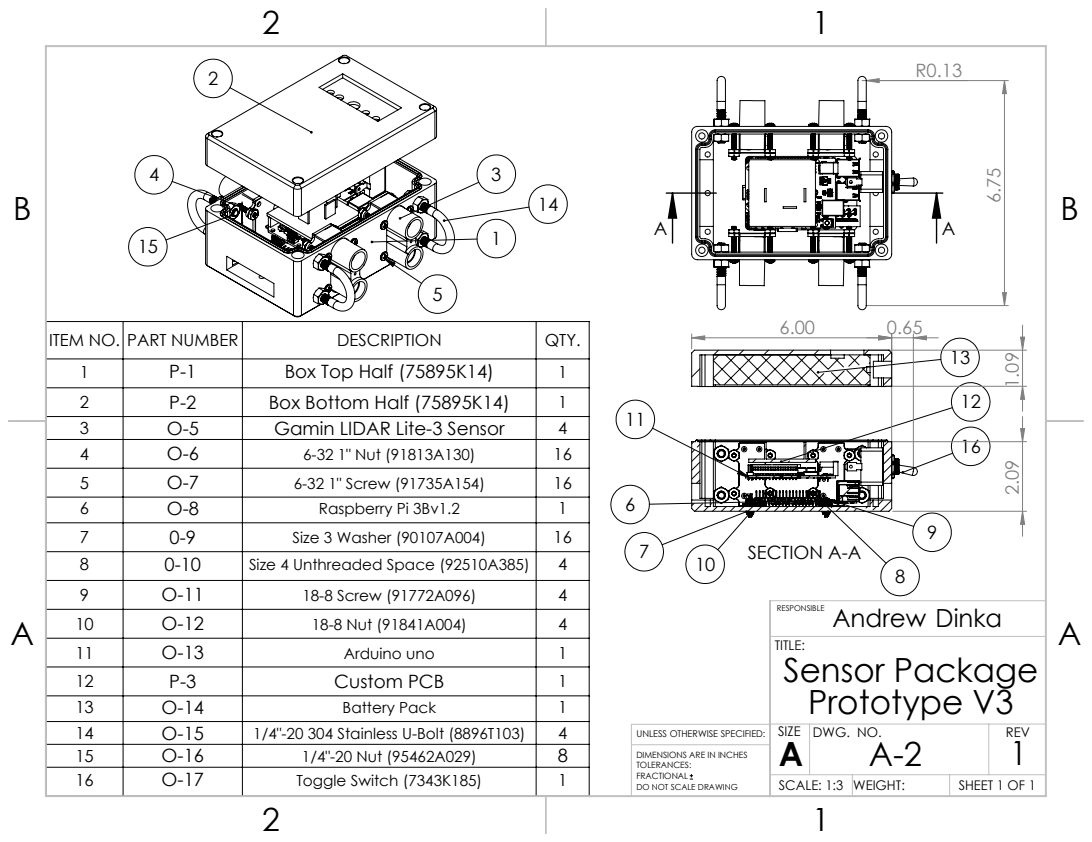
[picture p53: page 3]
SECTION A-A; Arduino uno; 1/4"-20 304 Stainless U-Bolt (8896T103); 1/4"-20 Nut (95462A029); Sensor Package Prototype V3 1; Andrew Dinka; DWG. NO.; REV; SIZE; TITLE:; RESPONSIBLE

ITEM NO. | PART NUMBER | DESCRIPTION | QTY.
1 | P-1 | Box Top Half (75895K14) | 1
2 | P-2 | Box Bottom Half (75895K14) | 1
3 | O-5 | Gamin LIDAR Lite-3 Sensor | 4
4 | O-6 | 6-32 1" Nut (91813A130) | 16
5 | O-7 | 6-32 1" Screw (91735A154) | 16
6 | O-8 | Raspberry Pi 3Bv1.2 | 1
7 | 0-9 | Size 3 Washer (90107A004) | 16
8 | 0-10 | Size 4 Unthreaded Space (92510A385) | 4
9 | O-11 | 18-8 Screw (91772A096) | 4
10 | O-12 | 18-8 Nut (91841A004) | 4

12 | P-3 | Custom PCB | 1
13 | O-14 | Battery Pack | 1

UNLESS OTHERWISE SPECIFIED:
DIMENSIONS ARE IN INCHES
TOLERANCES:

16 | O-17 | Toggle Switch (7343K185) | 1

SCALE: 1:3 | WEIGHT:

0.834 0.75

B | B

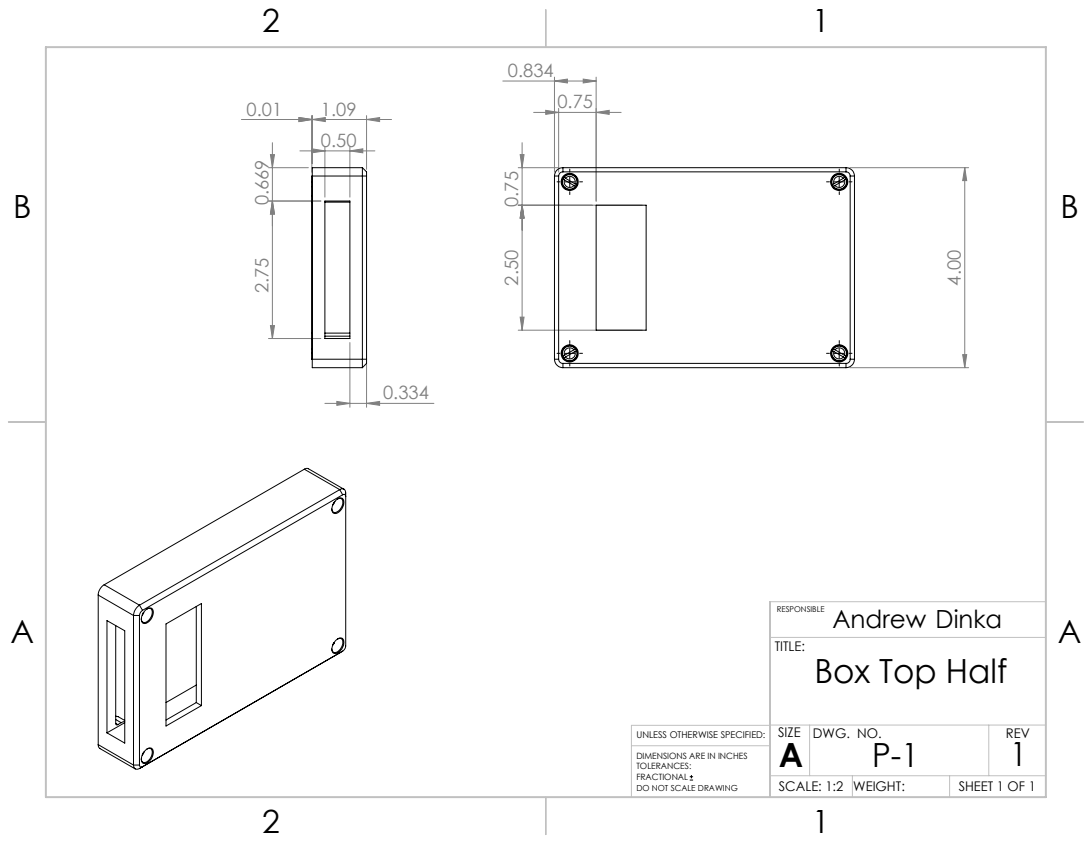
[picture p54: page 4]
Box Top Half; Andrew Dinka; SCALE: 1:2; WEIGHT:; DWG. NO.; REV; SIZE; TITLE:; RESPONSIBLE

UNLESS OTHERWISE SPECIFIED:
DIMENSIONS ARE IN INCHES
TOLERANCES:

B | B

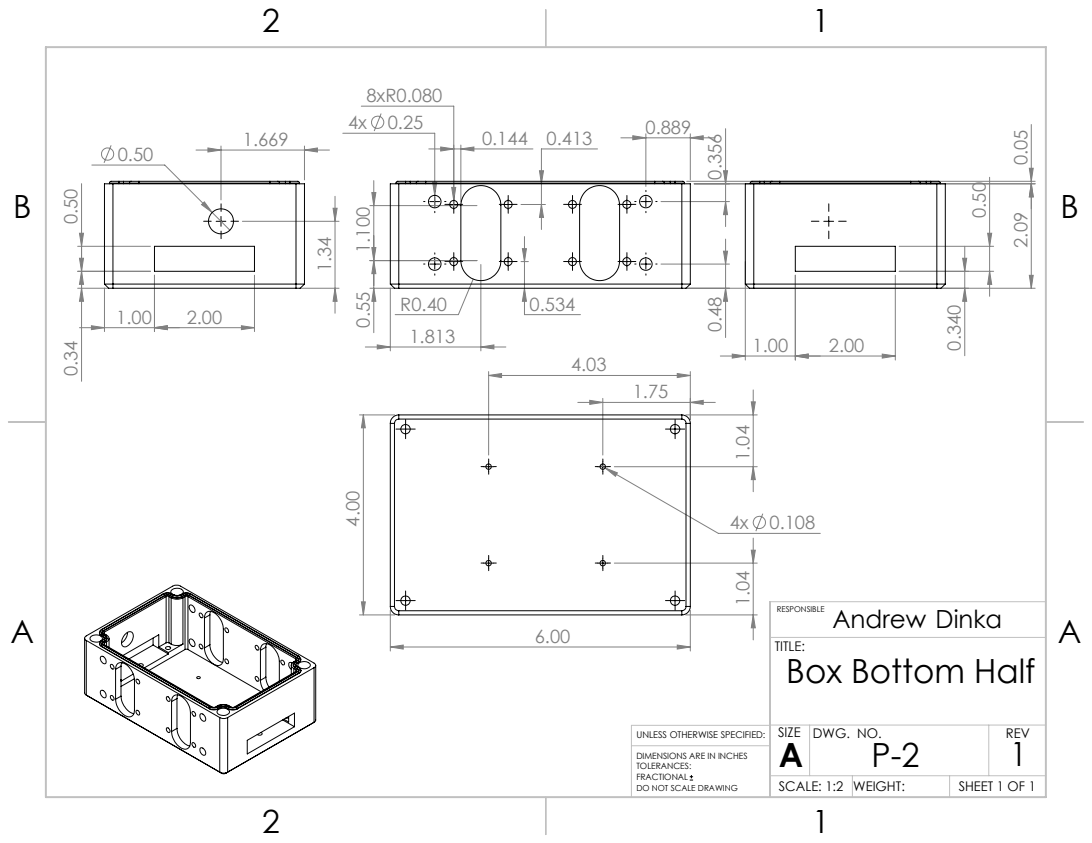
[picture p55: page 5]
Box Bottom Half; Andrew Dinka; SCALE: 1:2; WEIGHT:; DWG. NO.; REV; SIZE; TITLE:; RESPONSIBLE

UNLESS OTHERWISE SPECIFIED:
DIMENSIONS ARE IN INCHES
TOLERANCES:

B | B

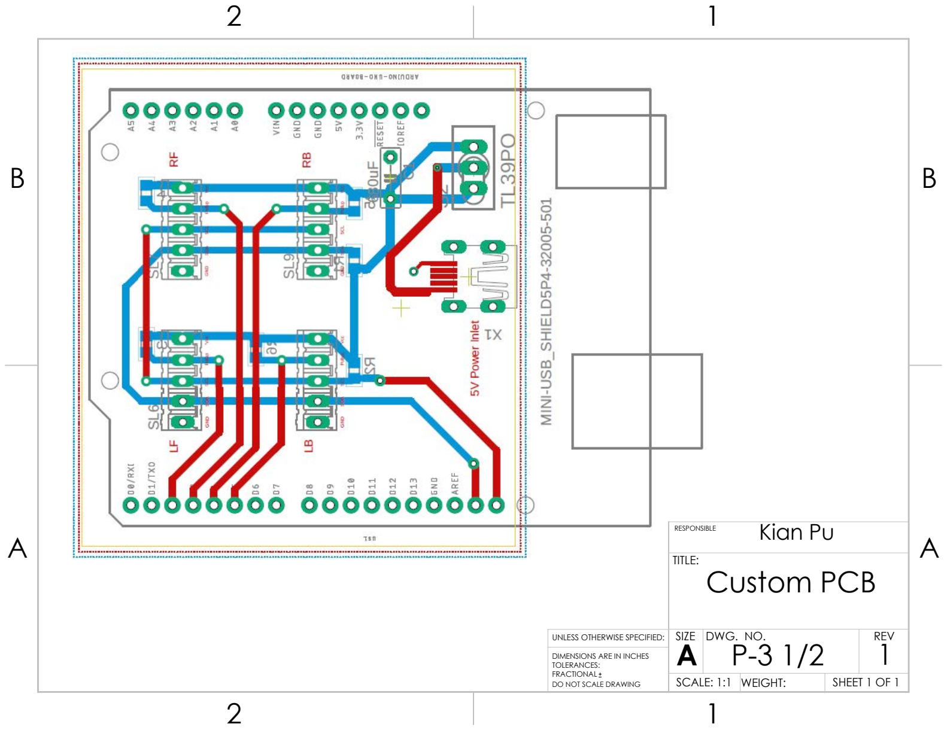
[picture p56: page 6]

A | A

# Custom PCB

1

## Kian Pu

UNLESS OTHERWISE SPECIFIED:

SCALE: 1:1 | WEIGHT:
DWG. NO. | REV
A

SIZE

TITLE:

RESPONSIBLE

DIMENSIONS ARE IN INCHES
TOLERANCES:

P-3 1/2

B | B

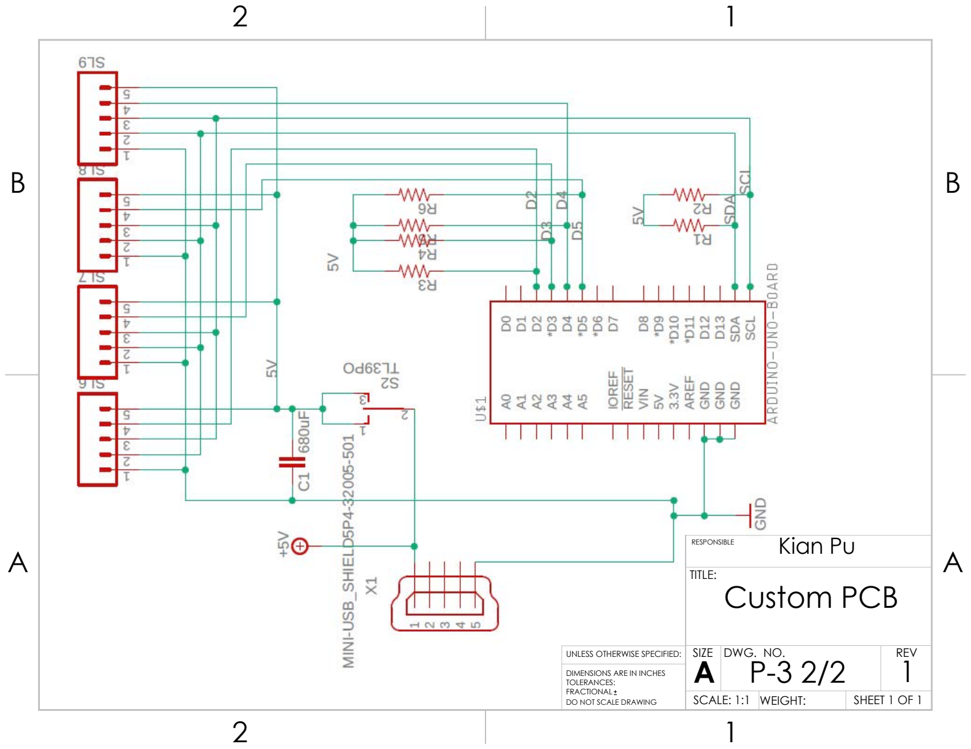
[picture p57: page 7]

A | A

# Custom PCB

1

## Kian Pu

UNLESS OTHERWISE SPECIFIED:

SCALE: 1:1 | WEIGHT:
DWG. NO. | REV
A

SIZE

TITLE:

RESPONSIBLE

DIMENSIONS ARE IN INCHES
TOLERANCES:

P-3 2/2

We Just Met Yesterday | Drawing and Fabrication Package
Assembly Instructions | 4.22.20

## We Just Met Yesterday

# Sensor Package Prototype V3

## Assembly Instructions

Assembly Instructions | 4.22.20

Procurement

1) All items can be found in the Parts List at the beginning of the Drawing and Fabrication Package.
2) Links are provided to order them from McMaster or other vendors. Many of these parts are available at Home Depot as well, provided attention is paid to their correct sizes.

PCB

1) Drawing P-3 provides the PCB Board Layout and Schematic Layout. These files are available digitally in the project files.
2) If you do not have prior PCB manufacturing experience, the Electronics Lab, (https://www.me.gatech.edu/facilities/electronic_lab) on the first floor of the MRDC, can use the schematic and board layout files to manufacture it for you. You can speak with their engineers in the lab to validate the board, and you can submit it online via the Electronics Lab Technical Request Form (http://electronicslab.me.gatech.edu/request/request.php) for manufacturing.

Box Bottom Half

1) Drawing P-2 provides the annotated drawing for the Box Bottom Half. This Box is an “Aluminum Corrosion-Resistant Washdown Enclosure” from McMaster that will be custom fit to this prototype.
2) If you do not have machining experience, the Montgomery Machining Mall or Makerspace machining staff can provide machining help to cut the necessary slots into the box.


Fig. 1: Isometric View of Box Bottom Half

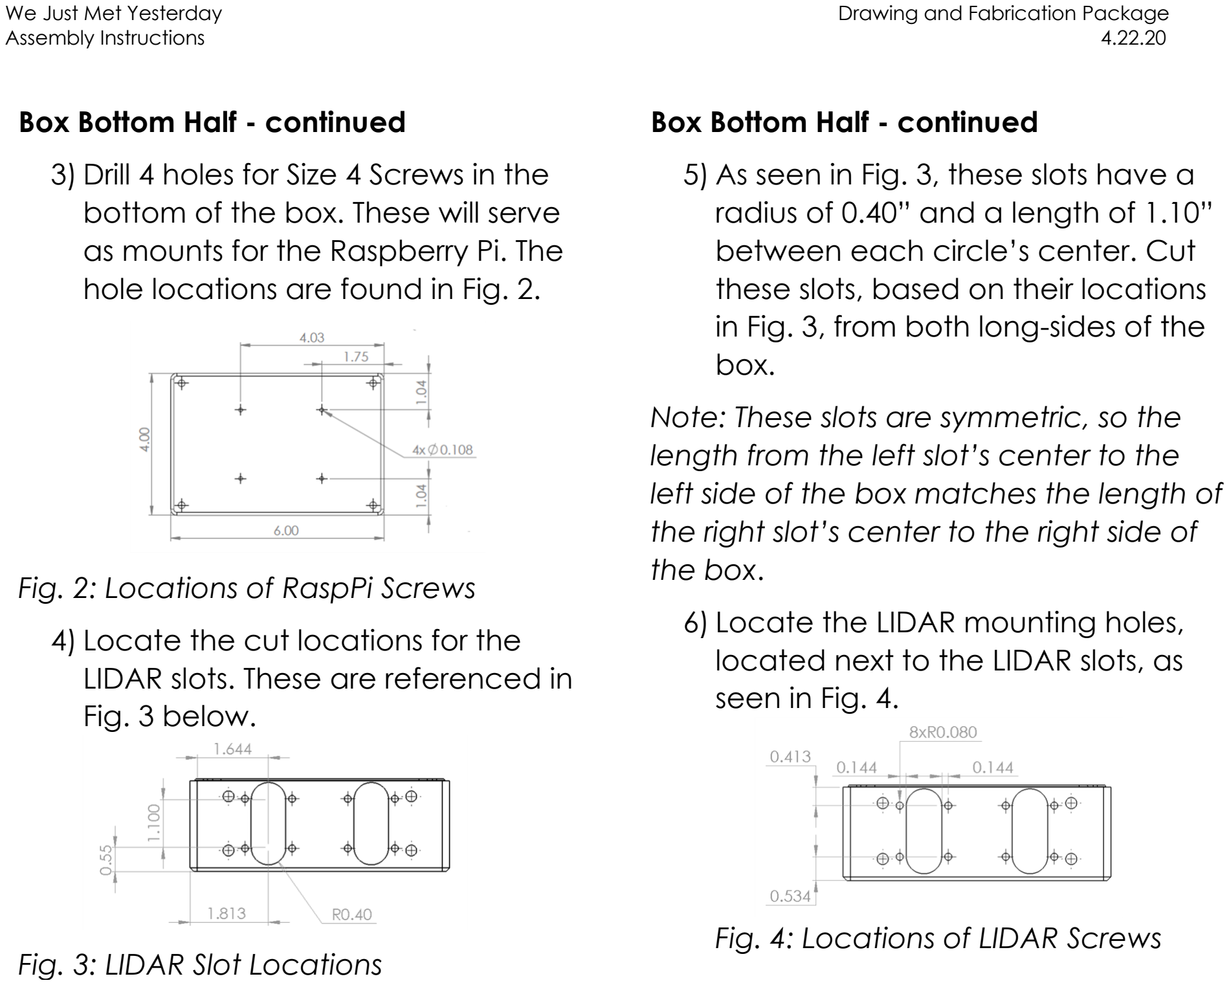
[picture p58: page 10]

Assembly Instructions | 4.22.20

Box Bottom Half - continued

5) As seen in Fig. 3, these slots have a radius of 0.40” and a length of 1.10” between each circle’s center. Cut these slots, based on their locations in Fig. 3, from both long-sides of the box.

Note: These slots are symmetric, so the length from the left slot’s center to the left side of the box matches the length of the right slot’s center to the right side of the box.

6) Locate the LIDAR mounting holes, located next to the LIDAR slots, as seen in Fig. 4.

Fig. 4: Locations of LIDAR Screws

Box Bottom Half - continued

3) Drill 4 holes for Size 4 Screws in the bottom of the box. These will serve as mounts for the Raspberry Pi. The hole locations are found in Fig. 2.

Fig. 2: Locations of RaspPi Screws

4) Locate the cut locations for the LIDAR slots. These are referenced in Fig. 3 below.

Fig. 3: LIDAR Slot Locations

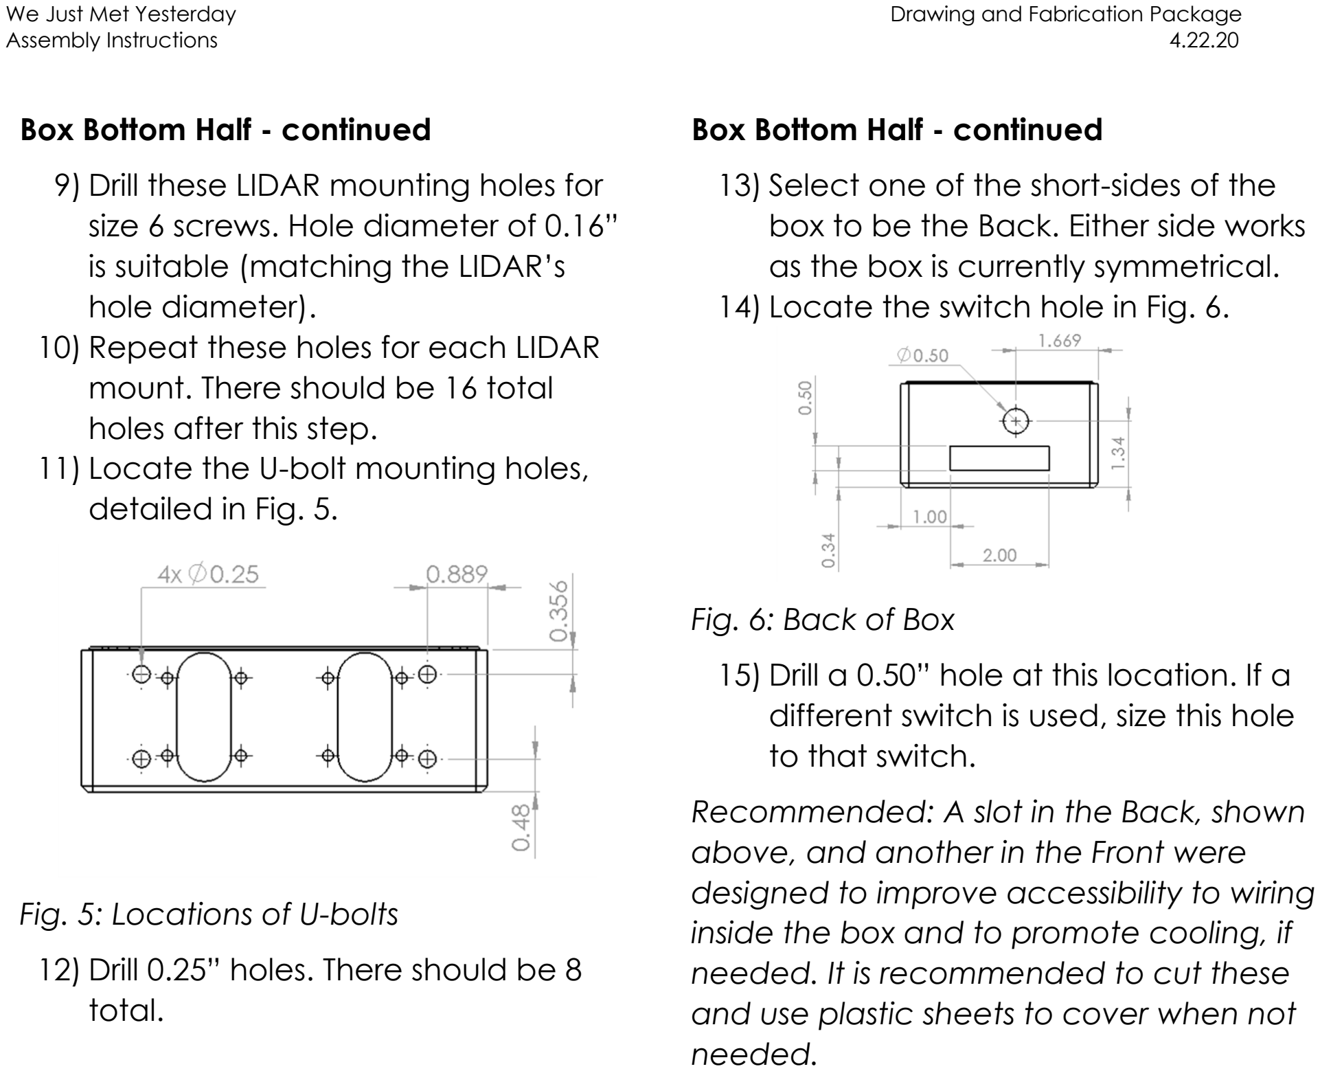
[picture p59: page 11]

Assembly Instructions | 4.22.20

Box Bottom Half - continued

13) Select one of the short-sides of the box to be the Back. Either side works as the box is currently symmetrical.
14) Locate the switch hole in Fig. 6.

Fig. 6: Back of Box

15) Drill a 0.50” hole at this location. If a different switch is used, size this hole to that switch.

Recommended: A slot in the Back, shown above, and another in the Front were designed to improve accessibility to wiring inside the box and to promote cooling, if needed. It is recommended to cut these and use plastic sheets to cover when not needed.

Box Bottom Half - continued

9) Drill these LIDAR mounting holes for size 6 screws. Hole diameter of 0.16” is suitable (matching the LIDAR’s hole diameter).
10) Repeat these holes for each LIDAR mount. There should be 16 total holes after this step.
11) Locate the U-bolt mounting holes, detailed in Fig. 5.

Fig. 5: Locations of U-bolts

12) Drill 0.25” holes. There should be 8 total.

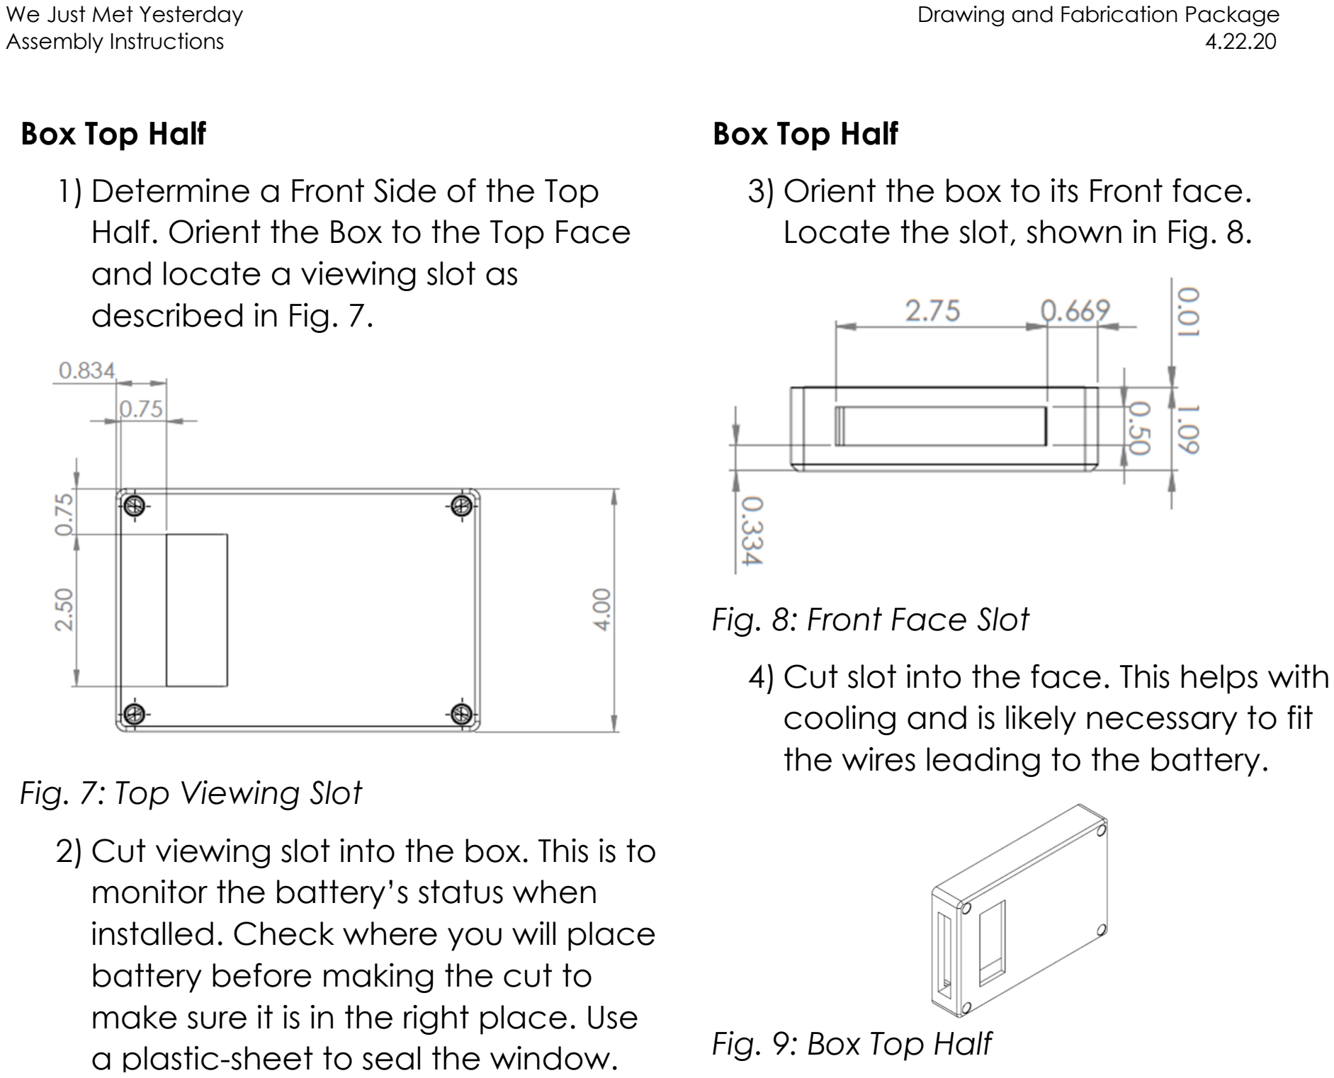
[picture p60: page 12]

Assembly Instructions | 4.22.20

Box Top Half

3) Orient the box to its Front face. Locate the slot, shown in Fig. 8.

Fig. 8: Front Face Slot

4) Cut slot into the face. This helps with cooling and is likely necessary to fit the wires leading to the battery.

Fig. 9: Box Top Half

Box Top Half

1) Determine a Front Side of the Top Half. Orient the Box to the Top Face and locate a viewing slot as described in Fig. 7.

Fig. 7: Top Viewing Slot

2) Cut viewing slot into the box. This is to monitor the battery’s status when installed. Check where you will place battery before making the cut to make sure it is in the right place. Use a plastic-sheet to seal the window.

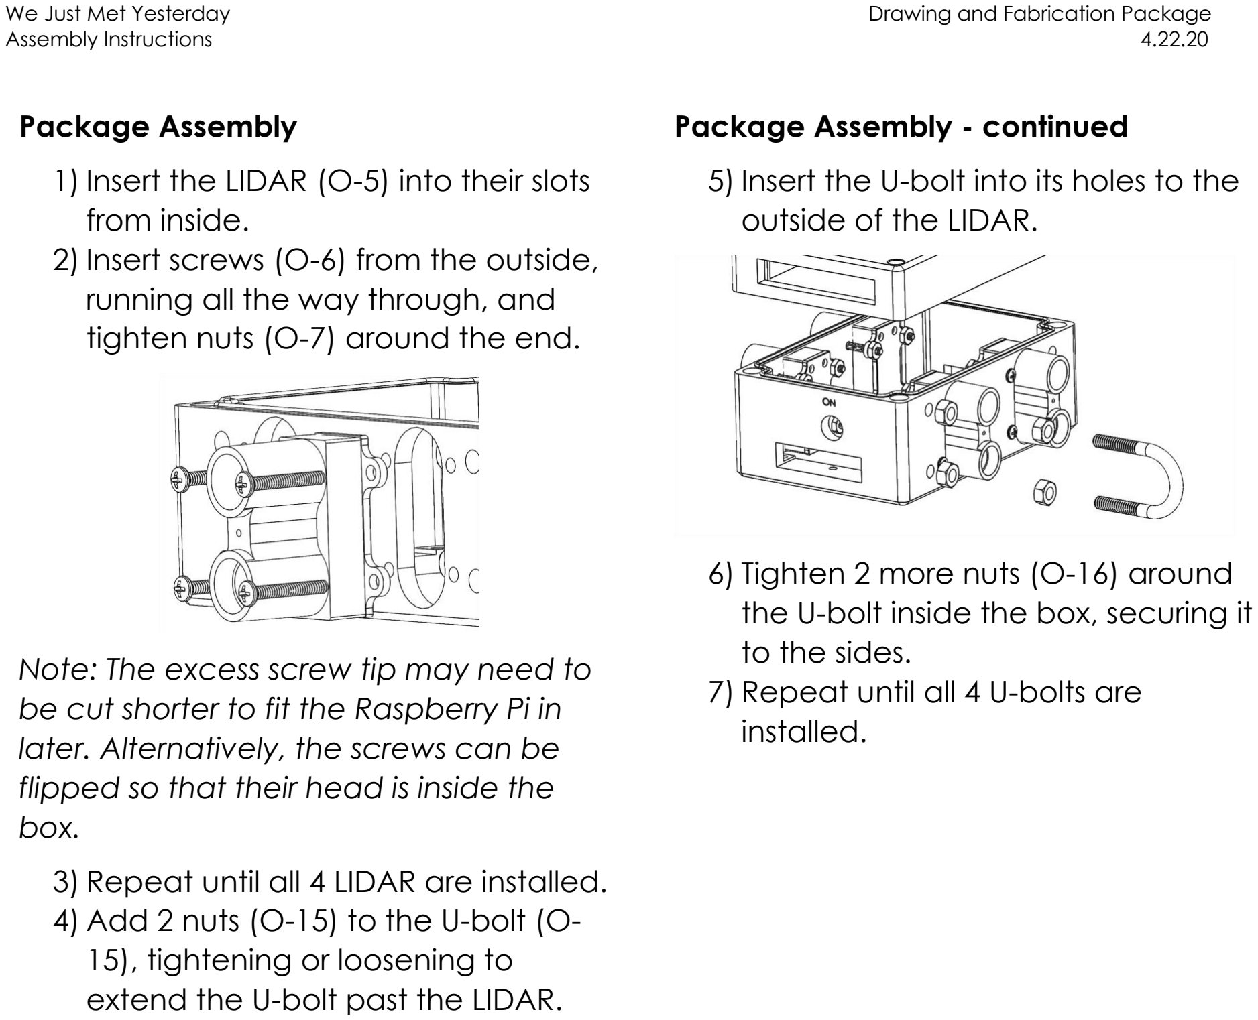
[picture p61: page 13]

Assembly Instructions | 4.22.20

Package Assembly - continued

5) Insert the U-bolt into its holes to the outside of the LIDAR.
6) Tighten 2 more nuts (O-16) around the U-bolt inside the box, securing it to the sides.
7) Repeat until all 4 U-bolts are installed.

Package Assembly

1) Insert the LIDAR (O-5) into their slots from inside.
2) Insert screws (O-6) from the outside, running all the way through, and tighten nuts (O-7) around the end.

Note: The excess screw tip may need to be cut shorter to fit the Raspberry Pi in later. Alternatively, the screws can be flipped so that their head is inside the box.

3) Repeat until all 4 LIDAR are installed.
4) Add 2 nuts (O-15) to the U-bolt (O-15), tightening or loosening to extend the U-bolt past the LIDAR.

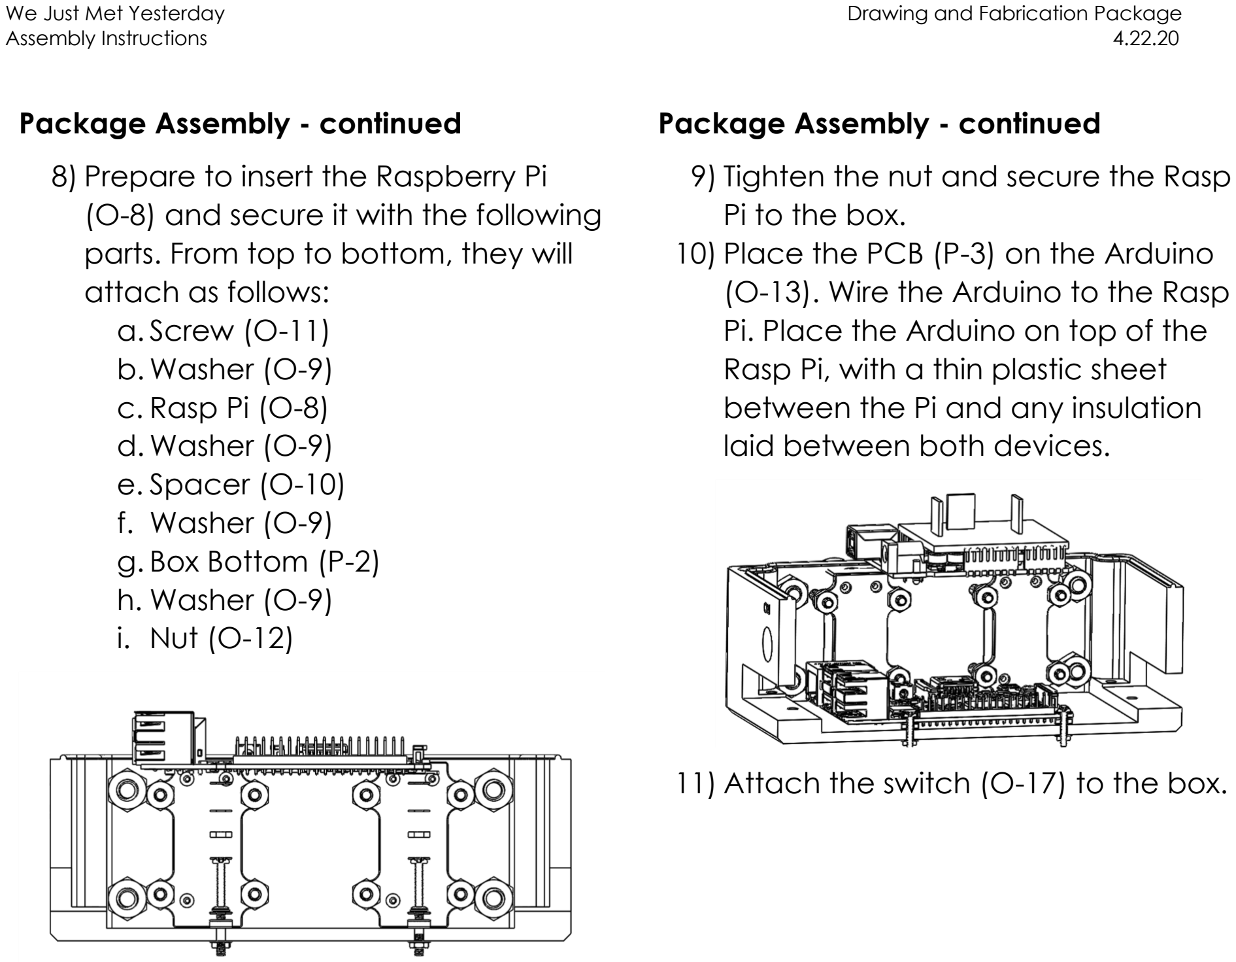
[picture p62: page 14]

Assembly Instructions | 4.22.20

Package Assembly - continued

9) Tighten the nut and secure the Rasp Pi to the box.
10) Place the PCB (P-3) on the Arduino (O-13). Wire the Arduino to the Rasp Pi. Place the Arduino on top of the Rasp Pi, with a thin plastic sheet between the Pi and any insulation laid between both devices.
11) Attach the switch (O-17) to the box.

Package Assembly - continued

8) Prepare to insert the Raspberry Pi (O-8) and secure it with the following parts. From top to bottom, they will attach as follows:
a. Screw (O-11)
b. Washer (O-9)
c. Rasp Pi (O-8)
d. Washer (O-9)
e. Spacer (O-10)
f. Washer (O-9)
g. Box Bottom (P-2)
h. Washer (O-9)
i. Nut (O-12)

Assembly Instructions | 4.22.20

Package Assembly - continued

11) Attach the switch (O-17) to the box.

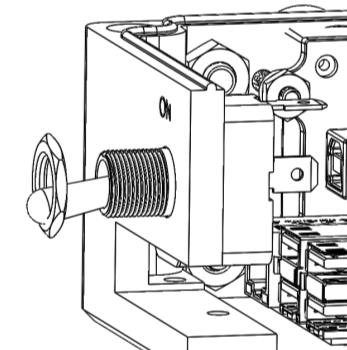
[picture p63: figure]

12) Wire the switch to the PCB.
13) Wire the LIDAR to the PCB.
14) Secure the battery (O-14) with adhesive to the Box Top Half (P-1).

Note: More permanent means can be used on the battery if desired. However, given that it was never tested with the package or orientation, more temporary tape was preferred for now.

15) Wire Battery to the PCB and devices.

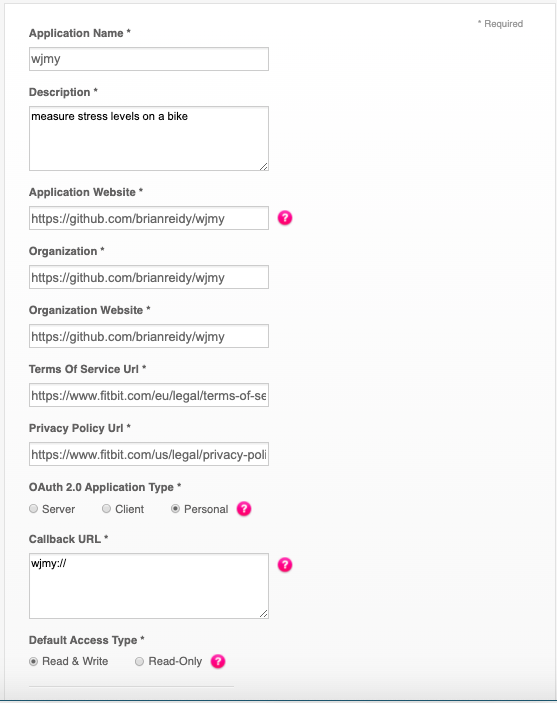
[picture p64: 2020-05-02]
SLAB-wjmy/wjmy-app/README-Images/FitbitSetup.png

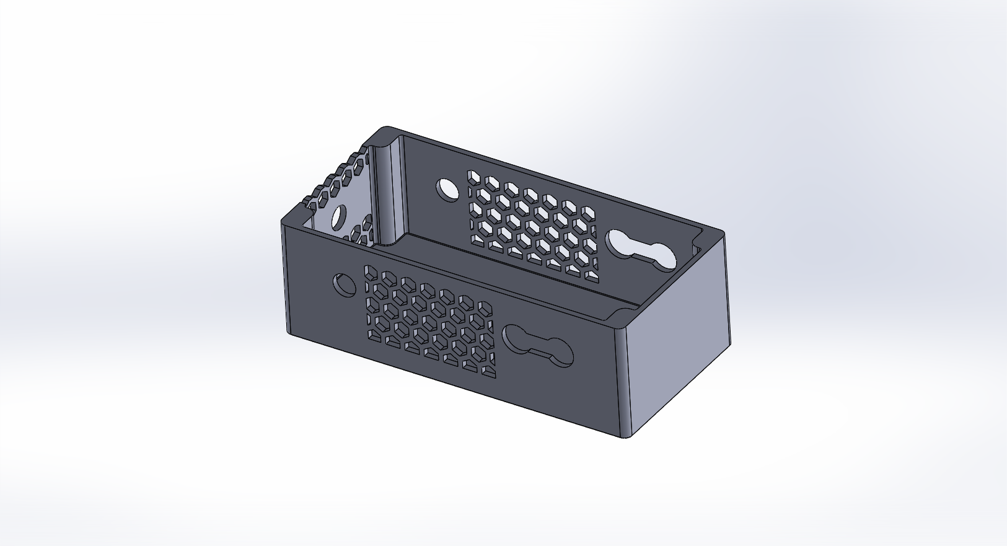
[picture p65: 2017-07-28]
DSSG2017_Case_Design/Back box/print ABS box/misc/Box.PNG

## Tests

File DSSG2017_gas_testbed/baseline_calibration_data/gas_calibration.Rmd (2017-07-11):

---
title: "Gas Sensor Calibration"
author: "Myeong Lee"
date: "7/5/2017"
output: html_document
---

This code is to determine the gas sensor baselines based on the values collected from the calibration using the Wine Preserver gas. 

```{r}
library(readr)
library(dplyr)
library(ggplot2)

setwd("/Users/myeong/git/Atl_DSSG/Cycle-Atlanta-SLaB/Summer2017_SensingBox_Arduino/gas_calibration/")

data <- read_delim("preserver_gas_2_boards.csv", delim = ",", col_names = FALSE)
data$time <- c(1:nrow(data))
colnames(data) <- c("gas", "val", "gas", "val", "gas", "val", "gas", "val", "gas2", "val2", "gas2", "val2", "gas2", "val2", "gas2", "val2","time")

# Board 1
serial <- rbind(data[,c(1,2,17)], data[,c(3,4,17)], data[,c(5,6,17)], data[,c(7,8,17)])
serial$gas <- as.factor(serial$gas)

ggplot(serial, aes(x = time, y = val, colour=gas)) +
  geom_line(size=0.5) +
  theme_bw() + theme(legend.text=element_text(size=15)) + ylab(label="Raw Values") + 
  xlab("Time (sec)") + ylim(700,1000) + ggtitle("Gas Sensor Values over Time (Board 1)")

base_CO_board1 <- mean(serial[serial$time >= 400 & serial$gas == "CO",]$val)
base_SO_board1 <- mean(serial[serial$time >= 400 & serial$gas == "SO",]$val)
base_O3_board1 <- mean(serial[serial$time >= 400 & serial$gas == "O3",]$val)
base_NO_board1 <- mean(serial[serial$time >= 400 & serial$gas == "NO",]$val)

# Board 2
serial2 <- rbind(data[,c(9,10,17)], data[,c(11,12,17)], data[,c(13,14,17)], data[,c(15,16,17)])
serial2$gas2 <- as.factor(serial2$gas2)
colnames(serial2) <- c("gas", "value","time")

ggplot(serial2, aes(x = time, y = value, colour=gas)) +
  geom_line(size=0.5) +
  theme_bw() + theme(legend.text=element_text(size=15)) + ylab(label="Raw Values") + 
  xlab("Time (sec)") + ylim(700,1000) +  ggtitle("Gas Sensor Values over Time (Board 2)")

base_CO_board2 <- mean(serial2[serial2$time >= 400 & serial2$gas == "CO2",]$value)
base_NO_board2 <- mean(serial2[serial2$time >= 400 & serial2$gas == "NO2",]$value)

```

# Calculating the baseline values
```{r}

#taking the second half of the values
data <- data[(nrow(data)/2):nrow(data),]
serial2 <- rbind(data[,c(1,2,9)], data[,c(3,4,9)], data[,c(5,6,9)], data[,7:9])
serial2$gas <- as.factor(serial2$gas)

CO_base <- mean(serial2[serial2$gas=="CO",]$val)
SO2_base <- mean(serial2[serial2$gas=="SO",]$val)
O3_base <- mean(serial2[serial2$gas=="O3",]$val)
NO2_base <- mean(serial2[serial2$gas=="NO",]$val)

```

# Board 4,5,7
```{r}

setwd("/Users/myeong/git/Atl_DSSG/Cycle-Atlanta-SLaB/Summer2017_SensingBox_Arduino/gas_calibration/")

data <- read_delim("board_457.csv", delim = ",", col_names = FALSE)
data$time <- c(1:nrow(data))
colnames(data) <- c("gas", "val", "gas", "val", "gas", "val", "gas", "val", "gas2", "val2", "gas2", "val2", "gas2", "val2", "gas2", "val2", "gas3", "val3", "gas3", "val3", "gas3", "val3", "gas3", "val3", "time")

# Board 1
serial <- rbind(data[,c(1,2,25)], data[,c(3,4,25)], data[,c(5,6,25)], data[,c(7,8,25)])
serial$gas <- as.factor(serial$gas)

ggplot(serial, aes(x = time, y = val, colour=gas)) +
  geom_line(size=0.5) +
  theme_bw() + theme(legend.text=element_text(size=15)) + ylab(label="Raw Values") + 
  xlab("Time (sec)") + ylim(700,1000) + ggtitle("Gas Sensor Values over Time (Board 5)")

base_CO_board1 <- mean(serial[serial$time >= 600 & serial$gas == "CO_1",]$val)
base_SO_board1 <- mean(serial[serial$time >= 600 & serial$gas == "SO_1",]$val)
base_O3_board1 <- mean(serial[serial$time >= 600 & serial$gas == "O3_1",]$val)
base_NO_board1 <- mean(serial[serial$time >= 600 & serial$gas == "NO_1",]$val)

# Board 2
serial2 <- rbind(data[,c(9,10,25)], data[,c(11,12,25)], data[,c(13,14,25)], data[,c(15,16,25)])
serial2$gas2 <- as.factor(serial2$gas2)
colnames(serial2) <- c("gas", "val","time")

ggplot(serial2, aes(x = time, y = val, colour=gas)) +
  geom_line(size=0.5) +
  theme_bw() + theme(legend.text=element_text(size=15)) + ylab(label="Raw Values") + 
  xlab("Time (sec)") + ylim(700,1000) +  ggtitle("Gas Sensor Values over Time (Board 7)")

base_CO_board2 <- mean(serial2[serial2$time >= 600 & serial2$gas == "CO_2",]$val)
base_SO_board2 <- mean(serial2[serial2$time >= 600 & serial2$gas == "SO_2",]$val)
base_O3_board2 <- mean(serial2[serial2$time >= 600 & serial2$gas == "O3_2",]$val)
base_NO_board2 <- mean(serial2[serial2$time >= 600 & serial2$gas == "NO_2",]$val)

# Board 3
serial3 <- rbind(data[,c(17,18,25)], data[,c(19,20,25)], data[,c(21,22,25)], data[,c(23,24,25)])
serial3$gas3 <- as.factor(serial3$gas3)
colnames(serial3) <- c("gas", "val","time")

ggplot(serial3, aes(x = time, y = val, colour=gas)) +
  geom_line(size=0.5) +
  theme_bw() + theme(legend.text=element_text(size=15)) + ylab(label="Raw Values") + 
  xlab("Time (sec)") + ylim(700,1000) +  ggtitle("Gas Sensor Values over Time (Board 4)")

base_CO_board3 <- mean(serial3[serial3$time >= 600 & serial3$gas == "CO_3",]$val)
base_SO_board3 <- mean(serial3[serial3$time >= 600 & serial3$gas == "SO_3",]$val)
base_O3_board3 <- mean(serial3[serial3$time >= 600 & serial3$gas == "O3_3",]$val)
base_NO_board3 <- mean(serial3[serial3$time >= 600 & serial3$gas == "NO_3",]$val)

```

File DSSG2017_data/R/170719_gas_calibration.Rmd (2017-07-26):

---
title: "Gas Sensor Calibration"
author: "Myeong Lee"
date: "7/19/2017"
output: html_document
---

This script is for calibrating gas sensors based on the official data from Atlanta Weather Station. 

```{r}
library(jsonlite)
library(readr)
library(dplyr)
library(sp)
library(ggplot2)
library(ggmap)
library(dplyr)
library(tidyr)
library(geosphere)
library(stringr)
library(lubridate)

setwd("/Users/myeong/git/Atl_DSSG/Cycle-Atlanta-SLaB/DSSG2017_data/gas_station_data/")

gas <- fromJSON(txt= "original_testbed/05-04-2017_testbed.json" )
gas <- as.data.frame(gas["results"])
colnames(gas) <- c("SO_3", "SO_2","SO_1","NO_1","NO_2","NO_3", "CO_3", "CO_2", "CO_1", "time", "O3_3", "O3_2", "O3_1")
gas["time2"] <- as.POSIXct(gas$time, origin="1970-01-01", format = "%H-%M-%S")
gas$time2 <- gas$time2 - (3600*3)
gas$time2 <- gas$time2 + (600)
gas$time2 <- gas$time2 - (3600*24*9)

for (i in c(1:13)){
  gas[,i] <- as.numeric(gas[,i])  
}

gas2 <- fromJSON(txt= "original_testbed/05-05-2017_testbed.json" )
gas2 <- as.data.frame(gas2["results"])
colnames(gas2) <- c("SO_3", "SO_2","SO_1","NO_1","NO_2","NO_3", "CO_3", "CO_2", "CO_1", "time", "O3_3", "O3_2", "O3_1")
gas2["time2"] <- as.POSIXct(gas2$time, origin="1970-01-01", format = "%H-%M-%S")
gas2$time2 <- gas2$time2 - (3600*3)
gas2$time2 <- gas2$time2 + (600)
gas2$time2 <- gas2$time2 - (3600*24*8)

for (i in c(1:13)){
  gas2[,i] <- as.numeric(gas2[,i])  
}

gas3 <- fromJSON(txt= "original_testbed/05-06-2017_testbed.json" )
gas3 <- as.data.frame(gas3["results"])
colnames(gas3) <- c("SO_3", "SO_2","SO_1","NO_1","NO_2","NO_3", "CO_3", "CO_2", "CO_1", "time", "O3_3", "O3_2", "O3_1")
gas3["time2"] <- as.POSIXct(gas3$time, origin="1970-01-01", format = "%H-%M-%S")
gas3$time2 <- gas3$time2 - (3600*3)
gas3$time2 <- gas3$time2 + (600)
gas3$time2 <- gas3$time2 - (3600*24*7)

for (i in c(1:13)){
  gas3[,i] <- as.numeric(gas3[,i])  
}

gas_all <- rbind(gas, gas2, gas3)

#Sensor #1
gas_agg <- gas_all[,c("time2", "CO_1", "SO_1", "O3_1", "NO_1")]
gas_agg$day <- day(ymd_hms(gas_agg$time2))
gas_agg$hour <- hour(ymd_hms(gas_agg$time2))
gas_agg$minute <- minute(ymd_hms(gas_agg$time2))
gas_agg$second <- second(ymd_hms(gas_agg$time2))
gas_agg <- gas_agg %>% group_by(day, hour, minute) %>% summarise(CO=mean(CO_1), SO=mean(SO_1), O3=mean(O3_1), NO=mean(NO_1))
gas_agg$time <- paste(str_pad(gas_agg$day, width=2, side="left", pad="0"), str_pad(gas_agg$hour, width=2, side="left", pad="0"), str_pad(gas_agg$minute, width=2, side="left", pad="0"), sep="")
gas_agg$time <- as.POSIXct(gas_agg$time, origin="1970-01-01", format = "%d%H%M")

dot_size = 0.5

ggplot(gas_agg, aes(x = time)) +
  geom_line(aes(y = CO), colour="red", size=dot_size) +
  geom_point(aes(y = CO), colour="red", size=dot_size) +
  geom_line(aes(y = NO), colour="blue", size=dot_size) +
  geom_point(aes(y = NO), colour="blue", size=dot_size) +
  geom_line(aes(y = SO), colour="green", size=dot_size) +
  geom_point(aes(y = SO), colour="green", size=dot_size) +
  geom_line(aes(y = O3), colour="violet", size=dot_size) +
  geom_point(aes(y = O3), colour="violet", size=dot_size) +
  theme_bw() + theme(legend.text=element_text(size=15)) + ylim(c(700,1100)) + ylab(label="12-bit Voltage Reading") + 
  xlab("Time")  +ggtitle("Time-Series Gas Sensor Values #1")

#Sensor #7
gas_agg <- gas_all[,c("time2", "CO_2", "SO_2", "O3_2", "NO_2")]
gas_agg$day <- day(ymd_hms(gas_agg$time2))
gas_agg$hour <- hour(ymd_hms(gas_agg$time2))
gas_agg$minute <- minute(ymd_hms(gas_agg$time2))
gas_agg$second <- second(ymd_hms(gas_agg$time2))
gas_agg <- gas_agg %>% group_by(day, hour, minute) %>% summarise(CO=mean(CO_2), SO=mean(SO_2), O3=mean(O3_2), NO=mean(NO_2))
gas_agg$time <- paste(str_pad(gas_agg$day, width=2, side="left", pad="0"), str_pad(gas_agg$hour, width=2, side="left", pad="0"), str_pad(gas_agg$minute, width=2, side="left", pad="0"), sep="")
gas_agg$time <- as.POSIXct(gas_agg$time, origin="1970-01-01", format = "%d%H%M")

ggplot(gas_agg, aes(x = time)) +
  geom_line(aes(y = CO), colour="red", size=dot_size) +
  geom_point(aes(y = CO), colour="red", size=dot_size) +
  geom_line(aes(y = NO), colour="blue", size=dot_size) +
  geom_point(aes(y = NO), colour="blue", size=dot_size) +
  geom_line(aes(y = SO), colour="green", size=dot_size) +
  geom_point(aes(y = SO), colour="green", size=dot_size) +
  geom_line(aes(y = O3), colour="violet", size=dot_size) +
  geom_point(aes(y = O3), colour="violet", size=dot_size) +
  theme_bw() + theme(legend.text=element_text(size=15)) + ylim(c(650,1000)) + ylab(label="12-bit Voltage Reading") + 
  xlab("Time")  +ggtitle("Time-Series Gas Sensor Values #7")

#Sensor #4
gas_agg <- gas_all[,c("time2", "CO_3", "SO_3", "O3_3", "NO_3")]
gas_agg$day <- day(ymd_hms(gas_agg$time2))
gas_agg$hour <- hour(ymd_hms(gas_agg$time2))
gas_agg$minute <- minute(ymd_hms(gas_agg$time2))
gas_agg$second <- second(ymd_hms(gas_agg$time2))
gas_agg <- gas_agg %>% group_by(day, hour, minute) %>% summarise(CO=mean(CO_3), SO=mean(SO_3), O3=mean(O3_3), NO=mean(NO_3))
gas_agg$time <- paste(str_pad(gas_agg$day, width=2, side="left", pad="0"), str_pad(gas_agg$hour, width=2, side="left", pad="0"), str_pad(gas_agg$minute, width=2, side="left", pad="0"), sep="")
gas_agg$time <- as.POSIXct(gas_agg$time, origin="1970-01-01", format = "%d%H%M")

ggplot(gas_agg, aes(x = time)) +
  geom_line(aes(y = CO), colour="red", size=dot_size) +
  geom_point(aes(y = CO), colour="red", size=dot_size) +
  geom_line(aes(y = NO), colour="blue", size=dot_size) +
  geom_point(aes(y = NO), colour="blue", size=dot_size) +
  geom_line(aes(y = SO), colour="green", size=dot_size) +
  geom_point(aes(y = SO), colour="green", size=dot_size) +
  geom_line(aes(y = O3), colour="violet", size=dot_size) +
  geom_point(aes(y = O3), colour="violet", size=dot_size) +
  theme_bw() + theme(legend.text=element_text(size=15)) + ylim(c(650,1000)) + ylab(label="12-bit Voltage Reading") + 
  xlab("Time")  +ggtitle("Time-Series Gas Sensor Values #4")

write.table(gas_all, "gas_testbed_aggregated.csv", row.names=F, col.names=T, sep=",")

```

# Official Values
```{r}
setwd("/Users/myeong/git/Atl_DSSG/Cycle-Atlanta-SLaB/DSSG2017_data/gas_station_data/")
official <- read_delim("official_agg.csv", delim = ",")
official$Time <- as.character(official$Time)
official$time <- paste0(official$Date, "-", official$Time)
official$date <- as.POSIXct(official$time, origin="1970-01-01", format = "%m/%d/%y-%H")
official$time <- official$date

ggplot(official[c(1:58),], aes(x = time)) +
  geom_line(aes(y = CO), colour="red", size=dot_size) +
  geom_point(aes(y = CO), colour="red", size=dot_size) +
  geom_line(aes(y = NO2), colour="blue", size=dot_size) +
  geom_point(aes(y = NO2), colour="blue", size=dot_size) +
  geom_line(aes(y = SO2), colour="green", size=dot_size) +
  geom_point(aes(y = SO2), colour="green", size=dot_size) +
  geom_line(aes(y = O3), colour="violet", size=dot_size) +
  geom_point(aes(y = O3), colour="violet", size=dot_size) +
  theme_bw() + theme(legend.text=element_text(size=15)) + ylab(label="ppb") + 
  xlab("Time")  +ggtitle("Time-Series Official Gas Sensor Values")
```

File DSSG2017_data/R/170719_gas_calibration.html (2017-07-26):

# Gas Sensor Calibration

#### Myeong Lee

#### 7/19/2017

This script is for calibrating gas sensors based on the official data from Atlanta Weather Station.

library(jsonlite)
library(readr)
library(dplyr)

## 
## Attaching package: 'dplyr'

## The following objects are masked from 'package:stats':
## 
##     filter, lag

## The following objects are masked from 'package:base':
## 
##     intersect, setdiff, setequal, union

library(sp)
library(ggplot2)
library(ggmap)

## Google Maps API Terms of Service: http://developers.google.com/maps/terms.

## Please cite ggmap if you use it: see citation("ggmap") for details.

library(dplyr)
library(tidyr)
library(geosphere)
library(stringr)
library(lubridate)

## 
## Attaching package: 'lubridate'

## The following object is masked from 'package:base':
## 
##     date

setwd("/Users/myeong/git/Atl_DSSG/Cycle-Atlanta-SLaB/DSSG2017_data/gas_station_data/")

gas <- fromJSON(txt= "original_testbed/05-04-2017_testbed.json" )
gas <- as.data.frame(gas["results"])
colnames(gas) <- c("SO_3", "SO_2","SO_1","NO_1","NO_2","NO_3", "CO_3", "CO_2", "CO_1", "time", "O3_3", "O3_2", "O3_1")
gas["time2"] <- as.POSIXct(gas$time, origin="1970-01-01", format = "%H-%M-%S")
gas$time2 <- gas$time2 - (3600*3)
gas$time2 <- gas$time2 + (600)
gas$time2 <- gas$time2 - (3600*24*9)

for (i in c(1:13)){
  gas[,i] <- as.numeric(gas[,i])  
}

## Warning: NAs introduced by coercion

gas2 <- fromJSON(txt= "original_testbed/05-05-2017_testbed.json" )
gas2 <- as.data.frame(gas2["results"])
colnames(gas2) <- c("SO_3", "SO_2","SO_1","NO_1","NO_2","NO_3", "CO_3", "CO_2", "CO_1", "time", "O3_3", "O3_2", "O3_1")
gas2["time2"] <- as.POSIXct(gas2$time, origin="1970-01-01", format = "%H-%M-%S")
gas2$time2 <- gas2$time2 - (3600*3)
gas2$time2 <- gas2$time2 + (600)
gas2$time2 <- gas2$time2 - (3600*24*8)

for (i in c(1:13)){
  gas2[,i] <- as.numeric(gas2[,i])  
}

## Warning: NAs introduced by coercion

gas3 <- fromJSON(txt= "original_testbed/05-06-2017_testbed.json" )
gas3 <- as.data.frame(gas3["results"])
colnames(gas3) <- c("SO_3", "SO_2","SO_1","NO_1","NO_2","NO_3", "CO_3", "CO_2", "CO_1", "time", "O3_3", "O3_2", "O3_1")
gas3["time2"] <- as.POSIXct(gas3$time, origin="1970-01-01", format = "%H-%M-%S")
gas3$time2 <- gas3$time2 - (3600*3)
gas3$time2 <- gas3$time2 + (600)
gas3$time2 <- gas3$time2 - (3600*24*7)

for (i in c(1:13)){
  gas3[,i] <- as.numeric(gas3[,i])  
}

## Warning: NAs introduced by coercion

gas_all <- rbind(gas, gas2, gas3)

#Sensor #1
gas_agg <- gas_all[,c("time2", "CO_1", "SO_1", "O3_1", "NO_1")]
gas_agg$day <- day(ymd_hms(gas_agg$time2))
gas_agg$hour <- hour(ymd_hms(gas_agg$time2))
gas_agg$minute <- minute(ymd_hms(gas_agg$time2))
gas_agg$second <- second(ymd_hms(gas_agg$time2))
gas_agg <- gas_agg %>% group_by(day, hour, minute) %>% summarise(CO=mean(CO_1), SO=mean(SO_1), O3=mean(O3_1), NO=mean(NO_1))
gas_agg$time <- paste(str_pad(gas_agg$day, width=2, side="left", pad="0"), str_pad(gas_agg$hour, width=2, side="left", pad="0"), str_pad(gas_agg$minute, width=2, side="left", pad="0"), sep="")
gas_agg$time <- as.POSIXct(gas_agg$time, origin="1970-01-01", format = "%d%H%M")

dot_size = 0.5

ggplot(gas_agg, aes(x = time)) +
  geom_line(aes(y = CO), colour="red", size=dot_size) +
  geom_point(aes(y = CO), colour="red", size=dot_size) +
  geom_line(aes(y = NO), colour="blue", size=dot_size) +
  geom_point(aes(y = NO), colour="blue", size=dot_size) +
  geom_line(aes(y = SO), colour="green", size=dot_size) +
  geom_point(aes(y = SO), colour="green", size=dot_size) +
  geom_line(aes(y = O3), colour="violet", size=dot_size) +
  geom_point(aes(y = O3), colour="violet", size=dot_size) +
  theme_bw() + theme(legend.text=element_text(size=15)) + ylim(c(700,1100)) + ylab(label="12-bit Voltage Reading") + 
  xlab("Time")  +ggtitle("Time-Series Gas Sensor Values #1")

## Warning: Removed 26 rows containing missing values (geom_point).

#Sensor #7
gas_agg <- gas_all[,c("time2", "CO_2", "SO_2", "O3_2", "NO_2")]
gas_agg$day <- day(ymd_hms(gas_agg$time2))
gas_agg$hour <- hour(ymd_hms(gas_agg$time2))
gas_agg$minute <- minute(ymd_hms(gas_agg$time2))
gas_agg$second <- second(ymd_hms(gas_agg$time2))
gas_agg <- gas_agg %>% group_by(day, hour, minute) %>% summarise(CO=mean(CO_2), SO=mean(SO_2), O3=mean(O3_2), NO=mean(NO_2))
gas_agg$time <- paste(str_pad(gas_agg$day, width=2, side="left", pad="0"), str_pad(gas_agg$hour, width=2, side="left", pad="0"), str_pad(gas_agg$minute, width=2, side="left", pad="0"), sep="")
gas_agg$time <- as.POSIXct(gas_agg$time, origin="1970-01-01", format = "%d%H%M")

ggplot(gas_agg, aes(x = time)) +
  geom_line(aes(y = CO), colour="red", size=dot_size) +
  geom_point(aes(y = CO), colour="red", size=dot_size) +
  geom_line(aes(y = NO), colour="blue", size=dot_size) +
  geom_point(aes(y = NO), colour="blue", size=dot_size) +
  geom_line(aes(y = SO), colour="green", size=dot_size) +
  geom_point(aes(y = SO), colour="green", size=dot_size) +
  geom_line(aes(y = O3), colour="violet", size=dot_size) +
  geom_point(aes(y = O3), colour="violet", size=dot_size) +
  theme_bw() + theme(legend.text=element_text(size=15)) + ylim(c(650,1000)) + ylab(label="12-bit Voltage Reading") + 
  xlab("Time")  +ggtitle("Time-Series Gas Sensor Values #7")

## Warning: Removed 6 rows containing missing values (geom_point).

#Sensor #4
gas_agg <- gas_all[,c("time2", "CO_3", "SO_3", "O3_3", "NO_3")]
gas_agg$day <- day(ymd_hms(gas_agg$time2))
gas_agg$hour <- hour(ymd_hms(gas_agg$time2))
gas_agg$minute <- minute(ymd_hms(gas_agg$time2))
gas_agg$second <- second(ymd_hms(gas_agg$time2))
gas_agg <- gas_agg %>% group_by(day, hour, minute) %>% summarise(CO=mean(CO_3), SO=mean(SO_3), O3=mean(O3_3), NO=mean(NO_3))
gas_agg$time <- paste(str_pad(gas_agg$day, width=2, side="left", pad="0"), str_pad(gas_agg$hour, width=2, side="left", pad="0"), str_pad(gas_agg$minute, width=2, side="left", pad="0"), sep="")
gas_agg$time <- as.POSIXct(gas_agg$time, origin="1970-01-01", format = "%d%H%M")

ggplot(gas_agg, aes(x = time)) +
  geom_line(aes(y = CO), colour="red", size=dot_size) +
  geom_point(aes(y = CO), colour="red", size=dot_size) +
  geom_line(aes(y = NO), colour="blue", size=dot_size) +
  geom_point(aes(y = NO), colour="blue", size=dot_size) +
  geom_line(aes(y = SO), colour="green", size=dot_size) +
  geom_point(aes(y = SO), colour="green", size=dot_size) +
  geom_line(aes(y = O3), colour="violet", size=dot_size) +
  geom_point(aes(y = O3), colour="violet", size=dot_size) +
  theme_bw() + theme(legend.text=element_text(size=15)) + ylim(c(650,1000)) + ylab(label="12-bit Voltage Reading") + 
  xlab("Time")  +ggtitle("Time-Series Gas Sensor Values #4")

## Warning: Removed 9 rows containing missing values (geom_point).

## Warning: Removed 1 rows containing missing values (geom_path).

## Warning: Removed 1 rows containing missing values (geom_point).

write.table(gas_all, "gas_testbed_aggregated.csv", row.names=F, col.names=T, sep=",")

# Official Values

setwd("/Users/myeong/git/Atl_DSSG/Cycle-Atlanta-SLaB/DSSG2017_data/gas_station_data/")
official <- read_delim("official_agg.csv", delim = ",")

## Parsed with column specification:
## cols(
##   Date = col_character(),
##   Time = col_integer(),
##   SO2 = col_double(),
##   CO = col_double(),
##   Temp = col_double(),
##   RH = col_double(),
##   O3 = col_double(),
##   NO = col_double(),
##   NO2 = col_double(),
##   PM25 = col_double()
## )

official$Time <- as.character(official$Time)
official$time <- paste0(official$Date, "-", official$Time)
official$date <- as.POSIXct(official$time, origin="1970-01-01", format = "%m/%d/%y-%H")
official$time <- official$date

ggplot(official[c(1:58),], aes(x = time)) +
  geom_line(aes(y = CO), colour="red", size=dot_size) +
  geom_point(aes(y = CO), colour="red", size=dot_size) +
  geom_line(aes(y = NO2), colour="blue", size=dot_size) +
  geom_point(aes(y = NO2), colour="blue", size=dot_size) +
  geom_line(aes(y = SO2), colour="green", size=dot_size) +
  geom_point(aes(y = SO2), colour="green", size=dot_size) +
  geom_line(aes(y = O3), colour="violet", size=dot_size) +
  geom_point(aes(y = O3), colour="violet", size=dot_size) +
  theme_bw() + theme(legend.text=element_text(size=15)) + ylab(label="ppb") + 
  xlab("Time")  +ggtitle("Time-Series Official Gas Sensor Values")

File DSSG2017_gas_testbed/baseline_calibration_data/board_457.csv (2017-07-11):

CO_1 | 888 | SO_1 | 1634 | O3_1 | 625 | NO_1 | 767 | CO_2 | 919 | SO_2 | 1692 | O3_2 | 797 | NO_2 | 867 | CO_3 | 839 | SO_3 | 1692 | O3_3 | 891 | NO_3 | 884
CO_1 | 847 | SO_1 | 1634 | O3_1 | 807 | NO_1 | 908 | CO_2 | 905 | SO_2 | 1692 | O3_2 | 843 | NO_2 | 849 | CO_3 | 840 | SO_3 | 1692 | O3_3 | 812 | NO_3 | 792
CO_1 | 868 | SO_1 | 1634 | O3_1 | 807 | NO_1 | 706 | CO_2 | 898 | SO_2 | 1692 | O3_2 | 811 | NO_2 | 829 | CO_3 | 842 | SO_3 | 1692 | O3_3 | 792 | NO_3 | 777
CO_1 | 868 | SO_1 | 1634 | O3_1 | 807 | NO_1 | 888 | CO_2 | 891 | SO_2 | 1692 | O3_2 | 802 | NO_2 | 825 | CO_3 | 841 | SO_3 | 1692 | O3_3 | 786 | NO_3 | 779
CO_1 | 868 | SO_1 | 1634 | O3_1 | 787 | NO_1 | 1009 | CO_2 | 888 | SO_2 | 1692 | O3_2 | 799 | NO_2 | 825 | CO_3 | 842 | SO_3 | 1692 | O3_3 | 787 | NO_3 | 783
CO_1 | 847 | SO_1 | 1634 | O3_1 | 767 | NO_1 | 807 | CO_2 | 884 | SO_2 | 1692 | O3_2 | 796 | NO_2 | 824 | CO_3 | 841 | SO_3 | 1692 | O3_3 | 789 | NO_3 | 786
CO_1 | 868 | SO_1 | 1634 | O3_1 | 787 | NO_1 | 807 | CO_2 | 881 | SO_2 | 1692 | O3_2 | 796 | NO_2 | 824 | CO_3 | 843 | SO_3 | 1692 | O3_3 | 785 | NO_3 | 786
CO_1 | 868 | SO_1 | 1634 | O3_1 | 767 | NO_1 | 908 | CO_2 | 878 | SO_2 | 1692 | O3_2 | 795 | NO_2 | 824 | CO_3 | 841 | SO_3 | 1692 | O3_3 | 790 | NO_3 | 790
CO_1 | 847 | SO_1 | 1634 | O3_1 | 807 | NO_1 | 807 | CO_2 | 877 | SO_2 | 1692 | O3_2 | 801 | NO_2 | 825 | CO_3 | 841 | SO_3 | 1692 | O3_3 | 784 | NO_3 | 786
CO_1 | 847 | SO_1 | 1634 | O3_1 | 807 | NO_1 | 847 | CO_2 | 875 | SO_2 | 1692 | O3_2 | 797 | NO_2 | 825 | CO_3 | 840 | SO_3 | 1692 | O3_3 | 790 | NO_3 | 791
CO_1 | 847 | SO_1 | 1634 | O3_1 | 787 | NO_1 | 847 | CO_2 | 873 | SO_2 | 1692 | O3_2 | 798 | NO_2 | 825 | CO_3 | 841 | SO_3 | 1692 | O3_3 | 791 | NO_3 | 793
CO_1 | 847 | SO_1 | 1634 | O3_1 | 767 | NO_1 | 646 | CO_2 | 872 | SO_2 | 1692 | O3_2 | 794 | NO_2 | 823 | CO_3 | 841 | SO_3 | 1692 | O3_3 | 790 | NO_3 | 794
CO_1 | 847 | SO_1 | 1634 | O3_1 | 787 | NO_1 | 1009 | CO_2 | 870 | SO_2 | 1692 | O3_2 | 804 | NO_2 | 829 | CO_3 | 841 | SO_3 | 1692 | O3_3 | 797 | NO_3 | 798
CO_1 | 847 | SO_1 | 1634 | O3_1 | 807 | NO_1 | 767 | CO_2 | 870 | SO_2 | 1692 | O3_2 | 800 | NO_2 | 825 | CO_3 | 840 | SO_3 | 1692 | O3_3 | 794 | NO_3 | 797
CO_1 | 847 | SO_1 | 1634 | O3_1 | 807 | NO_1 | 847 | CO_2 | 868 | SO_2 | 1692 | O3_2 | 801 | NO_2 | 826 | CO_3 | 840 | SO_3 | 1692 | O3_3 | 799 | NO_3 | 801
CO_1 | 847 | SO_1 | 1634 | O3_1 | 787 | NO_1 | 646 | CO_2 | 867 | SO_2 | 1692 | O3_2 | 799 | NO_2 | 825 | CO_3 | 841 | SO_3 | 1692 | O3_3 | 796 | NO_3 | 798
CO_1 | 847 | SO_1 | 1634 | O3_1 | 807 | NO_1 | 888 | CO_2 | 865 | SO_2 | 1692 | O3_2 | 808 | NO_2 | 829 | CO_3 | 840 | SO_3 | 1692 | O3_3 | 801 | NO_3 | 802
CO_1 | 847 | SO_1 | 1634 | O3_1 | 767 | NO_1 | 807 | CO_2 | 866 | SO_2 | 1692 | O3_2 | 800 | NO_2 | 825 | CO_3 | 840 | SO_3 | 1692 | O3_3 | 797 | NO_3 | 800
CO_1 | 847 | SO_1 | 1634 | O3_1 | 787 | NO_1 | 928 | CO_2 | 867 | SO_2 | 1692 | O3_2 | 800 | NO_2 | 825 | CO_3 | 840 | SO_3 | 1692 | O3_3 | 804 | NO_3 | 807
CO_1 | 847 | SO_1 | 1634 | O3_1 | 807 | NO_1 | 484 | CO_2 | 866 | SO_2 | 1692 | O3_2 | 804 | NO_2 | 827 | CO_3 | 839 | SO_3 | 1692 | O3_3 | 802 | NO_3 | 805
CO_1 | 847 | SO_1 | 1634 | O3_1 | 807 | NO_1 | 605 | CO_2 | 864 | SO_2 | 1692 | O3_2 | 804 | NO_2 | 827 | CO_3 | 840 | SO_3 | 1692 | O3_3 | 802 | NO_3 | 804
CO_1 | 847 | SO_1 | 1634 | O3_1 | 807 | NO_1 | 1009 | CO_2 | 863 | SO_2 | 1692 | O3_2 | 794 | NO_2 | 822 | CO_3 | 838 | SO_3 | 1692 | O3_3 | 797 | NO_3 | 802
CO_1 | 847 | SO_1 | 1634 | O3_1 | 767 | NO_1 | 646 | CO_2 | 864 | SO_2 | 1692 | O3_2 | 797 | NO_2 | 824 | CO_3 | 839 | SO_3 | 1692 | O3_3 | 798 | NO_3 | 803
CO_1 | 847 | SO_1 | 1634 | O3_1 | 807 | NO_1 | 1251 | CO_2 | 861 | SO_2 | 1692 | O3_2 | 798 | NO_2 | 825 | CO_3 | 839 | SO_3 | 1692 | O3_3 | 804 | NO_3 | 807
CO_1 | 847 | SO_1 | 1634 | O3_1 | 807 | NO_1 | 646 | CO_2 | 861 | SO_2 | 1692 | O3_2 | 800 | NO_2 | 825 | CO_3 | 839 | SO_3 | 1692 | O3_3 | 798 | NO_3 | 803
CO_1 | 847 | SO_1 | 1634 | O3_1 | 807 | NO_1 | 847 | CO_2 | 861 | SO_2 | 1692 | O3_2 | 805 | NO_2 | 828 | CO_3 | 839 | SO_3 | 1692 | O3_3 | 805 | NO_3 | 808
CO_1 | 847 | SO_1 | 1634 | O3_1 | 807 | NO_1 | 928 | CO_2 | 862 | SO_2 | 1692 | O3_2 | 802 | NO_2 | 827 | CO_3 | 839 | SO_3 | 1692 | O3_3 | 808 | NO_3 | 811
CO_1 | 847 | SO_1 | 1634 | O3_1 | 807 | NO_1 | 807 | CO_2 | 860 | SO_2 | 1692 | O3_2 | 805 | NO_2 | 826 | CO_3 | 839 | SO_3 | 1692 | O3_3 | 801 | NO_3 | 803
CO_1 | 847 | SO_1 | 1634 | O3_1 | 807 | NO_1 | 928 | CO_2 | 861 | SO_2 | 1692 | O3_2 | 804 | NO_2 | 827 | CO_3 | 839 | SO_3 | 1692 | O3_3 | 802 | NO_3 | 806
CO_1 | 847 | SO_1 | 1634 | O3_1 | 807 | NO_1 | 646 | CO_2 | 861 | SO_2 | 1692 | O3_2 | 805 | NO_2 | 828 | CO_3 | 839 | SO_3 | 1692 | O3_3 | 804 | NO_3 | 808
CO_1 | 847 | SO_1 | 1634 | O3_1 | 807 | NO_1 | 807 | CO_2 | 860 | SO_2 | 1692 | O3_2 | 804 | NO_2 | 827 | CO_3 | 840 | SO_3 | 1692 | O3_3 | 802 | NO_3 | 808
CO_1 | 847 | SO_1 | 1634 | O3_1 | 807 | NO_1 | 888 | CO_2 | 860 | SO_2 | 1692 | O3_2 | 803 | NO_2 | 826 | CO_3 | 839 | SO_3 | 1692 | O3_3 | 802 | NO_3 | 807
CO_1 | 847 | SO_1 | 1634 | O3_1 | 807 | NO_1 | 1069 | CO_2 | 859 | SO_2 | 1692 | O3_2 | 805 | NO_2 | 827 | CO_3 | 839 | SO_3 | 1692 | O3_3 | 806 | NO_3 | 809
CO_1 | 847 | SO_1 | 1634 | O3_1 | 807 | NO_1 | 767 | CO_2 | 858 | SO_2 | 1692 | O3_2 | 808 | NO_2 | 830 | CO_3 | 839 | SO_3 | 1692 | O3_3 | 809 | NO_3 | 813
CO_1 | 847 | SO_1 | 1634 | O3_1 | 807 | NO_1 | 968 | CO_2 | 859 | SO_2 | 1692 | O3_2 | 804 | NO_2 | 827 | CO_3 | 839 | SO_3 | 1692 | O3_3 | 805 | NO_3 | 810
CO_1 | 847 | SO_1 | 1634 | O3_1 | 807 | NO_1 | 625 | CO_2 | 858 | SO_2 | 1692 | O3_2 | 809 | NO_2 | 829 | CO_3 | 839 | SO_3 | 1692 | O3_3 | 807 | NO_3 | 809
CO_1 | 847 | SO_1 | 1634 | O3_1 | 807 | NO_1 | 646 | CO_2 | 858 | SO_2 | 1692 | O3_2 | 809 | NO_2 | 830 | CO_3 | 838 | SO_3 | 1692 | O3_3 | 812 | NO_3 | 814
CO_1 | 847 | SO_1 | 1634 | O3_1 | 807 | NO_1 | 847 | CO_2 | 858 | SO_2 | 1692 | O3_2 | 807 | NO_2 | 828 | CO_3 | 838 | SO_3 | 1692 | O3_3 | 806 | NO_3 | 810
CO_1 | 847 | SO_1 | 1634 | O3_1 | 807 | NO_1 | 767 | CO_2 | 858 | SO_2 | 1692 | O3_2 | 808 | NO_2 | 830 | CO_3 | 839 | SO_3 | 1692 | O3_3 | 811 | NO_3 | 812
CO_1 | 847 | SO_1 | 1634 | O3_1 | 807 | NO_1 | 767 | CO_2 | 857 | SO_2 | 1692 | O3_2 | 810 | NO_2 | 830 | CO_3 | 839 | SO_3 | 1692 | O3_3 | 809 | NO_3 | 812
CO_1 | 850 | SO_1 | 1427 | O3_1 | 791 | NO_1 | 1116 | CO_2 | 858 | SO_2 | 1692 | O3_2 | 807 | NO_2 | 829 | CO_3 | 839 | SO_3 | 1692 | O3_3 | 807 | NO_3 | 811
CO_1 | 851 | SO_1 | 1239 | O3_1 | 796 | NO_1 | 758 | CO_2 | 856 | SO_2 | 1692 | O3_2 | 809 | NO_2 | 829 | CO_3 | 840 | SO_3 | 1692 | O3_3 | 814 | NO_3 | 817
CO_1 | 851 | SO_1 | 1136 | O3_1 | 789 | NO_1 | 539 | CO_2 | 856 | SO_2 | 1692 | O3_2 | 803 | NO_2 | 827 | CO_3 | 838 | SO_3 | 1692 | O3_3 | 809 | NO_3 | 812
CO_1 | 851 | SO_1 | 1083 | O3_1 | 792 | NO_1 | 732 | CO_2 | 856 | SO_2 | 1692 | O3_2 | 806 | NO_2 | 828 | CO_3 | 840 | SO_3 | 1692 | O3_3 | 812 | NO_3 | 815
CO_1 | 851 | SO_1 | 1052 | O3_1 | 789 | NO_1 | 1003 | CO_2 | 857 | SO_2 | 1692 | O3_2 | 803 | NO_2 | 826 | CO_3 | 838 | SO_3 | 1692 | O3_3 | 807 | NO_3 | 812
CO_1 | 850 | SO_1 | 1031 | O3_1 | 794 | NO_1 | 885 | CO_2 | 856 | SO_2 | 1692 | O3_2 | 804 | NO_2 | 826 | CO_3 | 838 | SO_3 | 1692 | O3_3 | 812 | NO_3 | 816
CO_1 | 851 | SO_1 | 1016 | O3_1 | 790 | NO_1 | 678 | CO_2 | 855 | SO_2 | 1692 | O3_2 | 804 | NO_2 | 827 | CO_3 | 840 | SO_3 | 1692 | O3_3 | 809 | NO_3 | 813
CO_1 | 851 | SO_1 | 1009 | O3_1 | 796 | NO_1 | 854 | CO_2 | 856 | SO_2 | 1692 | O3_2 | 807 | NO_2 | 828 | CO_3 | 839 | SO_3 | 1692 | O3_3 | 816 | NO_3 | 817
CO_1 | 851 | SO_1 | 1002 | O3_1 | 792 | NO_1 | 690 | CO_2 | 855 | SO_2 | 1692 | O3_2 | 810 | NO_2 | 830 | CO_3 | 838 | SO_3 | 1692 | O3_3 | 813 | NO_3 | 816
CO_1 | 850 | SO_1 | 998 | O3_1 | 801 | NO_1 | 786 | CO_2 | 855 | SO_2 | 1692 | O3_2 | 805 | NO_2 | 827 | CO_3 | 838 | SO_3 | 1692 | O3_3 | 807 | NO_3 | 812
CO_1 | 851 | SO_1 | 995 | O3_1 | 799 | NO_1 | 689 | CO_2 | 856 | SO_2 | 1692 | O3_2 | 805 | NO_2 | 827 | CO_3 | 838 | SO_3 | 1692 | O3_3 | 810 | NO_3 | 813
CO_1 | 850 | SO_1 | 984 | O3_1 | 797 | NO_1 | 891 | CO_2 | 856 | SO_2 | 1692 | O3_2 | 814 | NO_2 | 831 | CO_3 | 839 | SO_3 | 1692 | O3_3 | 811 | NO_3 | 813
CO_1 | 850 | SO_1 | 988 | O3_1 | 790 | NO_1 | 803 | CO_2 | 855 | SO_2 | 1692 | O3_2 | 806 | NO_2 | 827 | CO_3 | 838 | SO_3 | 1692 | O3_3 | 810 | NO_3 | 813
CO_1 | 851 | SO_1 | 986 | O3_1 | 791 | NO_1 | 773 | CO_2 | 855 | SO_2 | 1692 | O3_2 | 808 | NO_2 | 829 | CO_3 | 839 | SO_3 | 1692 | O3_3 | 812 | NO_3 | 814
CO_1 | 850 | SO_1 | 987 | O3_1 | 798 | NO_1 | 471 | CO_2 | 857 | SO_2 | 1692 | O3_2 | 804 | NO_2 | 826 | CO_3 | 840 | SO_3 | 1692 | O3_3 | 810 | NO_3 | 814
CO_1 | 851 | SO_1 | 994 | O3_1 | 783 | NO_1 | 860 | CO_2 | 855 | SO_2 | 1692 | O3_2 | 803 | NO_2 | 826 | CO_3 | 838 | SO_3 | 1692 | O3_3 | 807 | NO_3 | 812
CO_1 | 851 | SO_1 | 982 | O3_1 | 795 | NO_1 | 887 | CO_2 | 855 | SO_2 | 1692 | O3_2 | 808 | NO_2 | 829 | CO_3 | 838 | SO_3 | 1692 | O3_3 | 815 | NO_3 | 818
CO_1 | 850 | SO_1 | 986 | O3_1 | 797 | NO_1 | 1027 | CO_2 | 857 | SO_2 | 1692 | O3_2 | 806 | NO_2 | 826 | CO_3 | 838 | SO_3 | 1692 | O3_3 | 809 | NO_3 | 813
CO_1 | 851 | SO_1 | 986 | O3_1 | 792 | NO_1 | 791 | CO_2 | 855 | SO_2 | 1692 | O3_2 | 805 | NO_2 | 827 | CO_3 | 838 | SO_3 | 1692 | O3_3 | 813 | NO_3 | 819
CO_1 | 851 | SO_1 | 984 | O3_1 | 789 | NO_1 | 730 | CO_2 | 856 | SO_2 | 1692 | O3_2 | 805 | NO_2 | 828 | CO_3 | 838 | SO_3 | 1692 | O3_3 | 814 | NO_3 | 817
CO_1 | 851 | SO_1 | 981 | O3_1 | 788 | NO_1 | 858 | CO_2 | 853 | SO_2 | 1692 | O3_2 | 805 | NO_2 | 828 | CO_3 | 838 | SO_3 | 1692 | O3_3 | 811 | NO_3 | 813
CO_1 | 851 | SO_1 | 974 | O3_1 | 806 | NO_1 | 925 | CO_2 | 855 | SO_2 | 1692 | O3_2 | 814 | NO_2 | 832 | CO_3 | 838 | SO_3 | 1692 | O3_3 | 816 | NO_3 | 819
CO_1 | 850 | SO_1 | 975 | O3_1 | 800 | NO_1 | 606 | CO_2 | 854 | SO_2 | 1692 | O3_2 | 814 | NO_2 | 831 | CO_3 | 838 | SO_3 | 1692 | O3_3 | 818 | NO_3 | 819
CO_1 | 851 | SO_1 | 974 | O3_1 | 799 | NO_1 | 849 | CO_2 | 856 | SO_2 | 1692 | O3_2 | 808 | NO_2 | 828 | CO_3 | 839 | SO_3 | 1692 | O3_3 | 813 | NO_3 | 815
CO_1 | 850 | SO_1 | 975 | O3_1 | 793 | NO_1 | 562 | CO_2 | 853 | SO_2 | 1692 | O3_2 | 806 | NO_2 | 828 | CO_3 | 838 | SO_3 | 1692 | O3_3 | 811 | NO_3 | 815
CO_1 | 849 | SO_1 | 977 | O3_1 | 794 | NO_1 | 921 | CO_2 | 855 | SO_2 | 1692 | O3_2 | 806 | NO_2 | 827 | CO_3 | 838 | SO_3 | 1692 | O3_3 | 812 | NO_3 | 815
CO_1 | 850 | SO_1 | 971 | O3_1 | 800 | NO_1 | 842 | CO_2 | 852 | SO_2 | 1692 | O3_2 | 810 | NO_2 | 830 | CO_3 | 838 | SO_3 | 1692 | O3_3 | 815 | NO_3 | 819
CO_1 | 844 | SO_1 | 975 | O3_1 | 795 | NO_1 | 980 | CO_2 | 856 | SO_2 | 1692 | O3_2 | 819 | NO_2 | 829 | CO_3 | 834 | SO_3 | 1692 | O3_3 | 819 | NO_3 | 817
CO_1 | 854 | SO_1 | 974 | O3_1 | 797 | NO_1 | 680 | CO_2 | 854 | SO_2 | 1692 | O3_2 | 805 | NO_2 | 825 | CO_3 | 836 | SO_3 | 1692 | O3_3 | 813 | NO_3 | 849
CO_1 | 852 | SO_1 | 967 | O3_1 | 803 | NO_1 | 921 | CO_2 | 853 | SO_2 | 1692 | O3_2 | 810 | NO_2 | 832 | CO_3 | 838 | SO_3 | 1692 | O3_3 | 815 | NO_3 | 812
CO_1 | 851 | SO_1 | 970 | O3_1 | 800 | NO_1 | 924 | CO_2 | 852 | SO_2 | 1692 | O3_2 | 803 | NO_2 | 826 | CO_3 | 839 | SO_3 | 1692 | O3_3 | 808 | NO_3 | 820
CO_1 | 854 | SO_1 | 970 | O3_1 | 800 | NO_1 | 903 | CO_2 | 851 | SO_2 | 1693 | O3_2 | 803 | NO_2 | 829 | CO_3 | 839 | SO_3 | 1692 | O3_3 | 814 | NO_3 | 809
CO_1 | 851 | SO_1 | 968 | O3_1 | 798 | NO_1 | 462 | CO_2 | 851 | SO_2 | 1692 | O3_2 | 810 | NO_2 | 829 | CO_3 | 838 | SO_3 | 1692 | O3_3 | 812 | NO_3 | 819
CO_1 | 849 | SO_1 | 972 | O3_1 | 793 | NO_1 | 643 | CO_2 | 852 | SO_2 | 1573 | O3_2 | 810 | NO_2 | 828 | CO_3 | 838 | SO_3 | 1692 | O3_3 | 814 | NO_3 | 818
CO_1 | 849 | SO_1 | 963 | O3_1 | 808 | NO_1 | 697 | CO_2 | 854 | SO_2 | 1302 | O3_2 | 814 | NO_2 | 829 | CO_3 | 838 | SO_3 | 1581 | O3_3 | 821 | NO_3 | 825
CO_1 | 850 | SO_1 | 967 | O3_1 | 799 | NO_1 | 866 | CO_2 | 853 | SO_2 | 1190 | O3_2 | 810 | NO_2 | 829 | CO_3 | 838 | SO_3 | 1274 | O3_3 | 814 | NO_3 | 816
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

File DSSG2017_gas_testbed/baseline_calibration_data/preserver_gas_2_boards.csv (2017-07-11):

CO | 839 | SO | 1146 | O3 | 668 | NO | 770 | CO2 | 853 | SO2 | 613 | O32 | 1121 | NO2 | 930
CO | 845 | SO | 862 | O3 | 836 | NO | 836 | CO2 | 867 | SO2 | 611 | O32 | 1513 | NO2 | 850
CO | 844 | SO | 901 | O3 | 813 | NO | 824 | CO2 | 856 | SO2 | 653 | O32 | 666 | NO2 | 791
CO | 845 | SO | 880 | O3 | 861 | NO | 850 | CO2 | 518 | SO2 | 673 | O32 | 728 | NO2 | 863
CO | 845 | SO | 883 | O3 | 829 | NO | 837 | CO2 | 687 | SO2 | 583 | O32 | 831 | NO2 | 861
CO | 848 | SO | 898 | O3 | 821 | NO | 859 | CO2 | 757 | SO2 | 729 | O32 | 854 | NO2 | 836
CO | 847 | SO | 874 | O3 | 840 | NO | 838 | CO2 | 795 | SO2 | 668 | O32 | 1139 | NO2 | 837
CO | 846 | SO | 886 | O3 | 823 | NO | 833 | CO2 | 816 | SO2 | 705 | O32 | 879 | NO2 | 843
CO | 846 | SO | 893 | O3 | 832 | NO | 832 | CO2 | 831 | SO2 | 690 | O32 | 750 | NO2 | 809
CO | 846 | SO | 902 | O3 | 827 | NO | 829 | CO2 | 847 | SO2 | 699 | O32 | 772 | NO2 | 845
CO | 846 | SO | 904 | O3 | 825 | NO | 824 | CO2 | 848 | SO2 | 692 | O32 | 942 | NO2 | 843
CO | 845 | SO | 897 | O3 | 824 | NO | 825 | CO2 | 845 | SO2 | 647 | O32 | 849 | NO2 | 812
CO | 846 | SO | 905 | O3 | 843 | NO | 832 | CO2 | 857 | SO2 | 691 | O32 | 1015 | NO2 | 809
CO | 850 | SO | 868 | O3 | 824 | NO | 843 | CO2 | 854 | SO2 | 644 | O32 | 728 | NO2 | 851
CO | 844 | SO | 906 | O3 | 848 | NO | 848 | CO2 | 859 | SO2 | 677 | O32 | 932 | NO2 | 837
CO | 845 | SO | 894 | O3 | 812 | NO | 834 | CO2 | 850 | SO2 | 678 | O32 | 792 | NO2 | 826
CO | 846 | SO | 890 | O3 | 814 | NO | 808 | CO2 | 865 | SO2 | 724 | O32 | 882 | NO2 | 821
CO | 859 | SO | 1038 | O3 | 756 | NO | 686 | CO2 | 852 | SO2 | 607 | O32 | 716 | NO2 | 786
CO | 839 | SO | 973 | O3 | 798 | NO | 757 | CO2 | 841 | SO2 | 663 | O32 | 702 | NO2 | 767
CO | 842 | SO | 927 | O3 | 860 | NO | 843 | CO2 | 880 | SO2 | 645 | O32 | 764 | NO2 | 878
CO | 857 | SO | 862 | O3 | 843 | NO | 844 | CO2 | 1001 | SO2 | 704 | O32 | 917 | NO2 | 883
CO | 854 | SO | 884 | O3 | 839 | NO | 825 | CO2 | 1034 | SO2 | 680 | O32 | 833 | NO2 | 835
CO | 856 | SO | 915 | O3 | 828 | NO | 826 | CO2 | 975 | SO2 | 593 | O32 | 1027 | NO2 | 938
CO | 809 | SO | 1020 | O3 | 667 | NO | 876 | CO2 | 947 | SO2 | 601 | O32 | 781 | NO2 | 998
CO | 850 | SO | 827 | O3 | 870 | NO | 824 | CO2 | 901 | SO2 | 508 | O32 | 919 | NO2 | 839
CO | 833 | SO | 1009 | O3 | 611 | NO | 730 | CO2 | 856 | SO2 | 656 | O32 | 586 | NO2 | 797
CO | 853 | SO | 897 | O3 | 802 | NO | 848 | CO2 | 886 | SO2 | 694 | O32 | 689 | NO2 | 868
CO | 854 | SO | 864 | O3 | 844 | NO | 842 | CO2 | 870 | SO2 | 715 | O32 | 1066 | NO2 | 852
CO | 851 | SO | 954 | O3 | 760 | NO | 812 | CO2 | 858 | SO2 | 665 | O32 | 853 | NO2 | 824
CO | 851 | SO | 874 | O3 | 837 | NO | 840 | CO2 | 856 | SO2 | 702 | O32 | 612 | NO2 | 825
CO | 850 | SO | 859 | O3 | 841 | NO | 845 | CO2 | 841 | SO2 | 624 | O32 | 910 | NO2 | 842
CO | 849 | SO | 874 | O3 | 834 | NO | 829 | CO2 | 868 | SO2 | 678 | O32 | 892 | NO2 | 817
CO | 848 | SO | 870 | O3 | 835 | NO | 841 | CO2 | 874 | SO2 | 691 | O32 | 924 | NO2 | 845
CO | 811 | SO | 888 | O3 | 809 | NO | 783 | CO2 | 854 | SO2 | 384 | O32 | 896 | NO2 | 758
CO | 847 | SO | 949 | O3 | 808 | NO | 835 | CO2 | 869 | SO2 | 582 | O32 | 806 | NO2 | 907
CO | 817 | SO | 928 | O3 | 819 | NO | 787 | CO2 | 842 | SO2 | 700 | O32 | 716 | NO2 | 792
CO | 942 | SO | 771 | O3 | 927 | NO | 879 | CO2 | 908 | SO2 | 690 | O32 | 959 | NO2 | 854
CO | 850 | SO | 911 | O3 | 818 | NO | 836 | CO2 | 792 | SO2 | 664 | O32 | 828 | NO2 | 653
CO | 851 | SO | 868 | O3 | 838 | NO | 852 | CO2 | 786 | SO2 | 455 | O32 | 1032 | NO2 | 665
CO | 828 | SO | 952 | O3 | 754 | NO | 734 | CO2 | 546 | SO2 | 11 | O32 | 688 | NO2 | 536
CO | 848 | SO | 788 | O3 | 873 | NO | 898 | CO2 | 628 | SO2 | 136 | O32 | 846 | NO2 | 1030
CO | 858 | SO | 838 | O3 | 851 | NO | 853 | CO2 | 562 | SO2 | 244 | O32 | 866 | NO2 | 950
CO | 848 | SO | 872 | O3 | 838 | NO | 808 | CO2 | 596 | SO2 | 421 | O32 | 880 | NO2 | 866
CO | 847 | SO | 1039 | O3 | 760 | NO | 742 | CO2 | 700 | SO2 | 406 | O32 | 702 | NO2 | 822
CO | 848 | SO | 813 | O3 | 872 | NO | 850 | CO2 | 783 | SO2 | 471 | O32 | 848 | NO2 | 903
CO | 840 | SO | 1007 | O3 | 795 | NO | 731 | CO2 | 873 | SO2 | 463 | O32 | 1128 | NO2 | 763
CO | 853 | SO | 859 | O3 | 848 | NO | 917 | CO2 | 924 | SO2 | 770 | O32 | 662 | NO2 | 921
CO | 848 | SO | 877 | O3 | 830 | NO | 826 | CO2 | 900 | SO2 | 828 | O32 | 856 | NO2 | 820
CO | 874 | SO | 886 | O3 | 817 | NO | 831 | CO2 | 899 | SO2 | 772 | O32 | 958 | NO2 | 799
CO | 869 | SO | 865 | O3 | 817 | NO | 832 | CO2 | 902 | SO2 | 753 | O32 | 664 | NO2 | 848
CO | 852 | SO | 978 | O3 | 746 | NO | 761 | CO2 | 847 | SO2 | 493 | O32 | 967 | NO2 | 821
CO | 848 | SO | 951 | O3 | 783 | NO | 814 | CO2 | 904 | SO2 | 840 | O32 | 728 | NO2 | 894
CO | 846 | SO | 831 | O3 | 887 | NO | 881 | CO2 | 1116 | SO2 | 855 | O32 | 826 | NO2 | 876
CO | 845 | SO | 906 | O3 | 859 | NO | 886 | CO2 | 994 | SO2 | 819 | O32 | 1315 | NO2 | 884
CO | 839 | SO | 907 | O3 | 809 | NO | 815 | CO2 | 957 | SO2 | 633 | O32 | 701 | NO2 | 843
CO | 845 | SO | 955 | O3 | 763 | NO | 769 | CO2 | 930 | SO2 | 735 | O32 | 803 | NO2 | 771
CO | 846 | SO | 973 | O3 | 790 | NO | 847 | CO2 | 929 | SO2 | 709 | O32 | 743 | NO2 | 814
CO | 839 | SO | 973 | O3 | 788 | NO | 806 | CO2 | 933 | SO2 | 654 | O32 | 887 | NO2 | 838
CO | 850 | SO | 757 | O3 | 940 | NO | 894 | CO2 | 858 | SO2 | 781 | O32 | 984 | NO2 | 873
CO | 846 | SO | 832 | O3 | 841 | NO | 844 | CO2 | 868 | SO2 | 702 | O32 | 904 | NO2 | 851
CO | 830 | SO | 911 | O3 | 781 | NO | 808 | CO2 | 915 | SO2 | 686 | O32 | 755 | NO2 | 836
CO | 849 | SO | 901 | O3 | 817 | NO | 812 | CO2 | 855 | SO2 | 682 | O32 | 844 | NO2 | 807
CO | 846 | SO | 1035 | O3 | 705 | NO | 769 | CO2 | 882 | SO2 | 569 | O32 | 834 | NO2 | 811
CO | 853 | SO | 951 | O3 | 796 | NO | 824 | CO2 | 893 | SO2 | 531 | O32 | 754 | NO2 | 870
CO | 822 | SO | 927 | O3 | 814 | NO | 832 | CO2 | 863 | SO2 | 541 | O32 | 746 | NO2 | 833
CO | 844 | SO | 879 | O3 | 866 | NO | 866 | CO2 | 910 | SO2 | 744 | O32 | 1101 | NO2 | 874
CO | 849 | SO | 840 | O3 | 841 | NO | 858 | CO2 | 893 | SO2 | 642 | O32 | 1109 | NO2 | 908
CO | 818 | SO | 928 | O3 | 800 | NO | 792 | CO2 | 970 | SO2 | 281 | O32 | 800 | NO2 | 862
CO | 836 | SO | 968 | O3 | 779 | NO | 806 | CO2 | 1072 | SO2 | 701 | O32 | 759 | NO2 | 784
CO | 843 | SO | 919 | O3 | 826 | NO | 823 | CO2 | 1020 | SO2 | 1075 | O32 | 848 | NO2 | 878
CO | 839 | SO | 893 | O3 | 829 | NO | 836 | CO2 | 1318 | SO2 | 1696 | O32 | 646 | NO2 | 784
CO | 846 | SO | 896 | O3 | 815 | NO | 825 | CO2 | 1372 | SO2 | 1696 | O32 | 979 | NO2 | 846
CO | 846 | SO | 864 | O3 | 847 | NO | 840 | CO2 | 1261 | SO2 | 1695 | O32 | 1402 | NO2 | 901
CO | 850 | SO | 751 | O3 | 897 | NO | 923 | CO2 | 861 | SO2 | 1694 | O32 | 1694 | NO2 | 763
CO | 851 | SO | 793 | O3 | 849 | NO | 841 | CO2 | 717 | SO2 | 1694 | O32 | 568 | NO2 | 831
CO | 850 | SO | 795 | O3 | 879 | NO | 908 | CO2 | 634 | SO2 | 586 | O32 | 810 | NO2 | 881
CO | 849 | SO | 829 | O3 | 848 | NO | 849 | CO2 | 741 | SO2 | 187 | O32 | 954 | NO2 | 844
CO | 850 | SO | 846 | O3 | 848 | NO | 840 | CO2 | 786 | SO2 | 238 | O32 | 804 | NO2 | 838
CO | 855 | SO | 851 | O3 | 846 | NO | 841 | CO2 | 717 | SO2 | 288 | O32 | 765 | NO2 | 841
CO | 851 | SO | 886 | O3 | 841 | NO | 830 | CO2 | 627 | SO2 | 281 | O32 | 1057 | NO2 | 810
CO | 851 | SO | 881 | O3 | 834 | NO | 834 | CO2 | 642 | SO2 | 364 | O32 | 963 | NO2 | 843
CO | 844 | SO | 915 | O3 | 827 | NO | 829 | CO2 | 688 | SO2 | 309 | O32 | 743 | NO2 | 673
CO | 849 | SO | 936 | O3 | 802 | NO | 789 | CO2 | 750 | SO2 | 320 | O32 | 801 | NO2 | 821
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

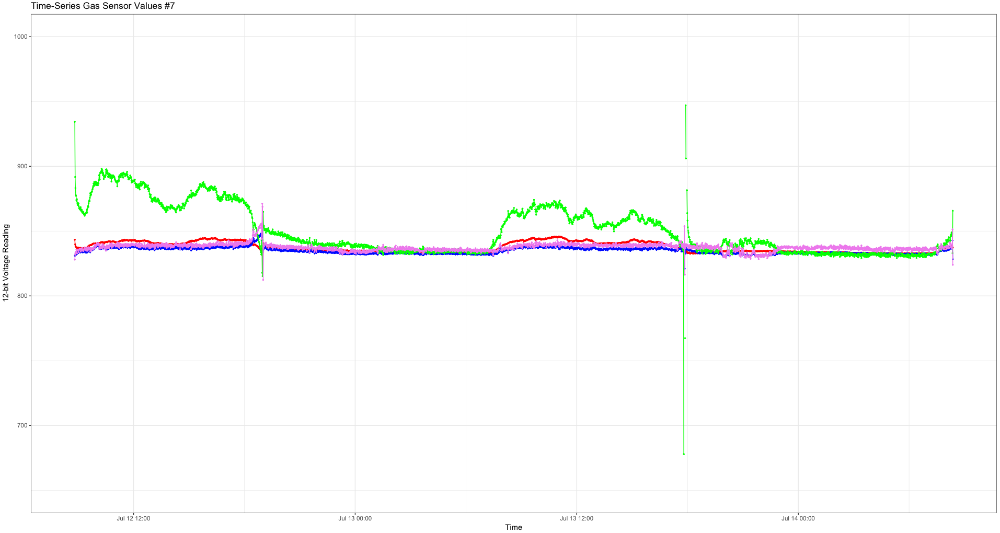
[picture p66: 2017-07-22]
DSSG2017_data/graphs/testbed_7.png

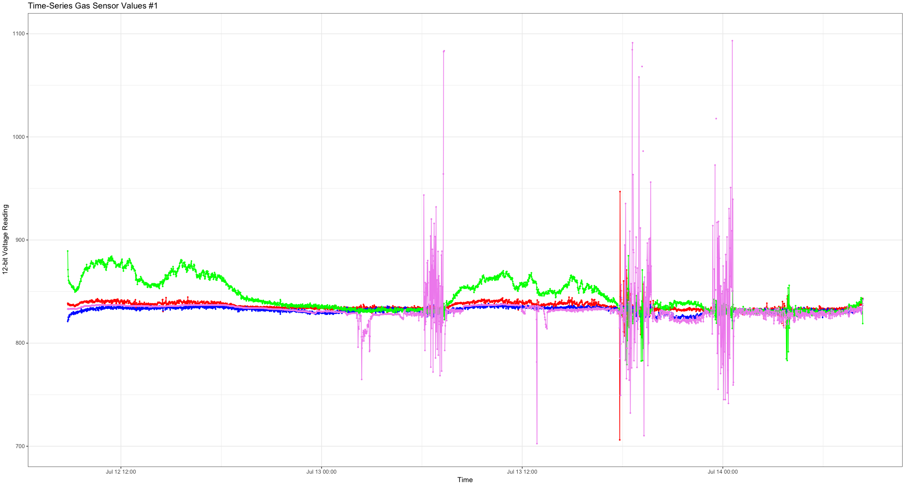
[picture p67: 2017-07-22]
DSSG2017_data/graphs/testbed_1.png

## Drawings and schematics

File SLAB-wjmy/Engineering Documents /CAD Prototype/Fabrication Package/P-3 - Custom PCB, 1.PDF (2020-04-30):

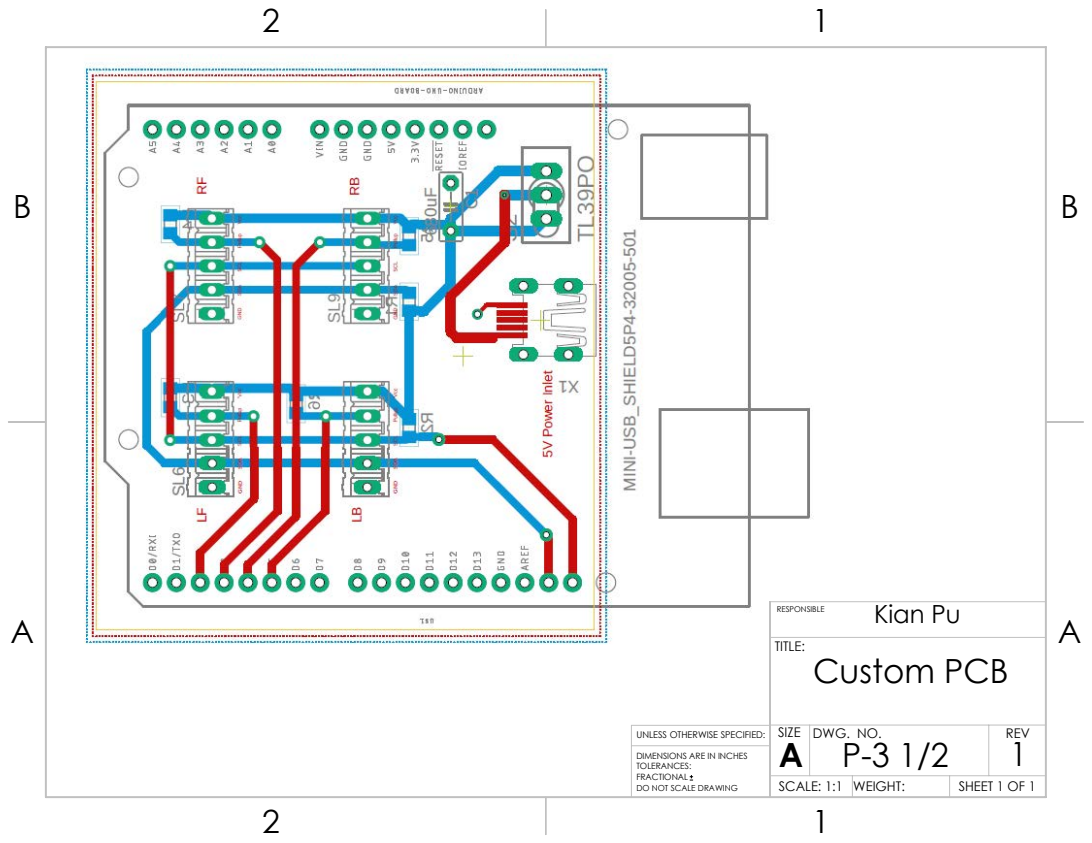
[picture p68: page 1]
Custom PCB; Kian Pu; SHEET 1 OF 1; SCALE: 1:1; WEIGHT:; DWG. NO.; REV

UNLESS OTHERWISE SPECIFIED:
DIMENSIONS ARE IN INCHES
TOLERANCES:
FRACTIONAL
DO NOT SCALE DRAWING

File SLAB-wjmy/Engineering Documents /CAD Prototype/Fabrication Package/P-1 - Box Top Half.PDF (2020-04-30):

Box Top Half; Andrew Dinka; SHEET 1 OF 1; SCALE: 1:2; WEIGHT:; DWG. NO.; REV

UNLESS OTHERWISE SPECIFIED:
DIMENSIONS ARE IN INCHES
TOLERANCES:
FRACTIONAL
DO NOT SCALE DRAWING

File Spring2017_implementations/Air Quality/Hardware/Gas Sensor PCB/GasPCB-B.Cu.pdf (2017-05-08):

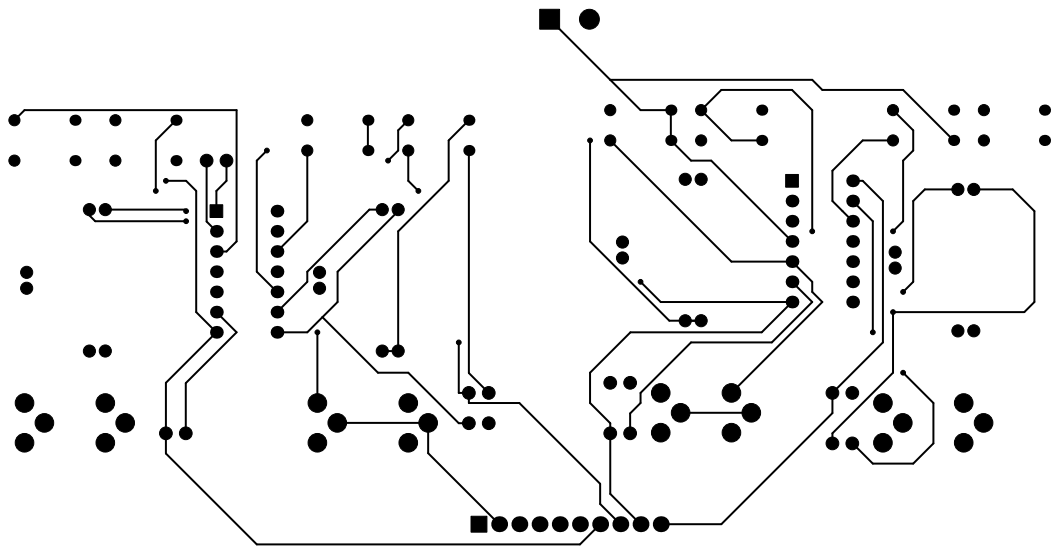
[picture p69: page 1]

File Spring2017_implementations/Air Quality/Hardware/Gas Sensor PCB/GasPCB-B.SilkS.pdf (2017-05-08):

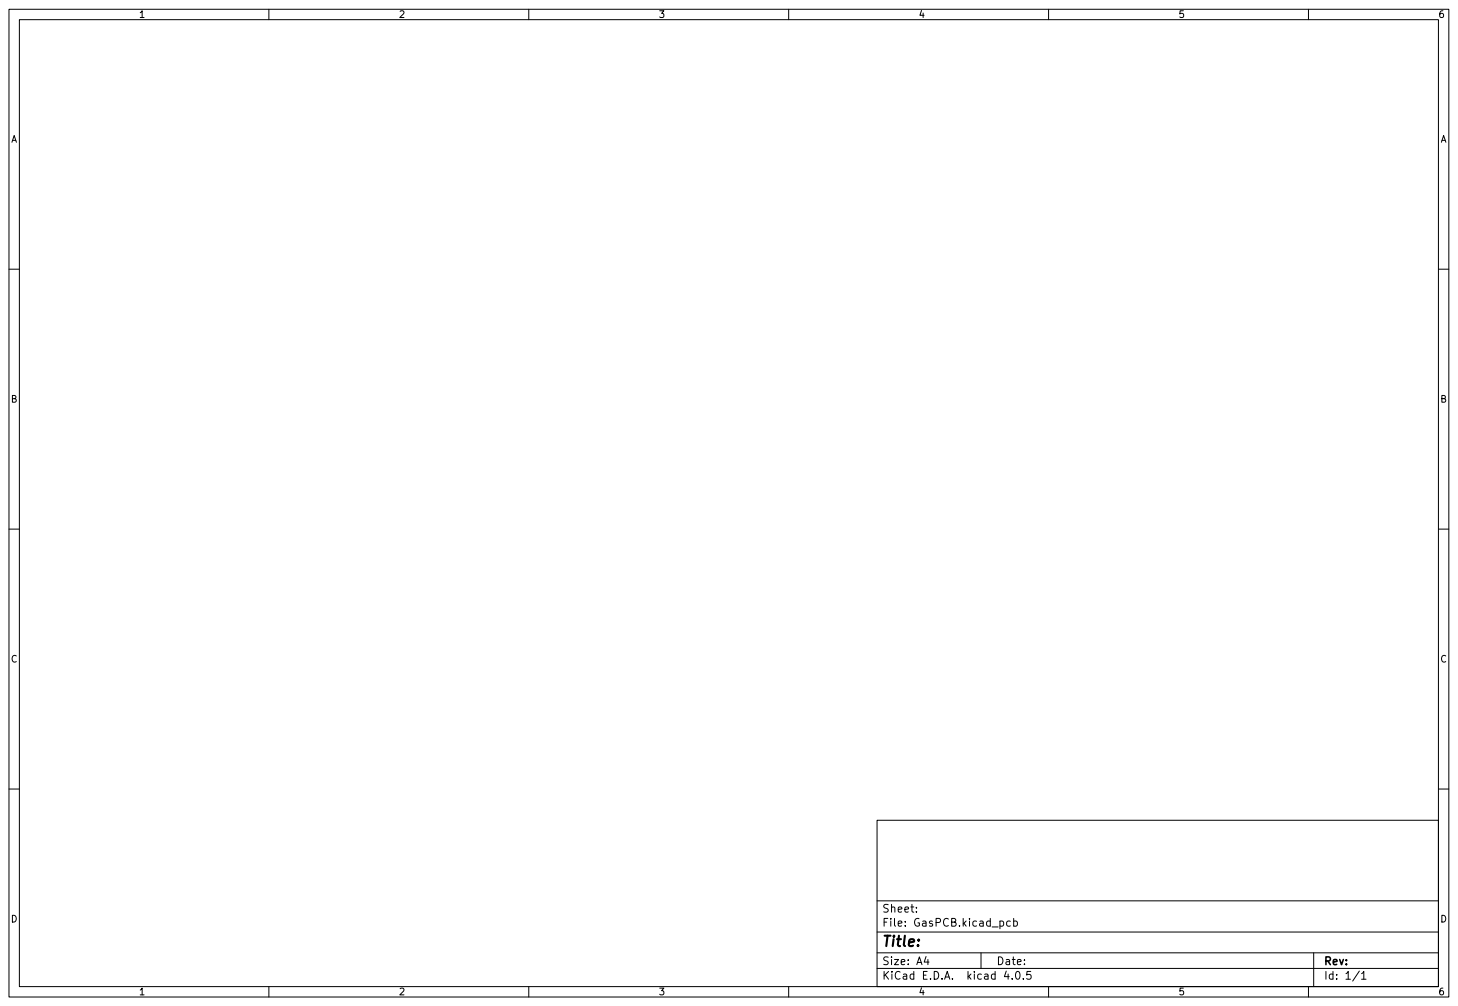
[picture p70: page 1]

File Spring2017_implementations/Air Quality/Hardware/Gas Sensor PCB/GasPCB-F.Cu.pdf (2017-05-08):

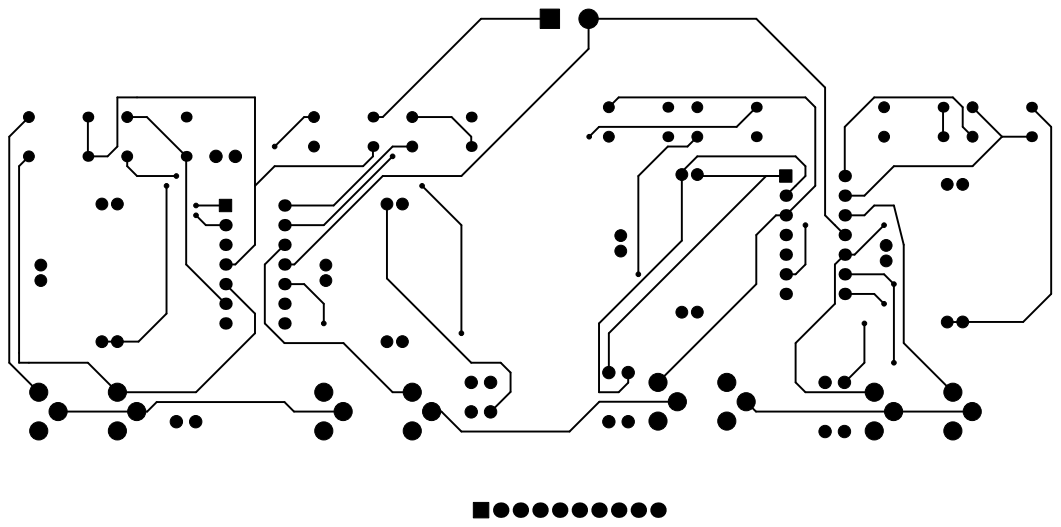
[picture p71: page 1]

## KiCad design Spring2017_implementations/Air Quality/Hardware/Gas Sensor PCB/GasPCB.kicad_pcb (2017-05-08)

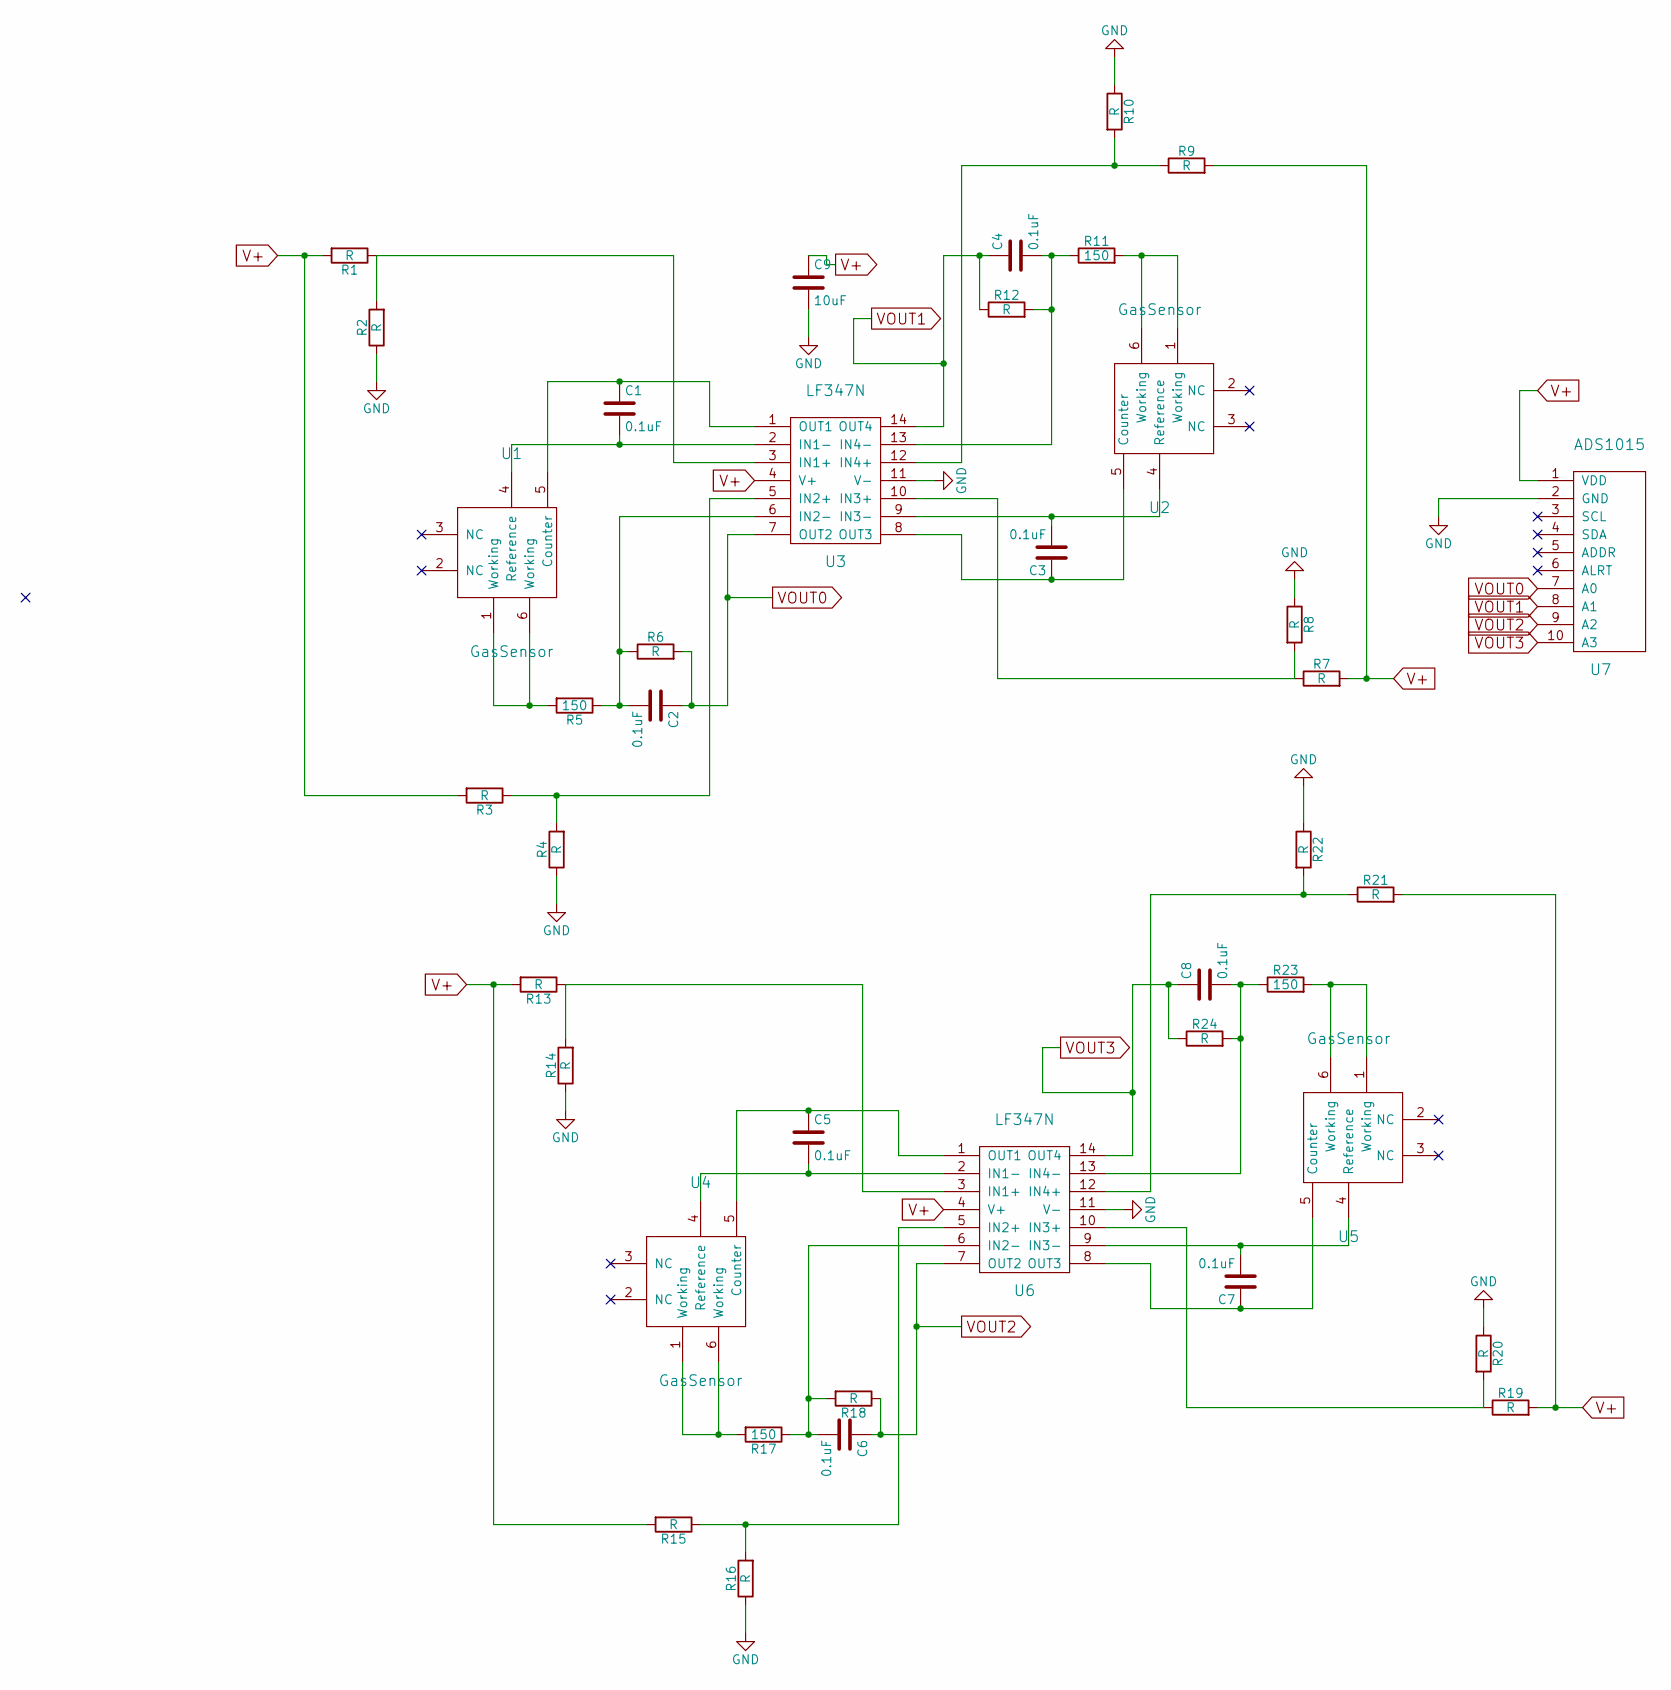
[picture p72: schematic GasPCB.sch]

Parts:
C1, C2, C3, C4, C5, C6, C7, C8: 0.1uF; C_Disc_D4.7mm_W2.5mm_P5.00mm
C9: 10uF; CP_Radial_Tantal_D8.0mm_P2.50mm
R1, R2, R3, R4, R6, R7, R8, R9, R10, R12, R13, R14, R15, R16, R18, R19, R20, R21, R22, R24: R; R_Axial_DIN0204_L3.6mm_D1.6mm_P7.62mm_Horizontal
R5, R11, R17, R23: 150; R_Axial_DIN0204_L3.6mm_D1.6mm_P7.62mm_Horizontal
U1, U2, U4, U5: GasSensor
U3, U6: LF347N; DIP-14_W7.62mm
U7: ADS1015; TerminalBlock_Pheonix_MPT-2.54mm_10pol

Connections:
GND: C9.2, R2.1, R4.1, R8.1, R10.1, R14.1, R16.1, R20.1, R22.1, U3.11 (V-), U6.11 (V-), U7.2 (GND)
unnamed: C1.1, U1.5 (Counter), U3.1 (OUT1)
unnamed: C1.2, U1.4 (Reference), U3.2 (IN1-)
unnamed: C2.2, R5.1, R6.1, U3.6 (IN2-)
unnamed: C3.1, U2.5 (Counter), U3.8 (OUT3)
unnamed: C3.2, U2.4 (Reference), U3.9 (IN3-)
unnamed: C4.2, R11.1, R12.2, U3.13 (IN4-)
unnamed: C5.1, U4.5 (Counter), U6.1 (OUT1)
unnamed: C5.2, U4.4 (Reference), U6.2 (IN1-)
unnamed: C6.2, R17.1, R18.2, U6.6 (IN2-)
unnamed: C7.1, U5.5 (Counter), U6.8 (OUT3)
unnamed: C7.2, U5.4 (Reference), U6.9 (IN3-)
unnamed: C8.2, R23.1, R24.2, U6.13 (IN4-)
unnamed: R1.1, R2.2, U3.3 (IN1+)
unnamed: R3.1, R4.2, U3.5 (IN2+)
unnamed: R5.2, U1.1 (Working), U1.6 (Working)
unnamed: R7.1, R8.2, U3.10 (IN3+)
unnamed: R9.1, R10.2, U3.12 (IN4+)
unnamed: R11.2, U2.1 (Working), U2.6 (Working)
unnamed: R13.1, R14.2, U6.3 (IN1+)
unnamed: R15.1, R16.2, U6.5 (IN2+)
unnamed: R17.2, U4.1 (Working), U4.6 (Working)
unnamed: R19.1, R20.2, U6.10 (IN3+)
unnamed: R21.1, R22.2, U6.12 (IN4+)
unnamed: R23.2, U5.1 (Working), U5.6 (Working)
V+: C9.1, R1.2, R3.2, R7.2, R9.2, R13.2, R15.2, R19.2, R21.2, U3.4 (V+), U6.4 (V+), U7.1 (VDD)
VOUT0: C2.1, R6.2, U3.7 (OUT2), U7.7 (A0)
VOUT1: C4.1, R12.1, U3.14 (OUT4), U7.8 (A1)
VOUT2: C6.1, R18.1, U6.7 (OUT2), U7.9 (A2)
VOUT3: C8.1, R24.1, U6.14 (OUT4), U7.10 (A3)

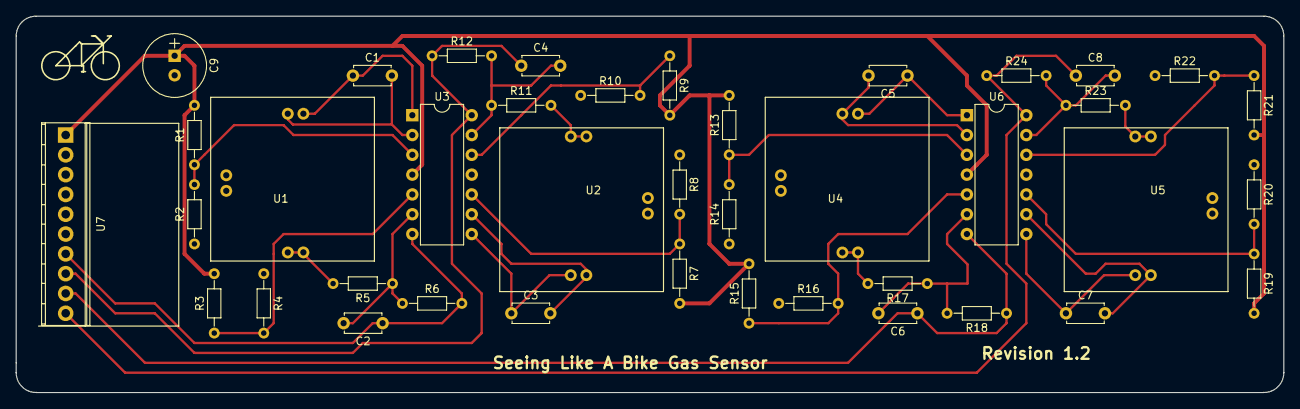
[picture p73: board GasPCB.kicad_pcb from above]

Board: 2 copper layers, 162.6 x 48.3 mm, 40 parts (0 on the bottom side), 30 nets.

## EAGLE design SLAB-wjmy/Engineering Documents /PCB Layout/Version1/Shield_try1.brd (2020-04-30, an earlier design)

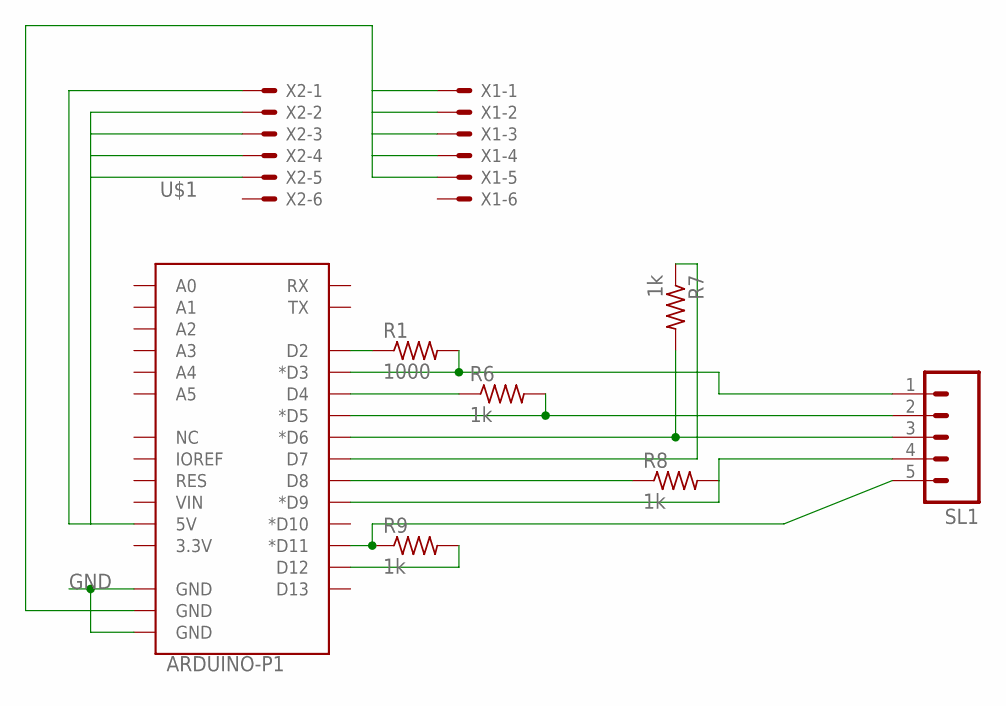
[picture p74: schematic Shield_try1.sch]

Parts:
R1: 1000; R0805
R6, R7, R8, R9: 1k; R0805
SL1: M05; 05P
U$1: ARDUINO-P1
X1, X2: 22-23-2061

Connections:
GND: U$1.GND@0 (GND), U$1.GND@1 (GND), U$1.GND@2 (GND), X1.1, X1.2, X1.3, X1.4, X1.5
unnamed: R1.2, SL1.1, U$1.D3 (*D3)
unnamed: R7.2, SL1.3, U$1.D6 (*D6)
unnamed: R6.1, U$1.D4
unnamed: R6.2, SL1.2, U$1.D5 (*D5)
unnamed: R7.1, U$1.D7
unnamed: R8.1, U$1.D8
unnamed: R8.2, SL1.4, U$1.D9 (*D9)
unnamed: R9.1, SL1.5, U$1.D11 (*D11)
unnamed: R9.2, U$1.D12
unnamed: R1.1, U$1.D2
unnamed: U$1.5V, X2.1, X2.2, X2.3, X2.4, X2.5

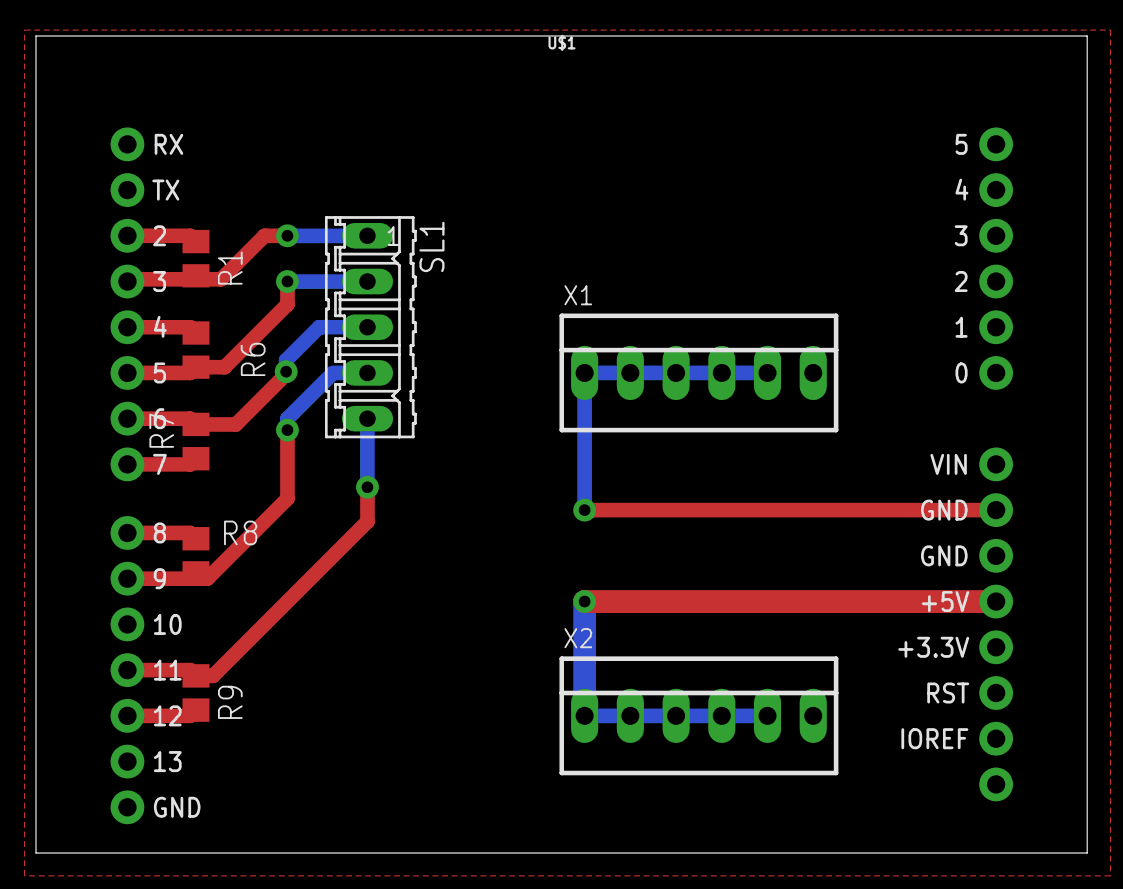
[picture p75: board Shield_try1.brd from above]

Board: 2 copper layers, 58.4 x 45.4 mm, 9 parts (0 on the bottom side), 12 nets.

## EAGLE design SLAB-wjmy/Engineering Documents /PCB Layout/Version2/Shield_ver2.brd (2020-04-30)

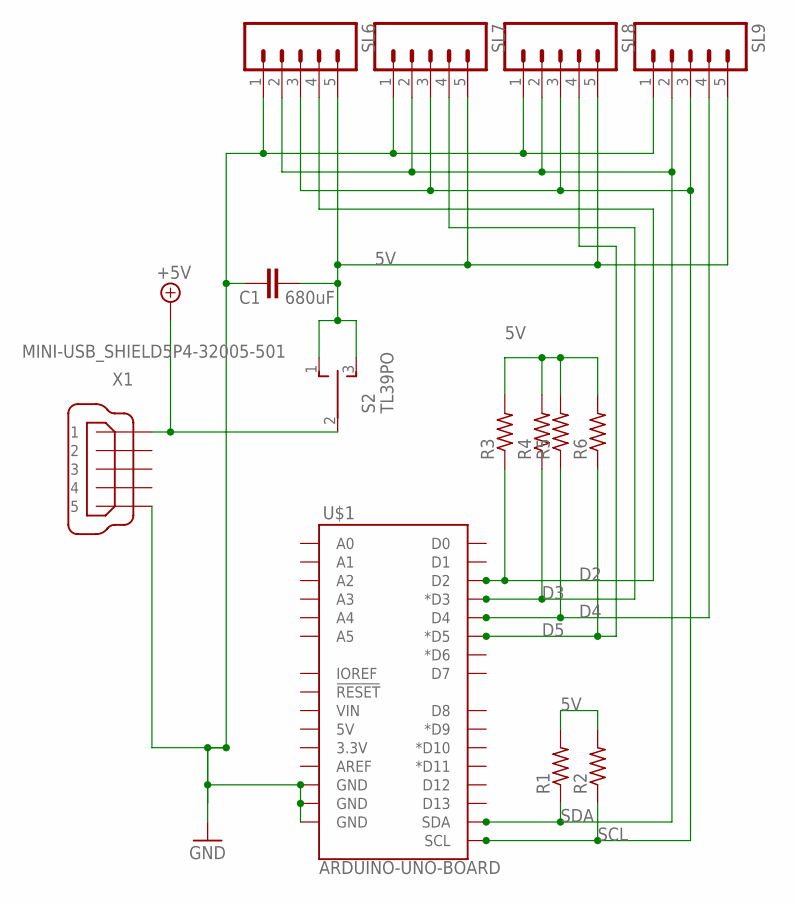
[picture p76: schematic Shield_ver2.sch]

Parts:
C1: 680uF; C5B2.5
R1, R2, R3, R4, R5, R6: R-US_R0805; R0805
S2: TL39PO; TL3XPO
SL6, SL7, SL8, SL9: M05; 05P
U$1: ARDUINO-UNO-BOARD
X1: MINI-USB_SHIELD5P4-32005-501; 32005-501

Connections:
5V: C1.2, R1.2, R2.2, R3.2, R4.2, R5.2, R6.2, S2.1 (O), S2.3 (S), SL6.5, SL7.5, SL8.5, SL9.5
+5V: S2.2, X1.1
D2: R3.1, SL6.4, U$1.D2
D3: R4.1, SL7.4, U$1.D3 (*D3)
D4: R5.1, SL9.4, U$1.D4
D5: R6.1, SL8.4, U$1.D5 (*D5)
GND: C1.1, SL6.1, SL7.1, SL8.1, SL9.1, U$1.GND@1 (GND), U$1.GND@2 (GND), U$1.GND@3 (GND), X1.5
SCL: R2.1, SL6.3, SL7.3, SL8.3, SL9.3, U$1.SCL
SDA: R1.1, SL6.2, SL7.2, SL8.2, SL9.2, U$1.SDA

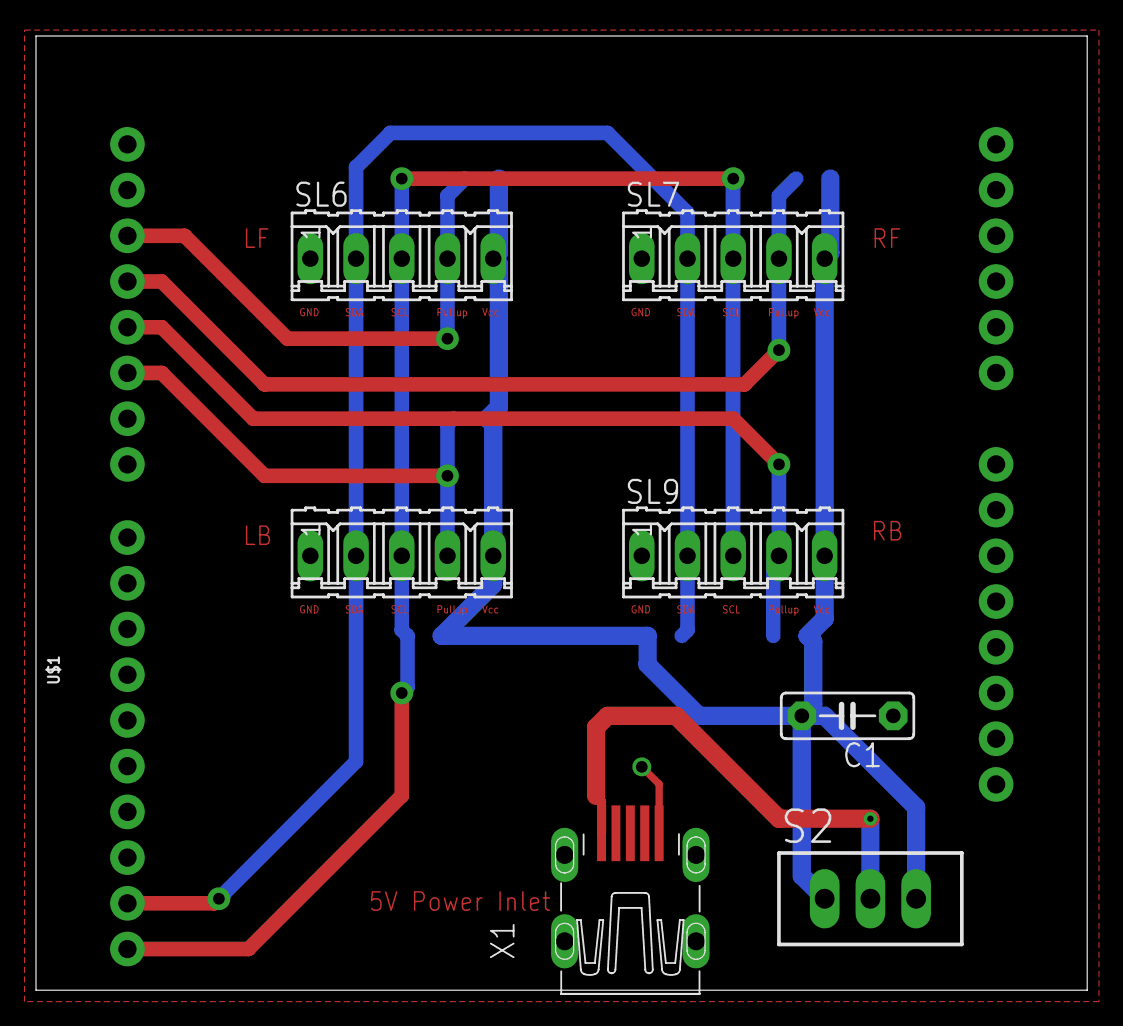
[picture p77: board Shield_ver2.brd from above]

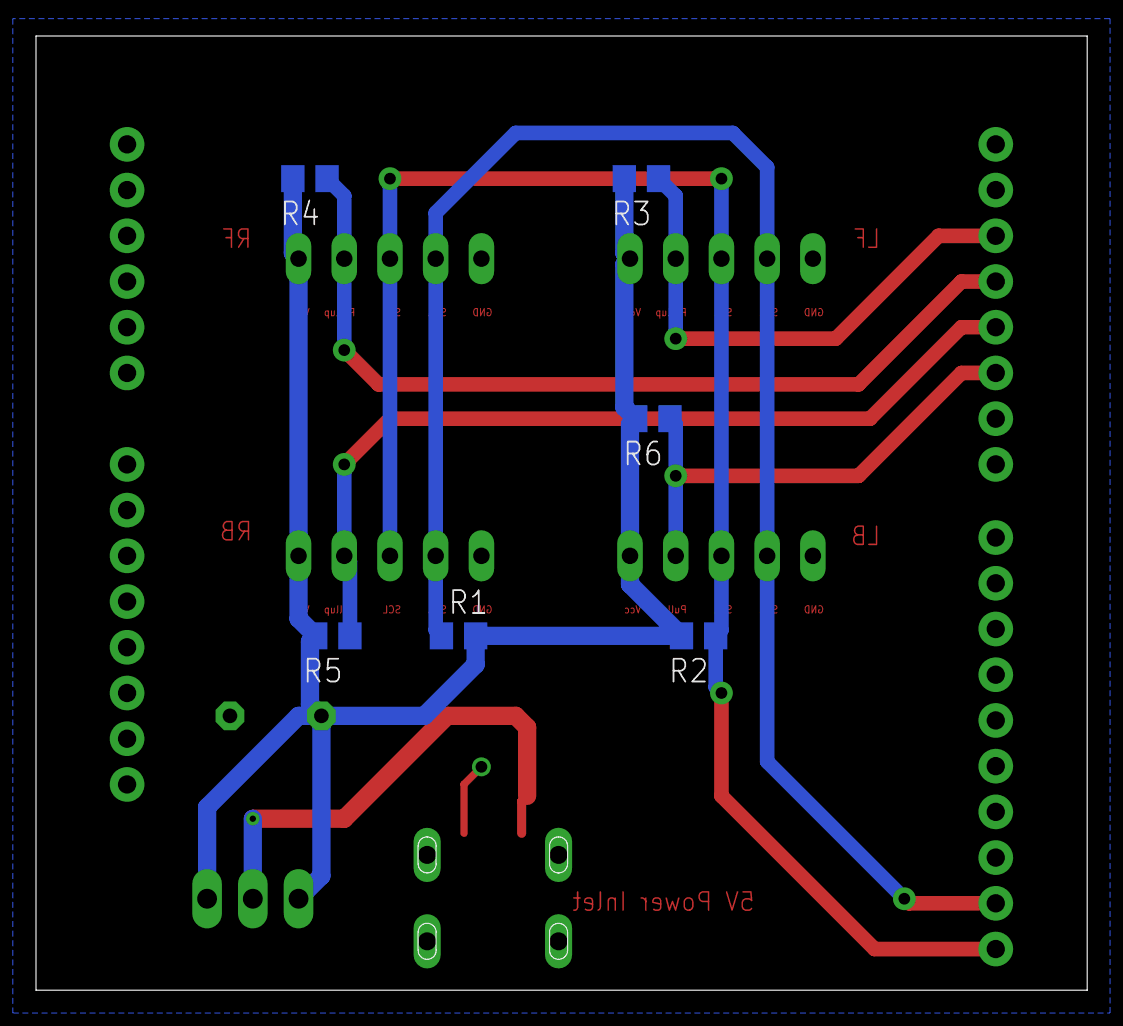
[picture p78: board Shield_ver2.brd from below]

Board: 2 copper layers, 58.4 x 53.0 mm, 14 parts (6 on the bottom side), 9 nets.

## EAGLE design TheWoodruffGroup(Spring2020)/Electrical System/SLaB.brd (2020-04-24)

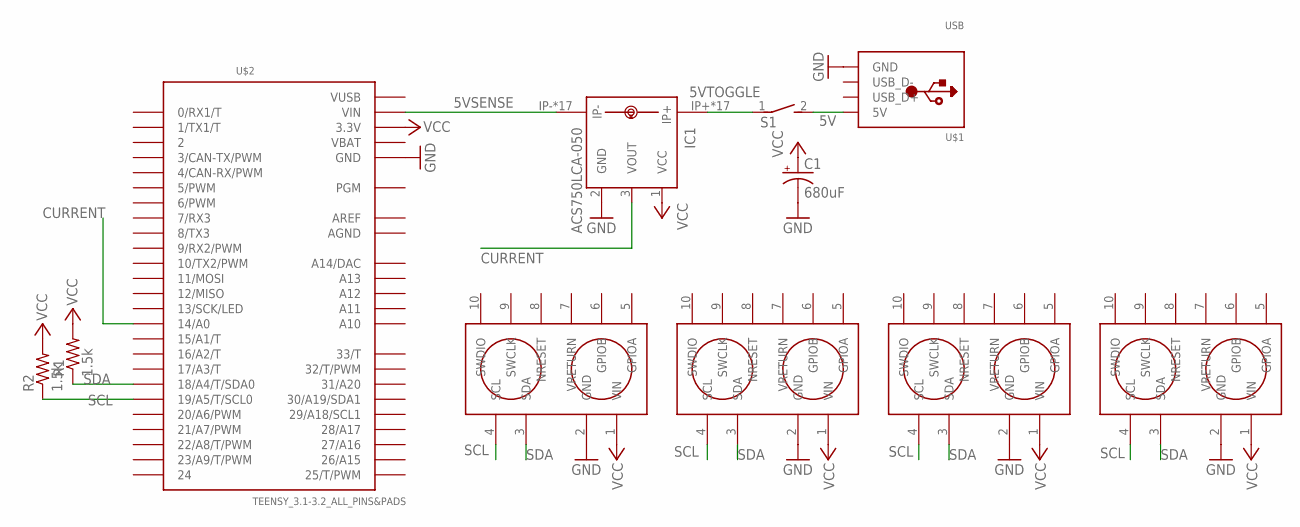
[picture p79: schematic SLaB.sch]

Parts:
C1: 680uF; E2-5
IC1: ACS750LCA-050; ACS75050
R1, R2: 1.5k; 0204/7
S1: DS01E; DS-01
U$1: USB
U$2: TEENSY_3.1-3.2_ALL_PINS&PADS; TEENSY_3.0-3.2_ALL_PINS_&_PADS
U$3, U$4, U$5, U$6: LIDAR

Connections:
5V: S1.2, U$1.5V
5VSENSE: IC1.IP-, IC1.IP-@2 (IP-), IC1.IP-@3 (IP-), IC1.IP-@4 (IP-), IC1.IP-@5 (IP-), IC1.IP-@6 (IP-), IC1.IP-@7 (IP-), IC1.IP-@8 (IP-), IC1.IP-@9 (IP-), IC1.IP-@10 (IP-), IC1.IP-@11 (IP-), IC1.IP-@12 (IP-), IC1.IP-@13 (IP-), IC1.IP-@14 (IP-), IC1.IP-@15 (IP-), IC1.IP-@16 (IP-), IC1.IP-@17 (IP-), U$2.VIN
5VTOGGLE: IC1.IP+, IC1.IP+@2 (IP+), IC1.IP+@3 (IP+), IC1.IP+@4 (IP+), IC1.IP+@5 (IP+), IC1.IP+@6 (IP+), IC1.IP+@7 (IP+), IC1.IP+@8 (IP+), IC1.IP+@9 (IP+), IC1.IP+@10 (IP+), IC1.IP+@11 (IP+), IC1.IP+@12 (IP+), IC1.IP+@13 (IP+), IC1.IP+@14 (IP+), IC1.IP+@15 (IP+), IC1.IP+@16 (IP+), IC1.IP+@17 (IP+), S1.1
AGND: U$2.AGND
AREF: U$2.AREF
CURRENT: IC1.3 (VOUT), U$2.14/A0
GND: C1.-, IC1.2 (GND), U$1.GND, U$2.GND, U$2.GND1 (GND), U$2.GND2 (GND), U$3.2 (GND), U$4.2 (GND), U$5.2 (GND), U$6.2 (GND)
SCL: R2.1, U$2.19/A5 (19/A5/T/SCL0), U$3.4 (SCL), U$4.4 (SCL), U$5.4 (SCL), U$6.4 (SCL)
SDA: R1.1, U$2.18/A4 (18/A4/T/SDA0), U$3.3 (SDA), U$4.3 (SDA), U$5.3 (SDA), U$6.3 (SDA)
VBAT: U$2.VBAT
VCC: C1.+, IC1.1 (VCC), R1.2, R2.2, U$2.3.3V, U$2.3.3V1 (3.3V), U$2.3.3V2 (3.3V), U$3.1 (VIN), U$4.1 (VIN), U$5.1 (VIN), U$6.1 (VIN)
VUSB: U$2.VUSB

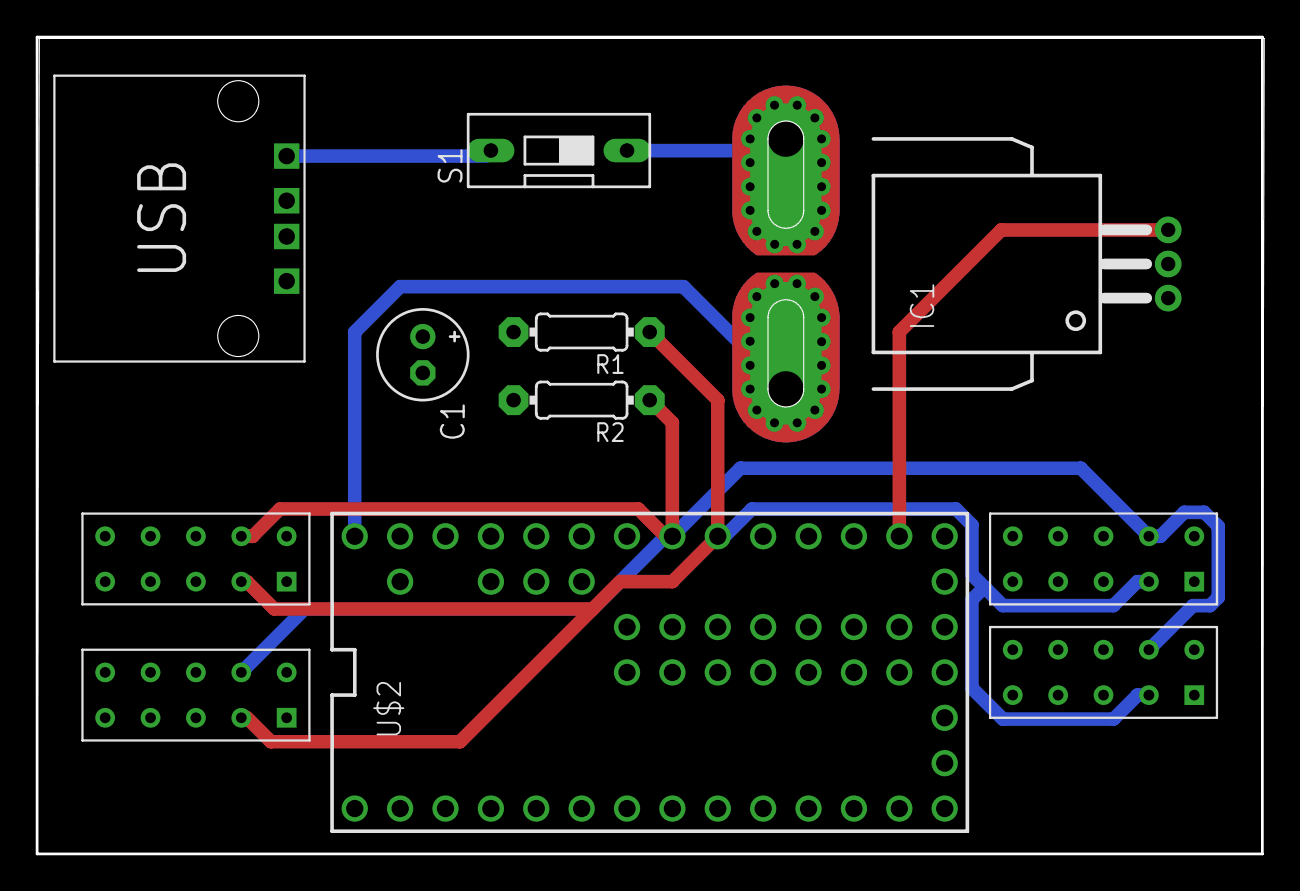
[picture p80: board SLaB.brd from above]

Board: 2 copper layers, 68.7 x 45.7 mm, 11 parts (0 on the bottom side), 8 nets.

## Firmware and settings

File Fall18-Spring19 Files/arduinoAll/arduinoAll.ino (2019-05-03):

#include <NeoSWSerial.h>


//SDS011 Nova PM sensor
//Includes code from: https://learn.adafruit.com/pm25-air-quality-sensor/arduino-code

#include <Wire.h>
#include <Adafruit_ADS1015.h>
#include <stdio.h>
#include <LIDARLite.h>
//#include <SDS011.h> //for Nova PM Sensor
   
LIDARLite myLidarLite;
//SDS011 my_sds;
//PMS sensor 1 is at pin 10 and PMS sensor 2 is at pin 11
NeoSWSerial one(10, 7);
NeoSWSerial two(11,8);
uint16_t curr = 0;
//change to true if you would like to see adafruit's original output
boolean debug = false;
boolean JSONready = false;

//init for Lidar sensors. Assigning memory addresses.
int sensorPins[] = {2, 4}; // Array of pins connected to the sensor Power Enable lines
unsigned char addresses[] = {0x66, 0x68};

//for Sonar init
const int anPin1 = 0;
const int anPin2 = 1;
const int anPin3 = 2;
const int triggerPin1 = 13;

//for Gases sensor init
// ADS address needs to be set appropriately based on the gas sensor number (among 0x48, 0x49, 0x4A, 0x4B)
Adafruit_ADS1015 ads;    

// PM
float p10, p25;
int error;

// Reset Pin
int resetPin = 12;

void setup() {
  
  digitalWrite(resetPin, HIGH);
  delay(200);
  pinMode(resetPin, OUTPUT);     
  Wire.begin();       //join i2c bus
  //my_sds.begin(10, 11);   //start Nova PM sensor with digital pins 10 and 11
  //Serial.begin(9600, SERIAL_7E1); //start serial for output
  Serial.begin(9600, SERIAL_8N1);
  ads.begin();
  //begin the two PMS sensors
  one.begin(9600);
  two.begin(9600);
//  ads.setGain(GAIN_ONE);
  myLidarLite.begin();
  myLidarLite.changeAddressMultiPwrEn(2, sensorPins, addresses);
  pinMode(triggerPin1, OUTPUT); 
}

//creates struct to put PMS data in
struct pms5003data {
  uint16_t framelen;
  uint16_t pm10_standard, pm25_standard, pm100_standard;
  uint16_t pm10_env, pm25_env, pm100_env;
  uint16_t particles_03um, particles_05um, particles_10um, particles_25um, particles_50um, particles_100um;
  uint16_t unused;
  uint16_t checksum;
};

//firstData holds data from sensor 1 until 2 is ready
struct pms5003data data;
struct pms5003data firstData;

//SONAR SENSORS
void start_sensor() {
  digitalWrite(triggerPin1, HIGH);
  delay(1);
  digitalWrite(triggerPin1, LOW);
}

//GASES SENSORS
float *get_gas_values() {
  static float values[4];
  int Vx[4];
  float Ix[4];
  
  //initialising base voltage and current values for each gas
  Vx[0] = 818;
  Vx[1] = 823;
  Vx[2] = 812;
  Vx[3] = 810;
  Ix[0] = 0.00000000475;
  Ix[1] = 0.000000025;
  Ix[2] = 0.000000032;
  Ix[3] = 0.0000000040;

  //adjusting sensor values
  for (int i = 0; i < 4; i++) {
    //values[i] = (ads.readADC_SingleEnded(i) - Vx[i]) / (500000 * Ix[i]);
    values[i] = ads.readADC_SingleEnded(i);
    delay(10);
  }
  return values;
}

void print_gas() {
  String gas[4];
  gas[0] = "CO";
  gas[1] = "SO";
  gas[2] = "O3";
  gas[3] = "NO";
  float *v = get_gas_values();
  
  for (int i = 0; i < 4; i++) {
    Serial.print(gas[i] + " ");
    Serial.print(v[i]);
    Serial.print(" ");
  }
}

//LIDAR SENSORS
float* get_lidar_distance() {
  static float lidars[2];
  lidars[0] = myLidarLite.distance(true, true, 0x66);
  lidars[1]  = myLidarLite.distance(true, true, 0x68);
  return lidars;
}

void print_lidar() {
  float *lidars = get_lidar_distance();
  Serial.print("Lidar1 ");
  Serial.print(lidars[0]);
  Serial.print(" ");
  Serial.print("Lidar2 ");
  Serial.print(lidars[1]);
  Serial.print(" ");
}


float *get_sonar_values() {
  /*
    Scale factor is (Vcc/512) per inch. A 5V supply yields ~9.8mV/in
    Arduino analog pin goes from 0 to 1024, so the value has to be divided by 2 to get the actual inches
  */
  static float distance[3];
  distance[0] = analogRead(anPin1) / 2;
  distance[1] = analogRead(anPin2) / 2;
  distance[2] = analogRead(anPin3) / 2;
  
  return distance;
}

void print_sonar() {
  float *dists = get_sonar_values();
  Serial.print("SONAR1 ");
  Serial.print(dists[0] * 2.54);
  Serial.print(" SONAR2 ");
  Serial.print(dists[1] * 2.54);
  Serial.print(" SONAR3 ");
  Serial.print(dists[2] * 2.54);
  Serial.print(" ");
}
//old PM code 
/*
void print_pm() { 
  p10 = 0;
  p25= 0;
  error = my_sds.read(&p25, &p10);
  if (!error) {
    Serial.print("P25 " + String(p25) + " ");
    Serial.print("P10 " + String(p10) + " ");
  }
}
*/


//prints the data
void printJSON(){
  JSONready = false;
  Serial.print("PMS1 {pm10_standard:"); Serial.print(firstData.pm10_standard); Serial.print(",");
  Serial.print("pm25_standard:"); Serial.print(firstData.pm25_standard); Serial.print(",");
  Serial.print("pm100_standard:"); Serial.print(firstData.pm100_standard); Serial.print(",");

  Serial.print("pm10_env:"); Serial.print(firstData.pm10_env); Serial.print(",");
  Serial.print("pm25_env:"); Serial.print(firstData.pm25_env); Serial.print(",");
  Serial.print("pm100_env:"); Serial.print(firstData.pm100_env); Serial.print(",");

  Serial.print("particles_03um:"); Serial.print(firstData.particles_03um); Serial.print(",");
  Serial.print("particles_05um:"); Serial.print(firstData.particles_05um); Serial.print(",");
  Serial.print("particles_10um:"); Serial.print(firstData.particles_10um); Serial.print(",");
  Serial.print("particles_25um:"); Serial.print(firstData.particles_25um); Serial.print(",");
  Serial.print("particles_50um:"); Serial.print(firstData.particles_50um); Serial.print(",");
  Serial.print("particles_100um:"); Serial.print(firstData.particles_100um); Serial.print("} ");
      
  Serial.print("PMS2 {pm10_standard:"); Serial.print(data.pm10_standard); Serial.print(",");
  Serial.print("pm25_standard:"); Serial.print(data.pm25_standard); Serial.print(",");
  Serial.print("pm100_standard:"); Serial.print(data.pm100_standard); Serial.print(",");

  Serial.print("pm10_env:"); Serial.print(data.pm10_env); Serial.print(",");
  Serial.print("pm25_env:"); Serial.print(data.pm25_env); Serial.print(",");
  Serial.print("pm100_env:"); Serial.print(data.pm100_env); Serial.print(",");

  Serial.print("particles_03um:"); Serial.print(data.particles_03um); Serial.print(",");
  Serial.print("particles_05um:"); Serial.print(data.particles_05um); Serial.print(",");
  Serial.print("particles_10um:"); Serial.print(data.particles_10um); Serial.print(",");
  Serial.print("particles_25um:"); Serial.print(data.particles_25um); Serial.print(",");
  Serial.print("particles_50um:"); Serial.print(data.particles_50um); Serial.print(",");
  Serial.print("particles_100um:"); Serial.print(data.particles_100um); Serial.print("} ");
}

boolean readPMSdata(Stream *s) {
  //Serial.print("!!!");
  if(one.available()) {
    //Serial.println("one");
  }
  if(two.available()) {
    //Serial.println("two");
  }
  if (! s->available()) {
    //Serial.print(".");
    return false;
  }
  
  // Read a byte at a time until we get to the special '0x42' start-byte
  uint16_t first = s->read();
  if (first != 0x42) {
    //Serial.println("~");
    return false;
  }
//  Serial.println("!");
//  Serial.print("first: ");
//  Serial.println(first);
//  Serial.println("");
 
  // Now read all 32 bytes
  uint16_t avail = s->available();
  if (avail < 30) {
    //Serial.println("read");
    //Serial.println(avail);
    return false;
  }
  
  //Serial.println("Starting buffer stuff");
  uint8_t buffer[31];    
  uint16_t sum = 0;
  s->readBytes(buffer, 31);
//  Serial.println("buffer one:");
//  for (uint8_t i=0; i<31; i++) {
//    Serial.print("0x"); Serial.print(buffer[i], HEX); Serial.print(", ");
//  }
//  Serial.println("");
  uint8_t bufferTwo[32];
//  Serial.println("buffer two:");
//  for (uint8_t i=0; i<32; i++) {
//    Serial.print("0x"); Serial.print(bufferTwo[i], HEX); Serial.print(", ");
//  }
//  Serial.println("");
  bufferTwo[0] = first;
  for (uint8_t i=0; i<31; i++) {
    bufferTwo[i+1]=buffer[i];
  }
//  Serial.println("");
//  Serial.println("finished buffer two:");
//  for (uint8_t i=0; i<32; i++) {
//    Serial.print("0x"); Serial.print(bufferTwo[i], HEX); Serial.print(", ");
//  }
//  Serial.println("");
//  Serial.println("Done buffer stuff");
//  Serial.println("");
   //get checksum ready
  for (uint8_t i=0; i<30; i++) {
    sum += bufferTwo[i];
  }
 
  /* debugging
  for (uint8_t i=2; i<32; i++) {
    Serial.print("0x"); Serial.print(buffer[i], HEX); Serial.print(", ");
  }
  Serial.println();
  */
  
  // The data comes in endian'd, this solves it so it works on all platforms
  uint16_t buffer_u16[15];
  for (uint8_t i=0; i<15; i++) {
    buffer_u16[i] = bufferTwo[2 + i*2 + 1];
    buffer_u16[i] += (bufferTwo[2 + i*2] << 8);
  }
  /*
  for (uint8_t i=0; i<15; i++) {
    Serial.print("0x"); Serial.print(buffer_u16[i], HEX); Serial.print(", ");
  }
  */
 
  // put it into a nice struct :)
  memcpy((void *)&data, (void *)buffer_u16, 30);
 
  if (sum != data.checksum) {
    Serial.println("Checksum failure");
    return false;
  }
  
  // success!
  
  return true;
}

int i = 1;

//MAIN LOOP
void loop() {
    int response = Serial.read();

    if (response == 102){ // "f" means fail
      Serial.println("Serial port reset...");
      digitalWrite(resetPin, LOW);
      delay(20);
      digitalWrite(resetPin, HIGH);
      delay(200);
    } else if (response == 103) { // "g" means good
      print_lidar();
      start_sensor();
      print_sonar();

      //PMS sensor code
      if (curr == 0){
        one.listen();
        delay(200);
      }
  if (readPMSdata(&one)) {
    if (debug) {
        Serial.println("------------PMS@Pin10------------------");
     }
     curr = 1;
     //copies sensor data to backup struct
     firstData = data;
  }
  if (curr == 1) {
    two.listen();
    delay(200); 
  }
  if (readPMSdata(&two)) {
      // reading data was successful!
      if (debug) {
        Serial.println("------------PMS@Pin11------------------");
      }
      curr = 0;
      //printJSON();
      JSONready = true;
  }

  //end PMS sensor code
  
      if (i%5 == 0){
        print_gas();
        //old PM code
        if (JSONready) {
          printJSON();
        }
        //print_pm();
        i=1;
      }
      i++;
      Serial.println();
    } else {
      delay(200);
    }
    delay(20);
}

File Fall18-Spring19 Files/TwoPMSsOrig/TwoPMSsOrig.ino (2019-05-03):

// On Leonardo/Micro or others with hardware serial, use those!
// uncomment this line:
// #define pmsSerial Serial1
 
// For UNO and others without hardware serial, we must use software serial...
// pin #2 is IN from sensor (TX pin on sensor), leave pin #3 disconnected
// comment these two lines if using hardware serial
#include <SoftwareSerial.h>
SoftwareSerial one(10, 3);
SoftwareSerial two(11,4);
uint16_t curr = 0;
//change to true if you would like to see adafruit's original output
boolean debug = false;
 
void setup() {

  // our debugging output
  Serial.begin(115200);
  //TAKE OUT BEFORE IMPLEMENTING
  while (!Serial) {
    ;
  }
  
  //TAKE OUT ABOVE BEFORE IMPLEMENTING
  // sensor baud rate is 9600
  one.begin(9600);
  two.begin(9600);

}
 
struct pms5003data {
  uint16_t framelen;
  uint16_t pm10_standard, pm25_standard, pm100_standard;
  uint16_t pm10_env, pm25_env, pm100_env;
  uint16_t particles_03um, particles_05um, particles_10um, particles_25um, particles_50um, particles_100um;
  uint16_t unused;
  uint16_t checksum;
};
 
struct pms5003data data;
struct pms5003data firstData;
    
void loop() {
  //Serial.println("Curr:");
  //Serial.print(curr);
  if (curr == 0){
    one.listen();
  }
  if (readPMSdata(&one)) {
    if (debug) {
        Serial.println();
        Serial.println("---------------------------------------");
        Serial.println("------------PMS@Pin10------------------");
        Serial.println("Concentration Units (standard)");
        Serial.print("PM 1.0: "); Serial.print(data.pm10_standard);
        Serial.print("\t\tPM 2.5: "); Serial.print(data.pm25_standard);
        Serial.print("\t\tPM 10: "); Serial.println(data.pm100_standard);
        Serial.println("---------------------------------------");
        Serial.println("Concentration Units (environmental)");
        Serial.print("PM 1.0: "); Serial.print(data.pm10_env);
        Serial.print("\t\tPM 2.5: "); Serial.print(data.pm25_env);
        Serial.print("\t\tPM 10: "); Serial.println(data.pm100_env);
        Serial.println("---------------------------------------");
        Serial.print("Particles > 0.3um / 0.1L air:"); Serial.println(data.particles_03um);
        Serial.print("Particles > 0.5um / 0.1L air:"); Serial.println(data.particles_05um);
        Serial.print("Particles > 1.0um / 0.1L air:"); Serial.println(data.particles_10um);
        Serial.print("Particles > 2.5um / 0.1L air:"); Serial.println(data.particles_25um);
        Serial.print("Particles > 5.0um / 0.1L air:"); Serial.println(data.particles_50um);
        Serial.print("Particles > 50 um / 0.1L air:"); Serial.println(data.particles_100um);
        Serial.println("---------------------------------------");
     }
     curr = 1;
     firstData = data;
  }
  if (curr == 1) {
    two.listen();
  }
  if (readPMSdata(&two)) {
      // reading data was successful!
      if (debug) {
        Serial.println();
        Serial.println("---------------------------------------");
        Serial.println("------------PMS@Pin11------------------");
        Serial.println("Concentration Units (standard)");
        Serial.print("PM 1.0: "); Serial.print(data.pm10_standard);
        Serial.print("\t\tPM 2.5: "); Serial.print(data.pm25_standard);
        Serial.print("\t\tPM 10: "); Serial.println(data.pm100_standard);
        Serial.println("---------------------------------------");
        Serial.println("Concentration Units (environmental)");
        Serial.print("PM 1.0: "); Serial.print(data.pm10_env);
        Serial.print("\t\tPM 2.5: "); Serial.print(data.pm25_env);
        Serial.print("\t\tPM 10: "); Serial.println(data.pm100_env);
        Serial.println("---------------------------------------");
        Serial.print("Particles > 0.3um / 0.1L air:"); Serial.println(data.particles_03um);
        Serial.print("Particles > 0.5um / 0.1L air:"); Serial.println(data.particles_05um);
        Serial.print("Particles > 1.0um / 0.1L air:"); Serial.println(data.particles_10um);
        Serial.print("Particles > 2.5um / 0.1L air:"); Serial.println(data.particles_25um);
        Serial.print("Particles > 5.0um / 0.1L air:"); Serial.println(data.particles_50um);
        Serial.print("Particles > 50 um / 0.1L air:"); Serial.println(data.particles_100um);
        Serial.println("---------------------------------------");
      }
      curr = 0;
      printJSON();
  }
}

void printJSON(){

  Serial.print("{'PMS1' : {'pm10_standard' : '"); Serial.print(firstData.pm10_standard); Serial.println("',");
  Serial.print(" 'pm25_standard' : '"); Serial.print(firstData.pm25_standard); Serial.println("',");
  Serial.print(" 'pm100_standard' : '"); Serial.print(firstData.pm100_standard); Serial.println("',");

  Serial.print(" 'pm10_env' : '"); Serial.print(firstData.pm10_env); Serial.println("',");
  Serial.print(" 'pm25_env' : '"); Serial.print(firstData.pm25_env); Serial.println("',");
  Serial.print(" 'pm100_env' : '"); Serial.print(firstData.pm100_env); Serial.println("',");

  Serial.print(" 'particles_03um' : '"); Serial.print(firstData.particles_03um); Serial.println("',");
  Serial.print(" 'particles_05um' : '"); Serial.print(firstData.particles_05um); Serial.println("',");
  Serial.print(" 'particles_10um' : '"); Serial.print(firstData.particles_10um); Serial.println("',");
  Serial.print(" 'particles_25um' : '"); Serial.print(firstData.particles_25um); Serial.println("',");
  Serial.print(" 'particles_50um' : '"); Serial.print(firstData.particles_50um); Serial.println("',");
  Serial.print(" 'particles_100um' : '"); Serial.print(firstData.particles_100um); Serial.println("'},");
      
  Serial.print("'PMS2' : {'pm10_standard' : '"); Serial.print(data.pm10_standard); Serial.println("',");
  Serial.print(" 'pm25_standard' : '"); Serial.print(data.pm25_standard); Serial.println("',");
  Serial.print(" 'pm100_standard' : '"); Serial.print(data.pm100_standard); Serial.println("',");

  Serial.print(" 'pm10_env' : '"); Serial.print(data.pm10_env); Serial.println("',");
  Serial.print(" 'pm25_env' : '"); Serial.print(data.pm25_env); Serial.println("',");
  Serial.print(" 'pm100_env' : '"); Serial.print(data.pm100_env); Serial.println("',");

  Serial.print(" 'particles_03um' : '"); Serial.print(data.particles_03um); Serial.println("',");
  Serial.print(" 'particles_05um' : '"); Serial.print(data.particles_05um); Serial.println("',");
  Serial.print(" 'particles_10um' : '"); Serial.print(data.particles_10um); Serial.println("',");
  Serial.print(" 'particles_25um' : '"); Serial.print(data.particles_25um); Serial.println("',");
  Serial.print(" 'particles_50um' : '"); Serial.print(data.particles_50um); Serial.println("',");
  Serial.print(" 'particles_100um' : '"); Serial.print(data.particles_100um); Serial.println("'}}");
  Serial.println("");
}
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

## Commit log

2017-04-22 Surface quality initial commit - package.json has all the Node modules needed - *_server.js scripts are NodeJS clients that send the server data - added data cleanup script, output CSV, tableau analy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
    [MATRIX Creator Case Bottom.stl, PS3eye+laser.stl, bottom_mount.STL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]
2017-04-22 Added more images GoPro straight mount STL
    [GopPro_Straight_Mount.A.3.stl]
2017-04-24 Proximity files
    All the source code used by the proximity team to collect data from
    ultrasound and lidar sensors.
    [data_04-10-2017-17-32-04.csv]
2017-05-17 Adjusted error message & updated readme
    [bootScript.py]
2017-05-25 Re-org
    Major reorg of each component. Re-writing code for AQ.
    [GasPCB-B.Cu.gbr, GasPCB-B.Mask.gbr, GasPCB-B.SilkS.gbr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]
2017-05-31 Python scripts that operate sensors on the Matrix board
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2017-06-12 changes in Arduino files
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2017-06-15 LED enabled. Serial communication refined
2017-06-16 GPS and Sensors work together (+ LEDs)
2017-06-16 LED complete. All sensors work together fine. Sensor resolution adjusted
2017-06-27 Reset functionality implemented in Raspberry Pi and Arduion. Sync issue resolved. USB ports fixed for serial communications
    [arduino_receiver.py, oneArduinoAllAggregated.ino, server_opt.py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]
2017-06-27 sample 10 min data
2017-07-05 Pi's GPS and Arduino code re-factored
    [preserver_gas_raw.csv]
2017-07-07 Gas sensor testbed added
    [GasPCB-B.Cu.gbr, GasPCB-B.Mask.gbr, GasPCB-B.SilkS.gbr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]
2017-07-07 a new gas calibration data
    [preserver_gas_2_boards.csv]
2017-07-11 gas boards 4,5,7 added
    [board_457.csv, preserver_gas_2_boards.csv]
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2017-07-14 sample data and elevation calculation script added
    [coord.csv]
2017-07-15 Time-series speed graph
    [id.csv]
2017-07-18 Arduino sync issue resolved
    [arduino_receiver.py, server_opt.py]
2017-07-18 parameter changed. official gas station data added
    [official_gas_station_data.xlsx]
2017-07-18 CO and SO2 added
    [official_CO_SO2.xlsx]
2017-07-19 Proximity signatures added
    [2 cars on RS.csv, Bike passby Opp dir LS1m.csv, Buffered Bikelane.csv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]
2017-07-19 Signature data with corrected sonar sensors
    [oneArduinoAllAggregated.ino]
2017-07-20 added 0719 riding for signatures
    [fast_as_possilbe_GPS.csv, official_CO_SO2.xlsx, official_agg.csv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]
2017-07-20 proximity data updated for 0719
    [Sensor_190717.csv, prox_gps_join.csv, proximity_190717.csv]
2017-07-21 graphs and new sig data
    [170720_gps_noel.csv, 170720_gps_noel_jeremy.csv, 170720_proximity_noel.csv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]
2017-07-21 gas joined
    [prox_gps_join.csv]
2017-07-21 gas aggregated to 0718 data
    [prox_gps_join.csv]
2017-07-21 Prox and GPS joined for Jeremy's 0721:
    [210717_gps.csv, prox_gps_join.csv]
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2017-07-22 Mariam's 0720 joined data
    [200717_prox_gps_join.csv]
2017-07-22 Javier's 0722
    [220717_gps.csv]
2017-07-22 0722 Javier's Join table
    [0722_prox_gps_join.csv]
2017-07-22 Updated Signatures
    [Back Noise LS_1.csv, Back Noise LS_2.csv, Back Noise LS_3.csv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]
2017-07-22 Use These (Updated)
    [2 cars Red Light LS parallel.csv, 3 Parking lot cars facing (2m3m).csv, Back Noise LS_1.csv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]
2017-07-22 deleted unnecessary files
    [2 cars Red Light LS parallel.csv, 2 consecutive poles.csv, 2consecutive cars 2+4m.csv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]
2017-07-22 Signatures added
    [signature_prox_gps_join.csv]
2017-07-22 0722 Signatures Added
    [Back Noise LS_1.csv, Car LS 1m_1.csv, Car LS 1m_2.csv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]
2017-07-22 deleted a folder
    [220717_prox.csv, Back Noise LS_1.csv, Car LS 1m_1.csv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]
2017-07-22 0722 Signatures
    [Back Noise LS_1.csv, Car LS 1m_1.csv, Car LS 1m_2.csv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]
2017-07-23 distance-based data
    [220717_first_part_distance_based.csv]
2017-07-23 Classifier added
    [0722_signature_prox_gps_join.csv]
2017-07-23 csv clean up
    [230717_gps_data.csv]
2017-07-23 gps proximity joined for the same route riding 0722
    [230717_prox_gps_join.csv]
2017-07-23 change of locations
    [0722_signature_prox_gps_join.csv]
2017-07-23 distance-based resampling
    [220717_first_part_interpolated_lidars.csv, 220717_first_part_resampled_lidars.csv]
2017-07-24 first part of 0722, resampled for all variables
    [220717_first_part_resampled.csv, 220717_first_part_resampled_lidars.csv]
2017-07-24 random classifires added for testing
    [220717_first_part_resampled_random.csv]
2017-07-24 random classifiers for both sides
    [220717_first_part_gaussian.csv, 220717_first_part_resampled_random.csv]
2017-07-24 day-time added
    [0722_prox_gps_join.csv, Back Noise.csv]
2017-07-24 classification data
    [220717_dist_classifications.csv, 220717_time_classifications.csv]
2017-07-24 data processing graphs
    [Human LS.csv]
2017-07-25 Readme for the front page
    [GopPro_Straight_Mount.A.3.stl, MATRIX Creator Case Bottom.stl, PS3eye+laser.stl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]
2017-07-28 imgs and folders for PCB
    [PCB_BackBox_2layers.fzz]
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2017-07-28 Added Case folder
    [BackBox.dxf, Box.SLDPRT, MatrixBaseMount.SLDPRT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]
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2019-05-03 All Scripts Created Fall 18 - Spring 19
    All of the scripts created from Fall 2018 to Spring 2019 are included along with a readme that explains how to run them and what they are for.
2020-04-13 Create README.md
    Documentation for Spring 2020 Capstone project for The Woodruff Group
2020-04-14 Enlarged button text size
2020-04-24 Added electrical files and documentation
    [SLaB.brd, SLaB.sch]
2020-04-30 feat: add wjmy
    [10 PORT HEADER.SLDPRT, 102 RESISTOR PACK.SLDPRT, 103 RESISTOR PACK.SLDPRT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]
